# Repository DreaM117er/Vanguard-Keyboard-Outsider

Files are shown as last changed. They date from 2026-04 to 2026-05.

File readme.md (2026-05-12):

# Vanguard Keyboard Outsider 先鋒二號局外者

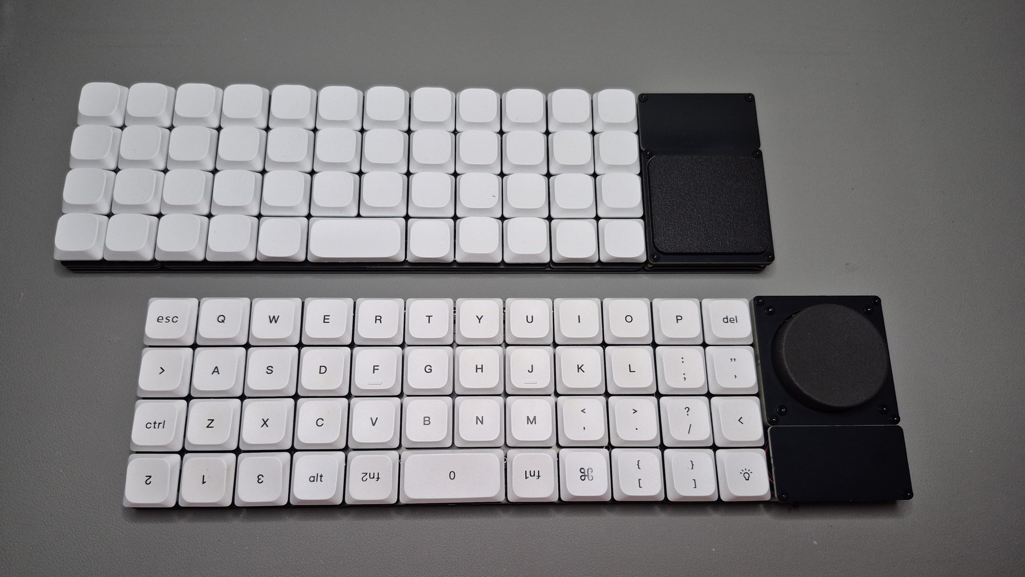
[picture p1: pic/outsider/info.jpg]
info


<br>

## 前言

「先鋒系列」是我個人基於「探索者三號」開發架構上的一個分支點，因爲在探索者三號的設計裡，在探索者三號的設計中，我將鍵盤主控區域「模組化」，使其觸控板與 `ProMicro` 主控模組能徹底沿用至後續作品。

- 爲什麼這把鍵盤是二號？

先鋒一號的代號叫做 `Mono`，中文代號叫做「雙子姐妹」，考慮到有人在敲碗 zmk 韌體的開發，因此我另開了一把鍵盤先嘗試研究 zmk，順勢做出一套屬於無線版的韌體，成功之後就會回頭將「一號」的開發完成。

——當然還有「探索者三號」的 `v2` 及無線韌體版本開發。

因爲是基於「探索者系列」，先鋒雖然比較侷限在「模組化」的區域做開發，但我不會捨棄掉「探索者」的自由度。相對的，這份自由反而讓我在開發的時候產生錯亂，算是一個小小的意外。

`Plank` 一直都是我非常喜歡的直列始祖，`3` 號也是基於 `Plank` 開發的鍵盤，我的想法很簡單：

——從最原始的開始，就一定會有更好的創意。

<br>

- 輔助搭配：
    - `about-zmk-XXX` 教學文本。
    - `QMK Firmware`：https://qmk.fm/
    - `VIAL`：https://get.vial.today/
    - `ZMK Firmware`：https://zmk.dev/
    - `KLE`：https://www.keyboard-layout-editor.com/#/
    - `nRF Connect SDK`：
        - `Android` 連結：https://play.google.com/store/apps/details?id=no.nordicsemi.android.mcp&pcampaignid=web_share
        - 電腦端：https://www.nordicsemi.com/Products/Development-tools/nrf-connect-for-desktop/download
        - 用於初次藍牙發射訊號捕捉除錯用。
    - `FreeCAD`。

<br>

## 硬體設計

### 自由度及限制

`Outsider` 被我設計成這種獨特的外型的樣子，其中最主要的原因就是「自由度」的保留，那麼它的自由度在哪裡？答案很簡單——

——它可以「任意」翻轉使用。

然後它是基於探索者三號的延伸設計，也就是說它的主控區域是沿用下來的，材料清單將註明哪些組件直接沿用「探索者三號」的設計圖資。

<br>

太極理論有「物極必反」的核心概念，任何的設計上也一樣，這把鍵盤給予了極致的自由度，它「目前」的限制列在下方：
1. 支援焊接。
2. 不支援 `Gateron Low Profile 2.0`，也就是 `GLP2.0`。
3. 觸控板只支援 `QMK` 有線版。

<br>

自由度的部分依據「限制」，列在下方：
1. 支援 `MX` 腳位的「鍵軸」，不限「矮軸」。
2. 支援 `GLP3.0` 矮鍵軸。
3. 支援 `Choc` 腳位的「鍵軸」。
4. 支援全電路板、外殼部件翻轉組裝。
5. 支援 `zmk` 編碼器無線版。
6. 支援 `qmk` `Azoteq TPS43` 及 `Cirque TM040040` 觸控板、編碼器有線版。
7. 支援多配列焊接調整。
8. 支援物理拆板組裝使用。

<br>

### 電路設計

#### 核心電路板

<table>
  <tr>
    <td width="100%">
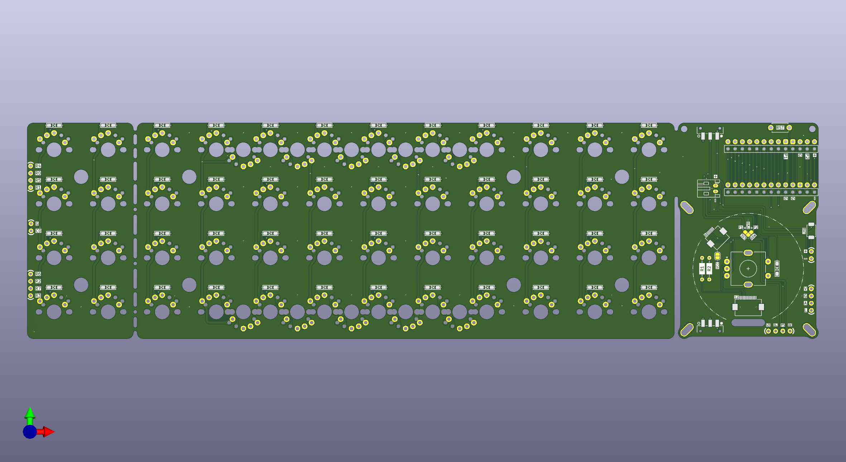
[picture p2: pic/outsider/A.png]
A
      
    </td>
  </tr>
  <tr>
    <td width="100%">
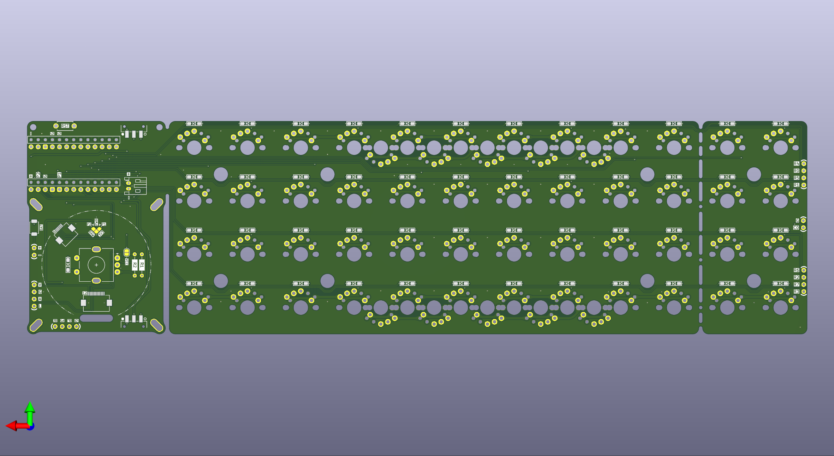
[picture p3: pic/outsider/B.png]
B
      
    </td>
  </tr>
</table>

<br>

#### 定位板、主控把擋板及底板

<table>
  <tr>
    <td width="50%">
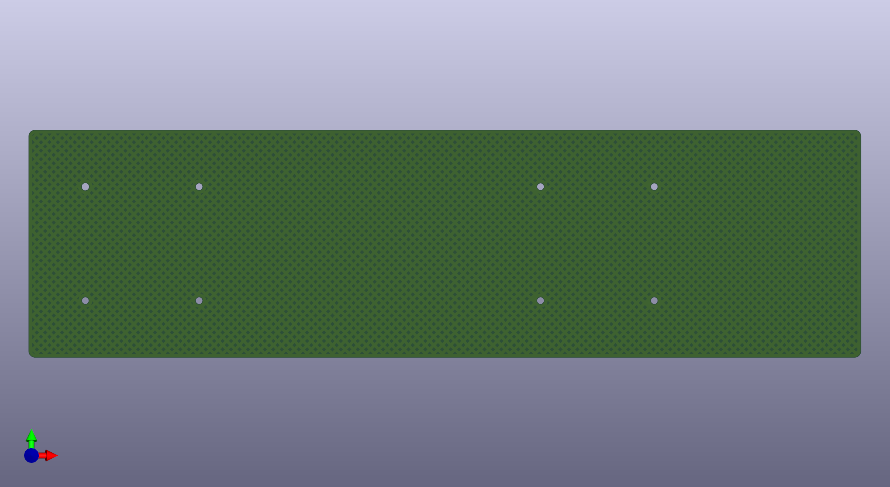
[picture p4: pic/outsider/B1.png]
B1
      
    </td>
    <td width="50%">
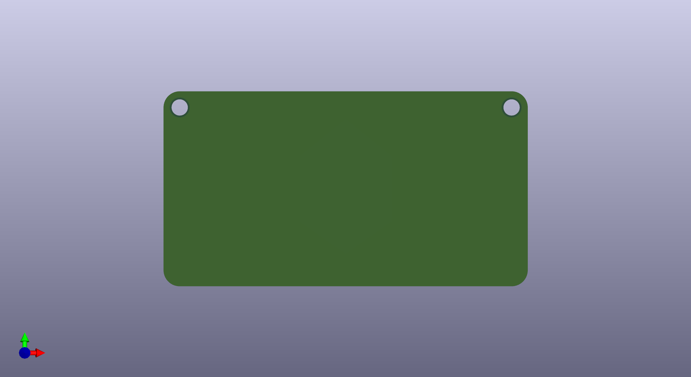
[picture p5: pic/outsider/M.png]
M
      
    </td>
  </tr>
  <tr>
    <td width="50%">
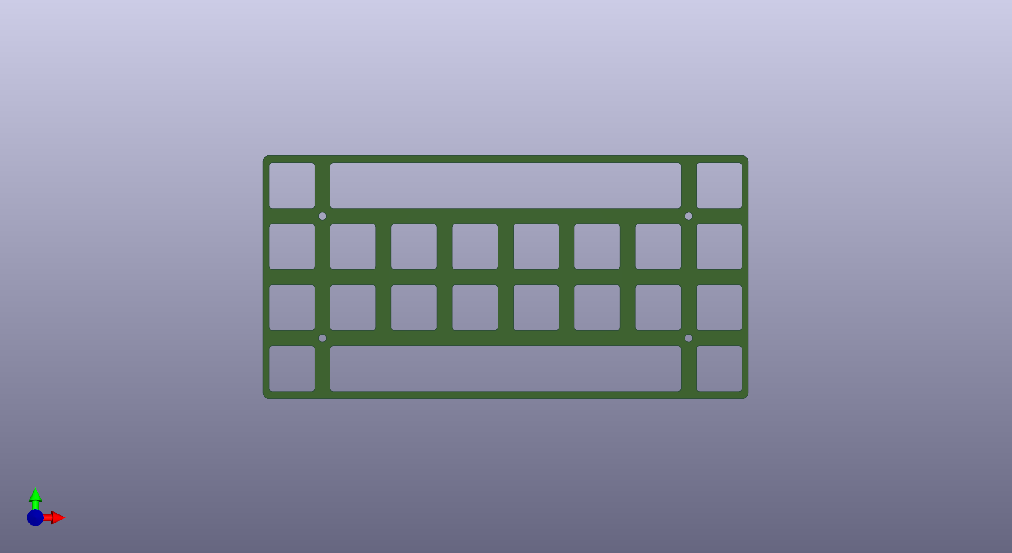
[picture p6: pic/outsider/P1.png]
P1
      
    </td>
    <td width="50%">
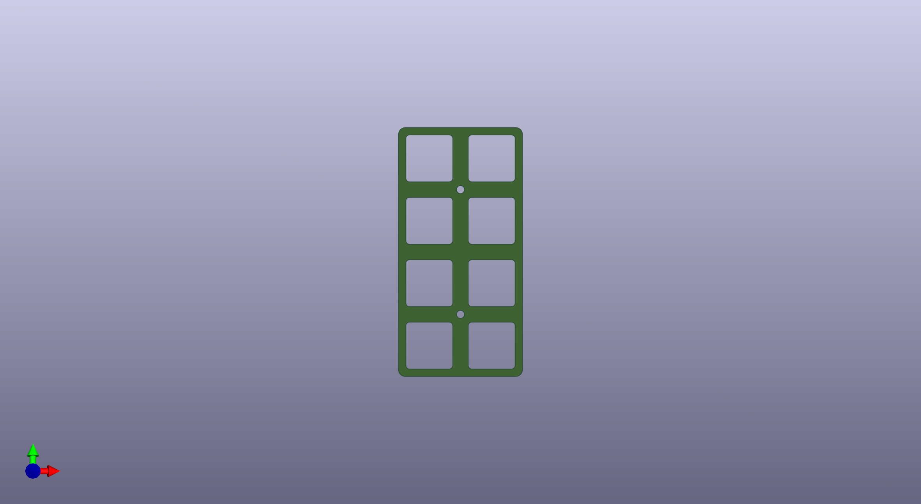
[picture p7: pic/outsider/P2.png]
P2
      
    </td>
  </tr>
</table>

<br>

#### 主控及模組

<table>
  <tr>
    <td width="50%">
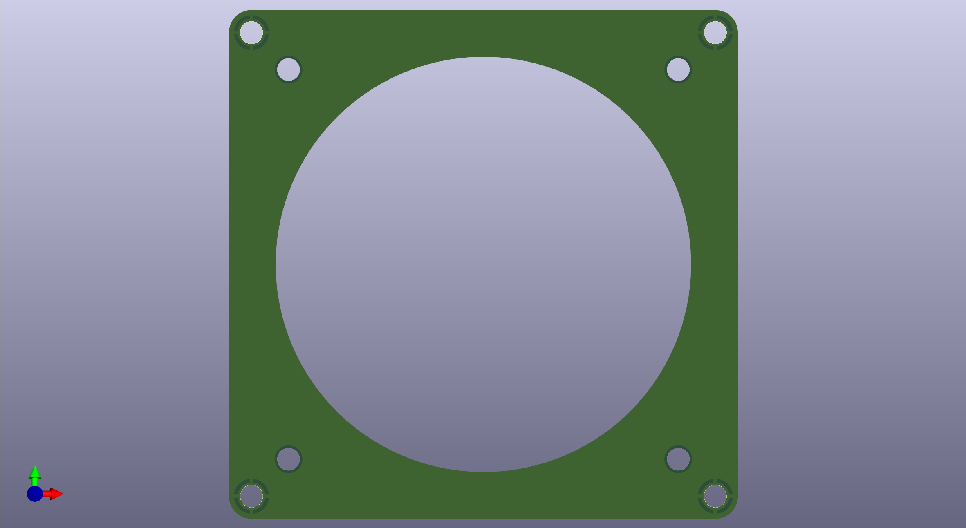
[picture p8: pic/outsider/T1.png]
T1
      
    </td>
    <td width="50%">
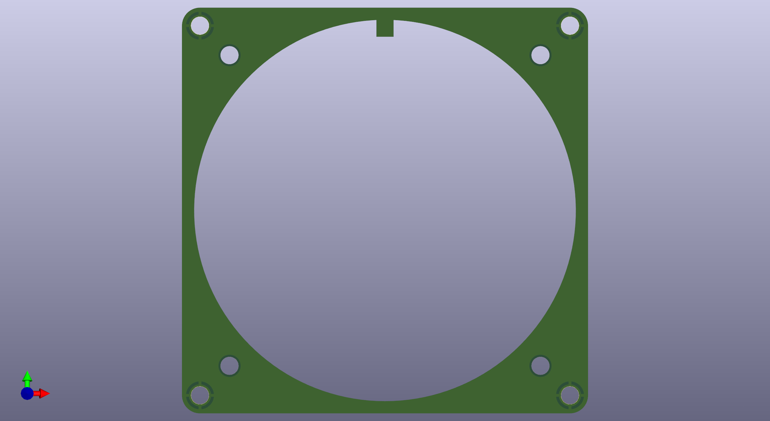
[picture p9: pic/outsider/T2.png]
T2
      
    </td>
  </tr>
  <tr>
    <td width="50%">
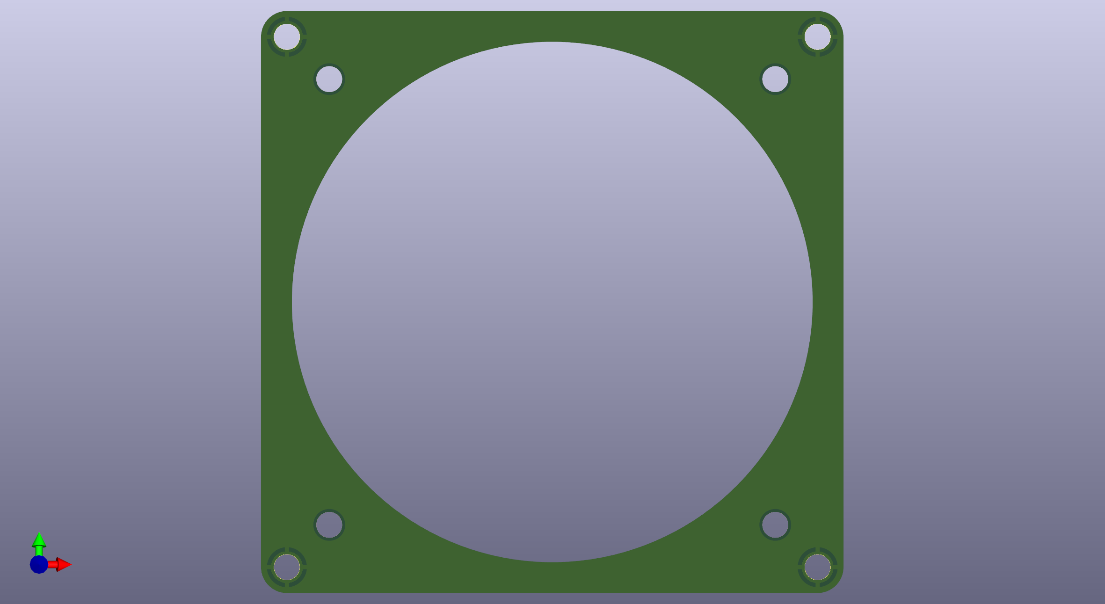
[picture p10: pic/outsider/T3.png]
T3
      
    </td>
    <td width="50%">
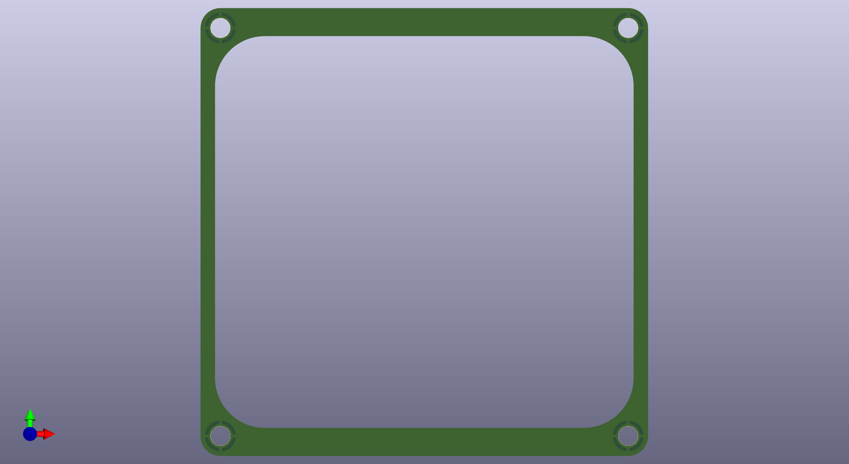
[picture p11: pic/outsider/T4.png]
T4
      
    </td>
  </tr>
</table>

<br>

#### 3D 部件

<table>
  <tr>
    <td width="50%">
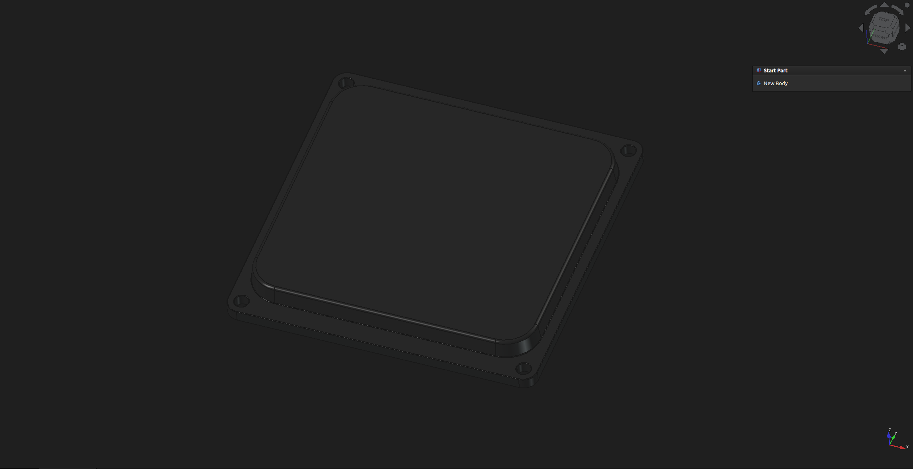
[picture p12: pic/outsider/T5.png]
T5
      
    </td>
    <td width="50%">
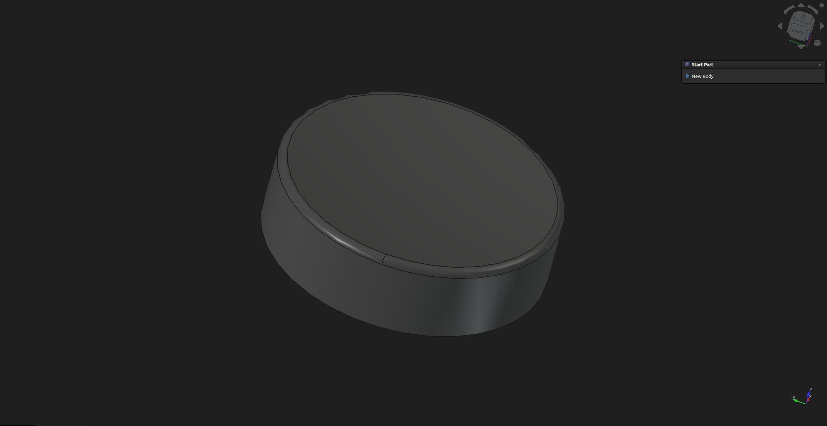
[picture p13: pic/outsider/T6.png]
T6
      
    </td>
  </tr>
</table>

<br>

## 使用材料

使用材料的部分比較簡單，`Outsider` 並沒有做過多的 `3D` 設計，一貫保留「三明治」結構。

||名稱|數量|數量||
|--|--|--|--|--|
|⚠️ **電路板**|**配列**|**4x10**|**4x12**|**備註**|
||主電路板|1|1|厚度 `1.2mm`|
||底板|1|1|厚度 `1.6mm`|
||`4x8` 定位板|1|1|**下方備註**|
||`4x2` 定位板|1|2|**下方備註**|
|`TM040040`|模組 `A`|1|1|**三號部件**|
|`TM040040`|模組 `B`|1|1|**三號部件**|
|`TM040040`|模組 `C`|1|1|**三號部件**|
|`TPS43`|模組 `D`|1|1|**三號部件**|
|⚠️ **主控**|**腳位**||||
|`ATMega32U4`|`ProMicro`|1|1|**基礎有線版**|
|`RP2040`|`ProMicro`|1|1|**有線觸控板**|
|`nRF52840`|`ProMicro`|1|1|**支援旋鈕無線版**|
|⚠️ **電子部件**|**名稱/規格**||||
|`1N4148`|`SOD-123`|40-41|48-49||
|`EC-11`/`EC-12`|`L10mm` `A4.5-5.0mm`|1|1|**選配**|
|輕觸開關|`6x3.5x4.3mm` `2 Pin`|1|1||
|輕觸開關|`SKRK` `2mm`|1|1|**選配**|
|撥動開關|`MSKT-12D14`|1|1|**選配**|
|小於 `501735`|`3.7V` 聚合物鋰電池|1|1|**選配，置於 MCU 上方**|
|-|`3.7V` 鋰電池電量顯示模組|1|1|**選配**|
|`PH2.0` `THT` 公母接頭|`JST PH S2B-PH-K`|1|1|**選配**|
|💡 **TM040040**|||||
|**名稱**|**規格**||||
|觸控板|-|1|1|**選配**|
|電阻|`1/4W` `4.7K`|2|2||
|排線|`0.5x5mm` `FFC 12pin` `AA`|1|1||
|排線座|`0.5mm` `FFC 12pin`|1|1|**不限翻蓋類型**|
|螺絲|`M2x3`|20|24||
|螺絲|`M2x6`|4|4||
|銅柱|`M2x5` `ø3.05-4mm`|6|8|**矮軸高度**|
|銅柱|`M2x6` `ø3.05-4mm`|4|4|**推薦高度**|
|銅柱|`M2x7` `ø3.05-4mm`|2|2|**有線主控**|
|銅柱|`M2x10` `ø3.05-4mm`|2|2|**無線主控**|
|💡 **TPS43**|||||
|觸控板|-|1|1|**選配**|
|排線|`0.5x5mm` `FFC 6pin` `AA`|1|1||
|排線座|`0.5mm` `FFC 6pin`|1|1|**不限翻蓋類型**|
|螺絲|`M2x3`|20|24||
|螺絲|`M2x6`|4|4||
|銅柱|`M2x5` `ø3.05-4mm`|6|8|-|
|銅柱|`M2x6` `ø3.05-4mm`|4|4||
|銅柱|`M2x8` `ø3.05-4mm`|4|4|**推薦高度**|
|銅柱|`M2x7` `ø3.05-4mm`|2|2|**有線主控**|
|銅柱|`M2x10` `ø3.05-4mm`|2|2|**無線主控**|
|📌 **3D 列印部件**|||||
|`TPS43`|觸控接觸面|1|1||
|`EC-11`|`ø39mm`, `L4.5mm` 編碼器帽蓋|1|1||
|📌 **其他**|||||
|自黏貼 `Poron` 棉|厚度 `2mm`|-|-||
|自黏貼矽膠腳貼|`ø8mm` `0.5-1mm`|4|4||

<br>

## 注意事項

### 零部件方面

- 如要安裝 `EC-11` 編碼器，請選擇支援 `TM040040` 的模組。

- 以上銅柱規格以「矮軸」配置為主；若使用標準 `MX` 軸，高度規格需全面調整至至少 `M2x7mm`。

- 定位板標準 `MX` 軸使用厚度 `1.6mm`；矮軸統一使用厚度 `1.2mm`。

- 鍵軸準備「至少」 `40` 或 `48` 顆以上，類型請根據自身喜好做挑選。

<br>

### 組裝方面

- 電烙鐵屬於高熱量操作技術，務必注意用電用火安全。

- 松香、焊錫屬於高毒性物質，務必注意環境通風。

- 操作時建議佩戴手套、口罩及護目鏡，以確保安全。

- 操作技術推薦：
  - 電烙鐵：恆溫控制攝氏 `250`-`330` 度間。
    - `K`。
    - `BC`。
  - 焊錫：攝氏 `183` 度。
  - 電線：
    - 規格至少 `24`-`28` `AWG`。
    - 顏色至少能清晰分辨 `2` 色。

- 操作工具：
  - 壓線鉗：
    - 需要能夠處理 `PH2.0` 規格。
    - 多準備一些金屬端子備用。
    - 先調整壓力卡楯，再做壓製動作。
  - 剝線鉗：
    - 用於鋰電池及其電量顯示模組使用。

- 觸控板選配：
  - `TM040040`：
    - 需要焊接 `4.7K` 電阻。
    - 需要自行移除觸控板上的 `R1` 電阻。
    - 教學參考：
      - [40mm Cirque GlidePoint Circle Trackpad Module DIY Kit for Split Mechanical Keyboard](https://shop.beekeeb.com/product/40mm-cirque-glidepoint-circle-trackpad-module-diy-kit-for-split-mechanical-keyboard/)
      - [GlidePoint Cirque Trackpad TM040040 TM035035](https://keycapsss.com/keyboard-parts/parts/211/glidepoint-cirque-trackpad-tm040040-tm035035)
  - `TPS43`：不需焊接電阻。

<br>

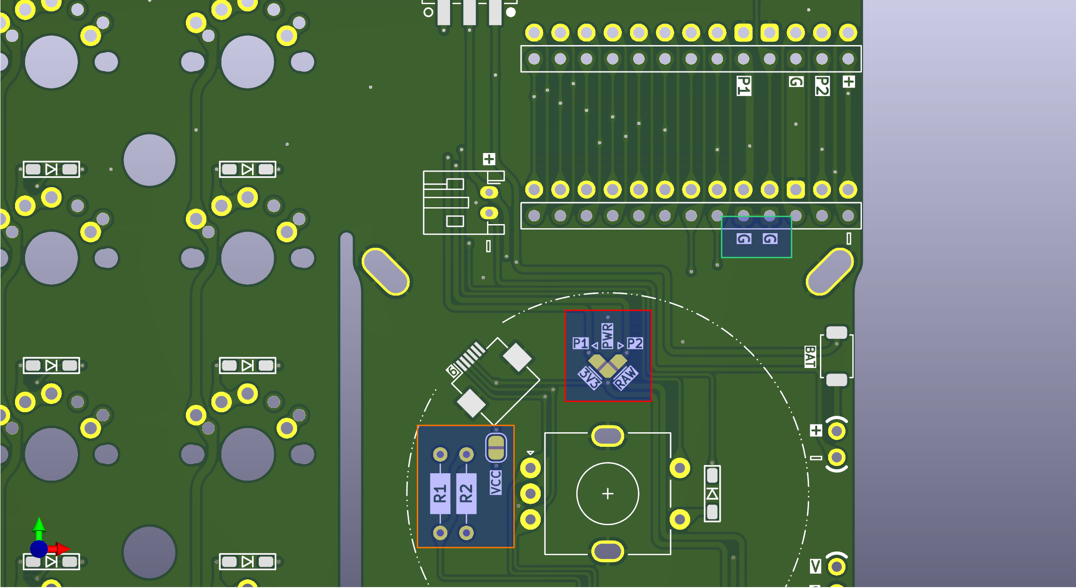
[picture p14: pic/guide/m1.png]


- 關於跳線：
  - 只需要焊接電路板其中一面即可。
  - `PWR`：
    - 一律根據 `MCU` 選擇 `3V3` 供電的位置。
    - 通常 `3V3` 都在 `P1` 的位置上。
  - `VCC`：
    - 使用跳線：組裝 `TM040040` 觸控板時焊上。
    - 不焊跳線：`4.7K` 電阻可不用解下就能將 `TM040040` 更替成 `TPS43`。

<br>

<table>
  <tr>
    <td width="50%">
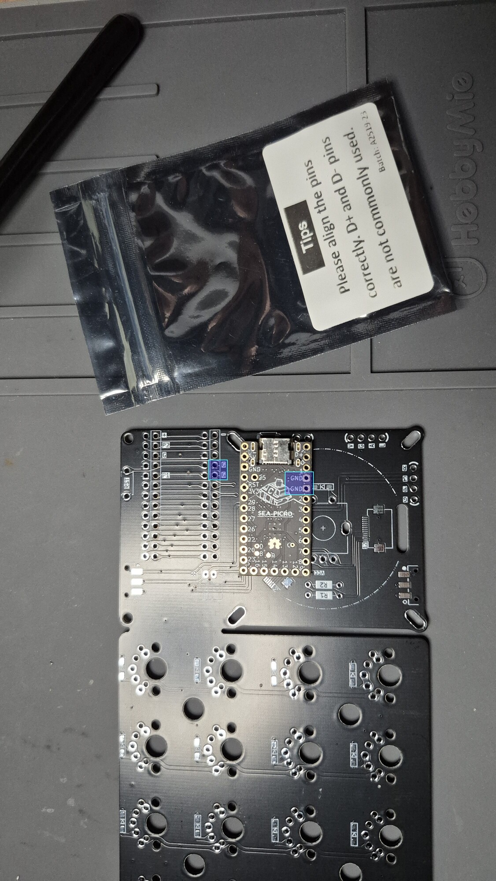
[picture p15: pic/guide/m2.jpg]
m2
      
    </td>
    <td width="50%">
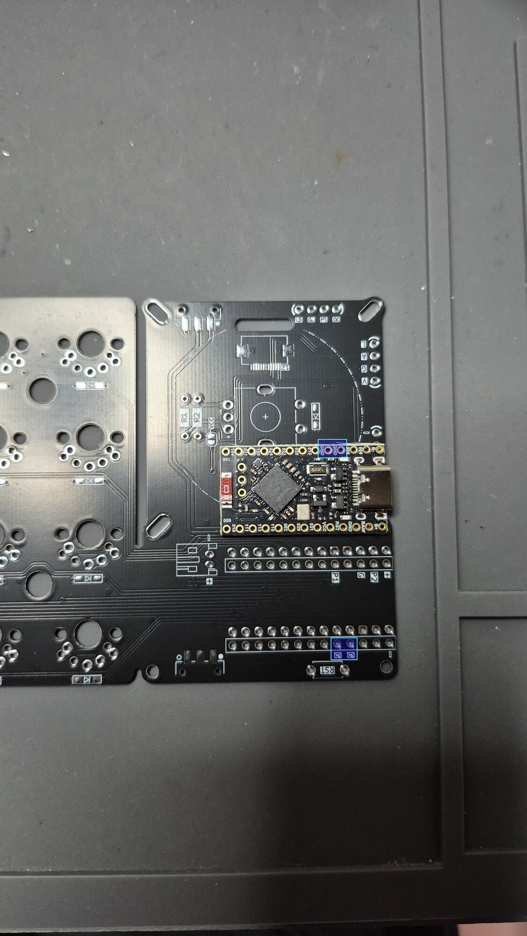
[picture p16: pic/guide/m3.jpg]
m3
      
    </td>
  </tr>
</table>

- 關於 `MCU`：
  - 根據 `MCU` 的腳位圖安裝。
  - 參照上圖「有 `2` 個 `GND`」的方向做判讀比較不容易裝反。

<br>

### 圖標辨識

<table>
  <tr>
    <td width="40%">
      <p>二極體有方向性。</p>
      <p>注意二極體前端的標線。</p>
    </td>
    <td width="30%">
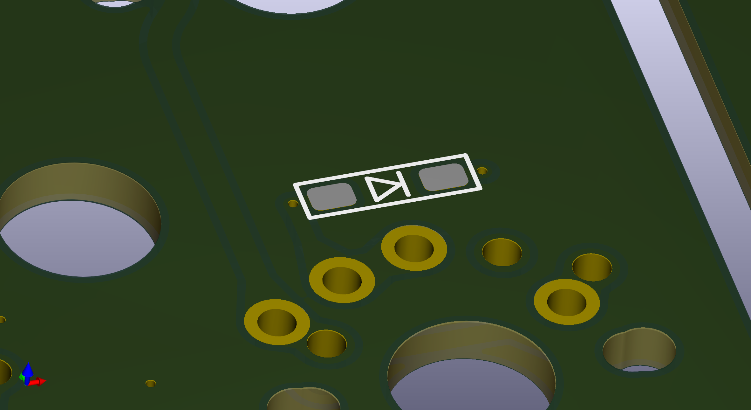
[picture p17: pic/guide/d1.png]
d1
      
    </td>
    <td width="30%">
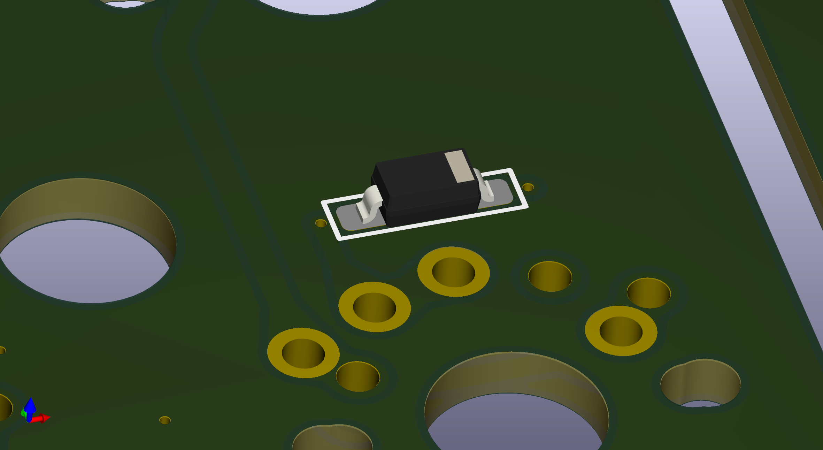
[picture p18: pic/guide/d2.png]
d2
      
    </td>
  </tr>
  <tr>
    <td width="40%">
      <p>電阻不分方向。</p>
      <p>電阻請跟「MCU」一樣安裝在同一面。</p>
    </td>
    <td width="30%">
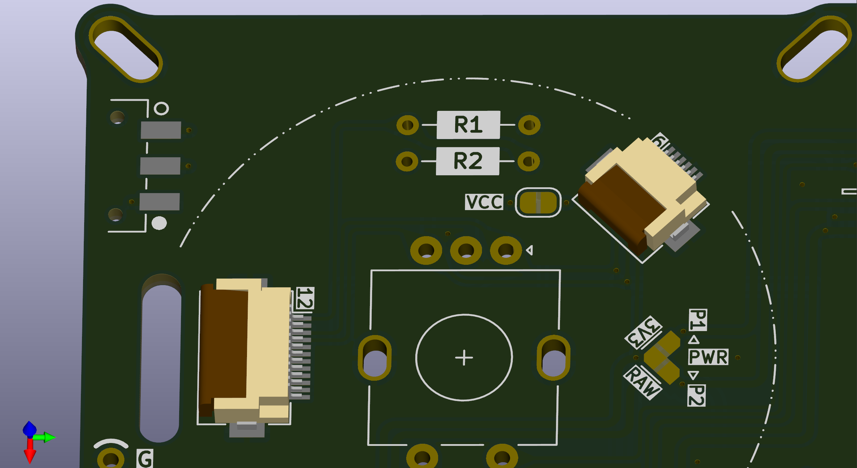
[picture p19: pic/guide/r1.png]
r1
      
    </td>
    <td width="30%">
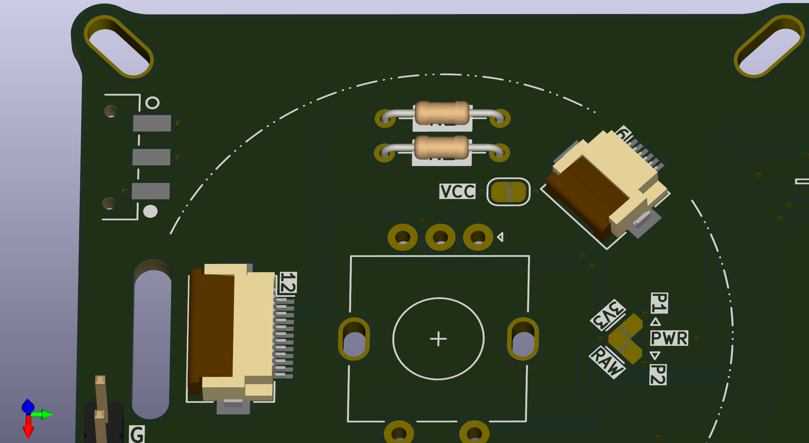
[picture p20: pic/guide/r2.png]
r2
      
    </td>
  </tr>
</table>

<br>

## 組裝方式

閱覽完前述規範後，進入實體組裝階段時，請特別留意以下具備挑戰性的環節：
- 焊接技術：
  - 溫度控制。
  - `3` 秒內原則。
  - `0.5mm` `FFC` 排線座。
- 除錯技術：
  - `0/1` 原則。
  - 防短路原則。

<br>

<table>
  <tr>
    <td width="38%">
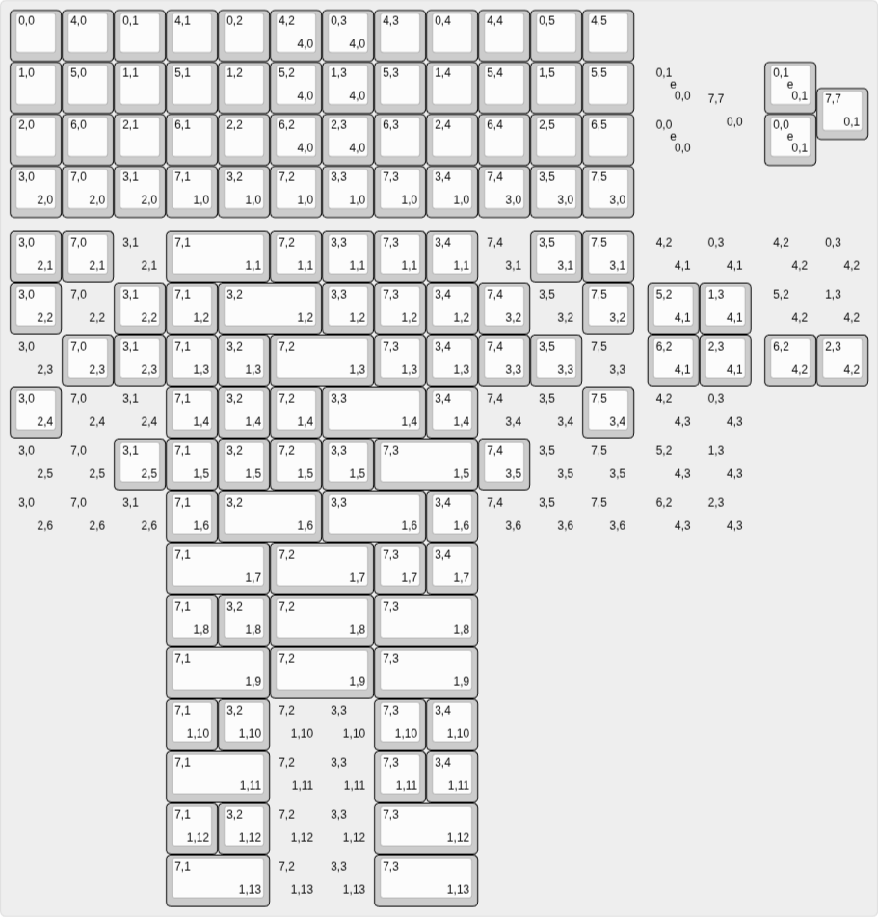
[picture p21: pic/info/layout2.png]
layout2
      
    </td>
    <td width="62%">
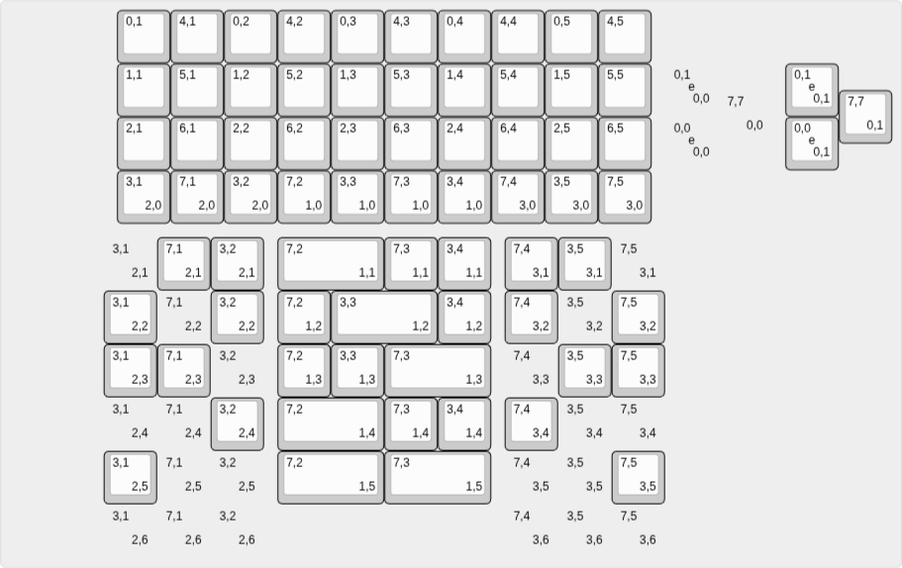
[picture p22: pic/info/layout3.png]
layout3
      
    </td>
  </tr>
</table>

<br>

拿出電路板，然後先思索一下：
  - 配列要長什麼樣子？
  - 鍵盤是有線還是無線驅動？
  - 我能搭載什麼設備？

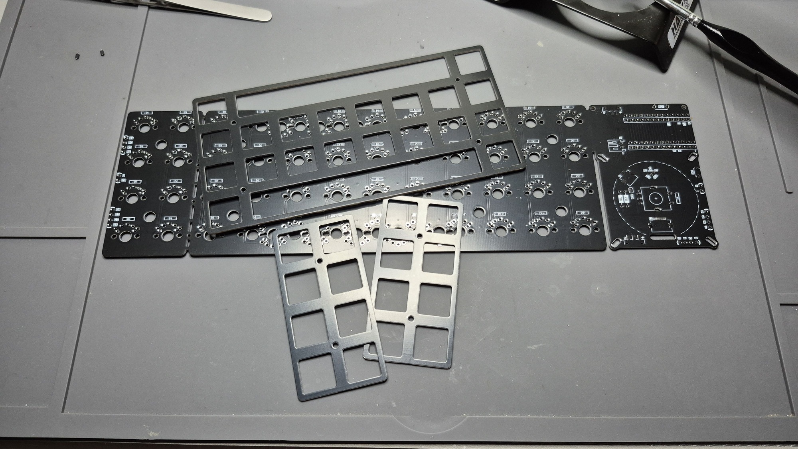
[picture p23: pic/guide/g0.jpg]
g0


<br>

以上問題思索完畢後，就可以開始進入正式組裝。

> 注意：以前我會傾向要大家先燒錄韌體到主控裡面，但這裡我必須做一些小修正。

<br>

### 共通部分

> 注意事項：部分照片有線及無線版本交互在一起使用，但不會影響安裝。

根據你的理想配列，首先將二極體焊上。

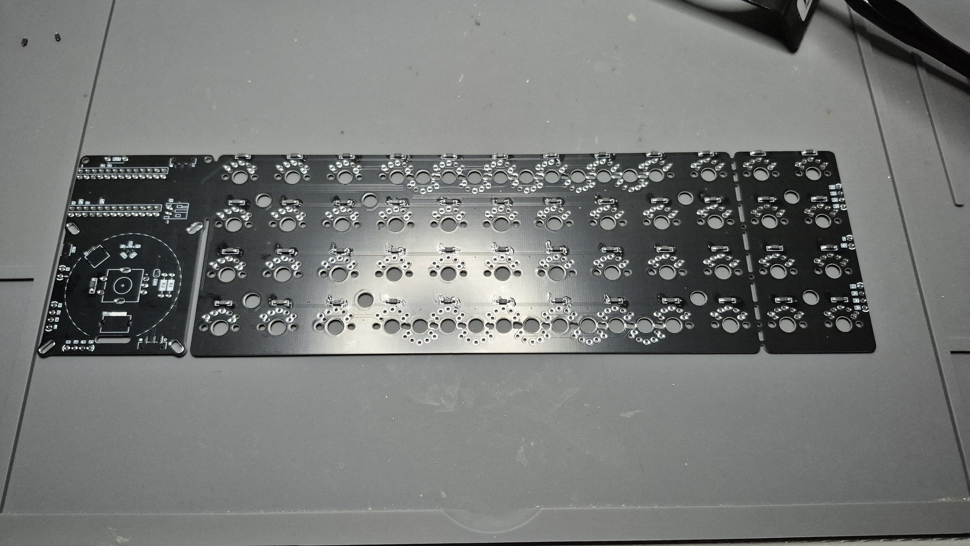
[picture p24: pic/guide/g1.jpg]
g1


<br>

然後將需要用到的週邊元件都焊上：
  - `EC-11` 或觸控板的 `FFC 排線座`、`1/4W 4.7K 電阻`。
  - 跳線。
  - `6x3.5x4.3mm` `2 Pin` 輕觸開關。
  - 無線版本：
    - `MSKT-12D14` 滑動開關。
    - `SKRK` `2mm` 輕觸開關。
    - `PH2.0` 母座。

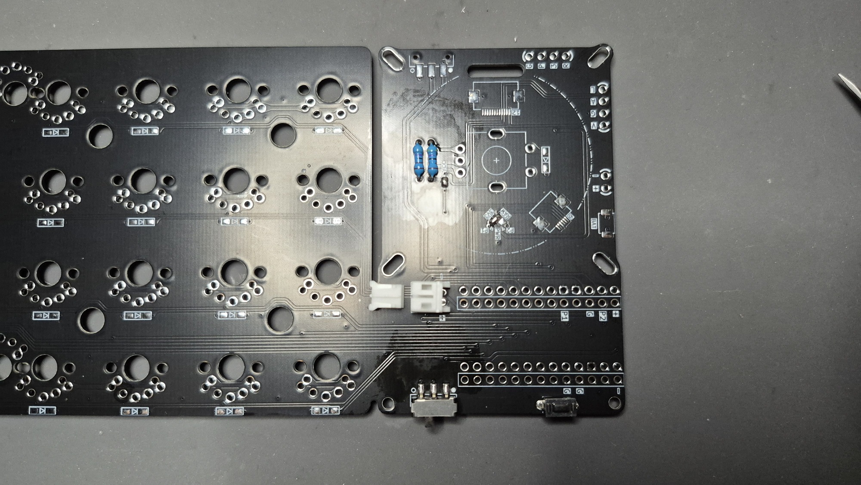
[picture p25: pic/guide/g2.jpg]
g2


<br>

根據你選擇的 `MCU` 來決定是不是要先燒錄韌體還是先焊上去。
- `RP2040`：
  - 大部分版本先做燒錄動作。
  - `Sea-Picro` 可以先焊接固定好之後再燒錄韌體。
  - 燒錄韌體的方式普遍爲「按住 `BOOT` 按鈕」後接上裝置後將 `uf2` 韌體燒錄到內部。
- `nRF52840`：
  - 先焊接固定好之後再燒錄韌體。
  - 接上裝置後，連續觸發「`2` 次」`RST` 按鈕，再將 `uf2` 韌體燒錄到內部。

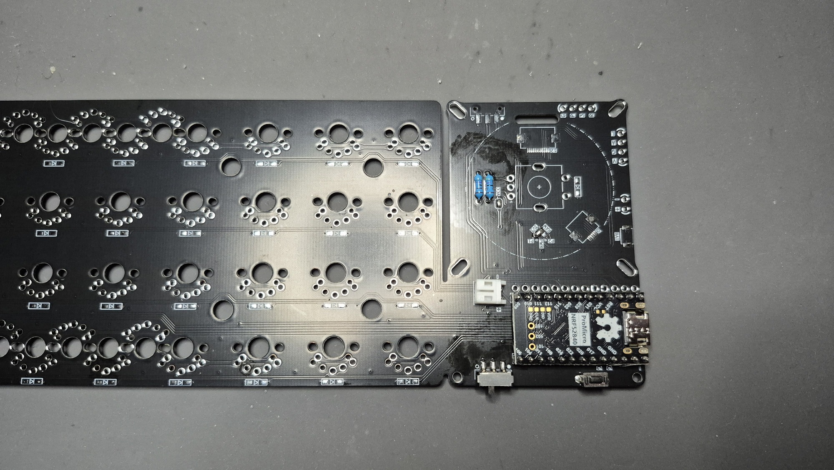
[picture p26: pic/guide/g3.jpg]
g3


<br>

`MCU` 焊接固定好、韌體也燒錄進去之後，下一步不要急著把軸體焊上去，你需要做幾件事情：
1. 確認你的鍵盤矩陣有沒有動，也就是你的按鍵有沒有全部都觸發。
  - `VIAL` 的 `Matrix Tester`。
  - `ZMK Studio`——`about-zmk-XXX` 教學文本會說明。
  - 第三方按鍵檢測器：https://hwtest.in/keyboard
2. 確認你的模組有沒有正常驅動。
  - `EC-11` 編碼器。
  - 觸控板的指向裝置韌體操作。

以上都沒問題，如果你是安裝觸控板，記得先把排線拔下來，再焊接軸體；如果是 `EC-11` 編碼器，就直接焊接軸體。

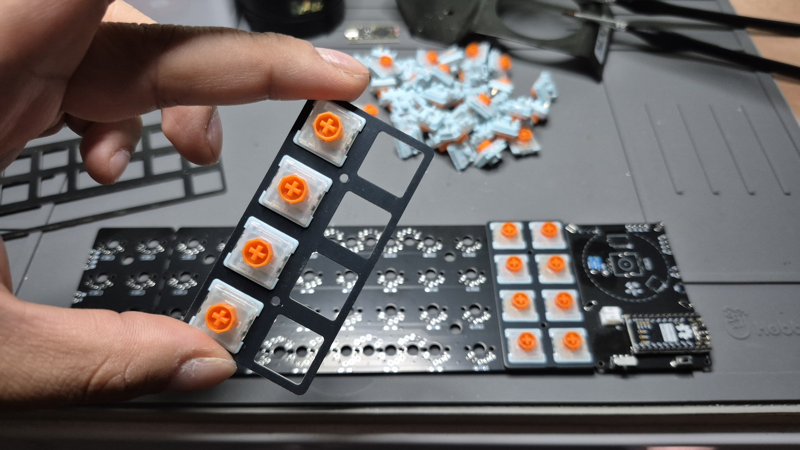
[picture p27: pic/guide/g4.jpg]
g4

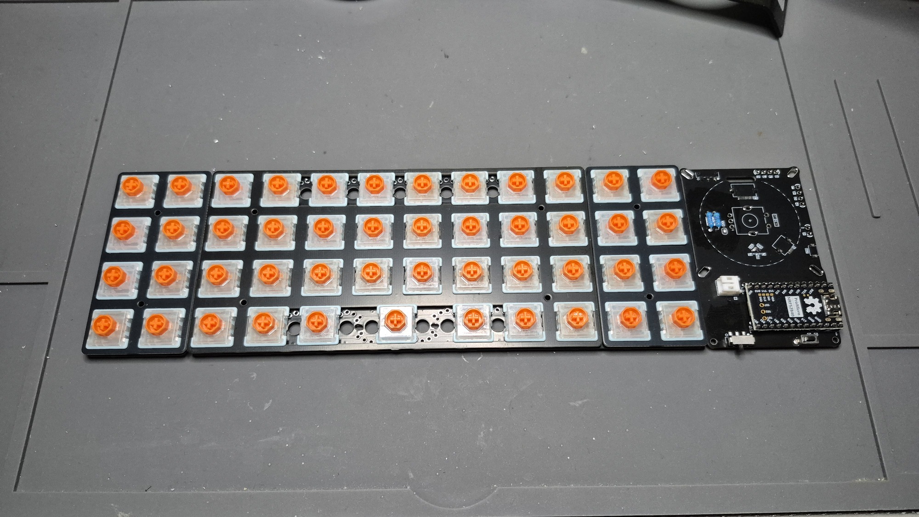
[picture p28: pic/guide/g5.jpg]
g5


> 注意事項：`EC-11` 可以不用焊接就直接裸測，我的照片示意圖裡就是這樣的操作。

<br>

### 觸控板

#### TPS43

`TPS43` 的部分，首先需要準備好「觸控面」、「模組 `D`（框架）」，先將 `TPS43` 上頭的 `3M` 膠帶撕下來，跟觸控面一起結合固定好。

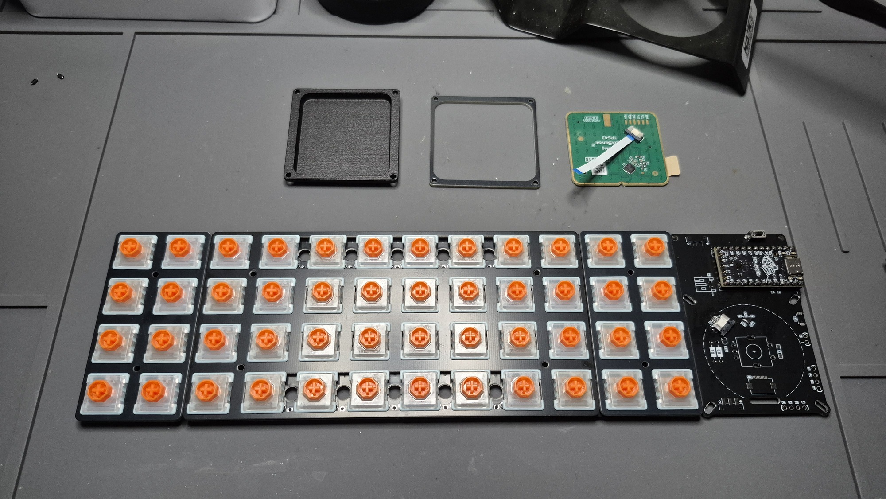
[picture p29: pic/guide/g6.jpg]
g6

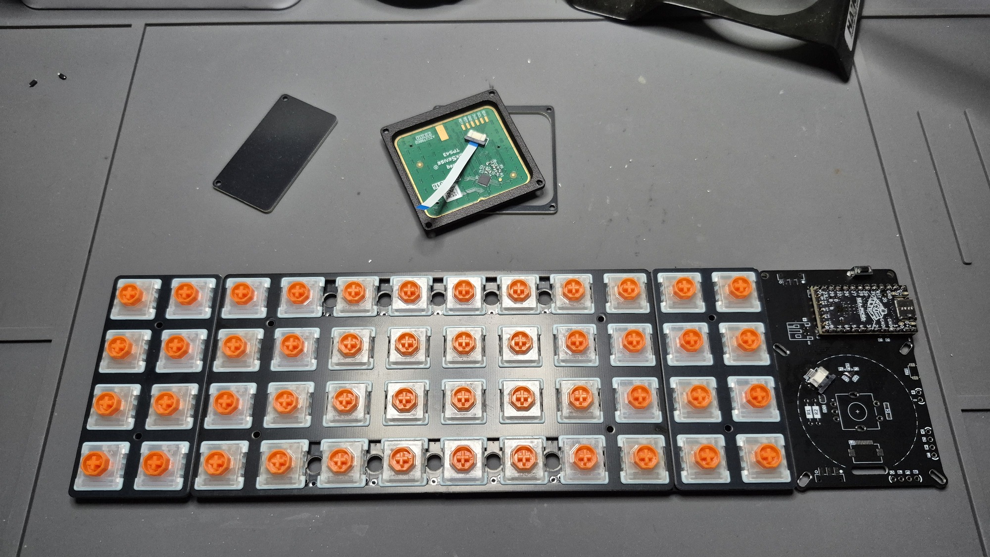
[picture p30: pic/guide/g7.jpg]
g7


<br>

將銅柱安裝在整套模組上之後，接上排線，然後將主控擋板連同模組一起固定好，就可以安裝底板收尾了。

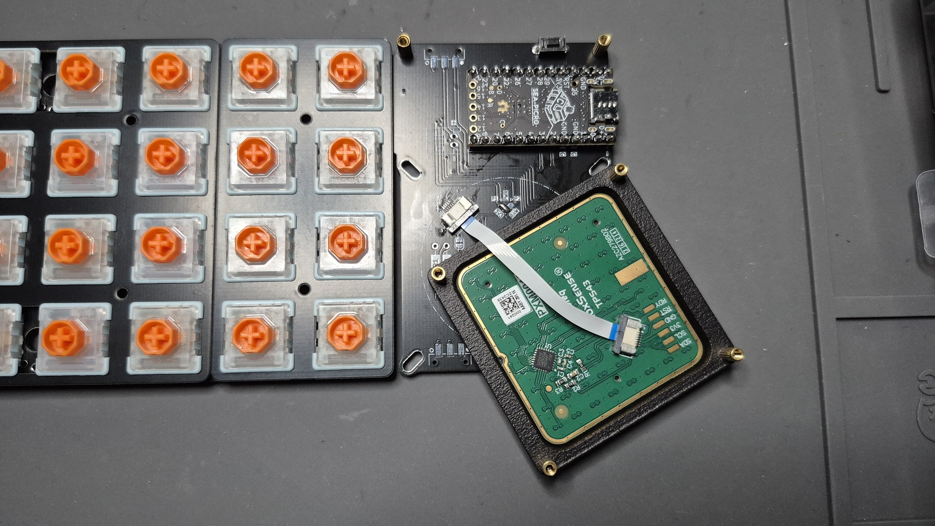
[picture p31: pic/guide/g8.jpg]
g8

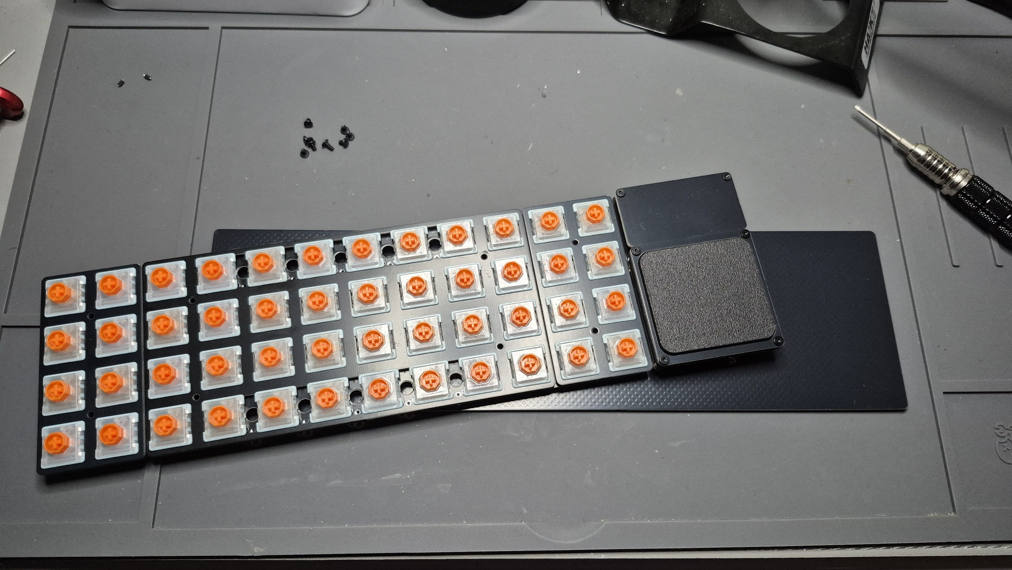
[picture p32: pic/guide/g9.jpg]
g9


<br>

#### TM040040

`TM040040` 的部分，需要將本體跟「模組 `A`、`B`、`C`」先組裝在一起，然後再安裝銅柱完成整套的模組。

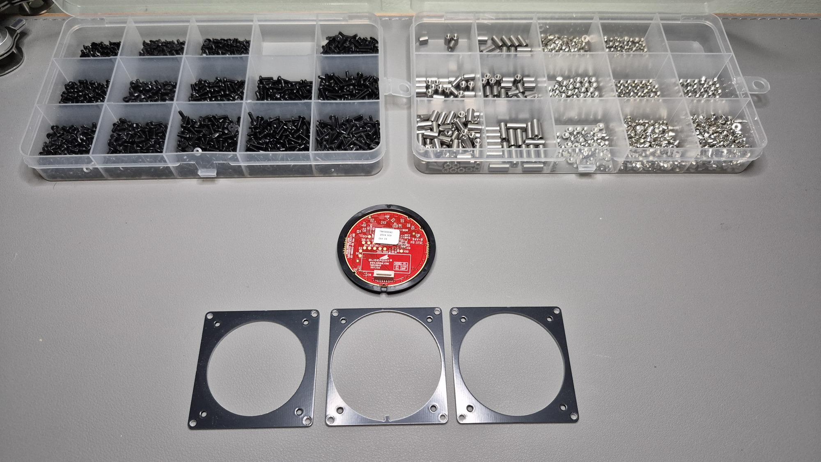
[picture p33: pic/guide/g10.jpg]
g10

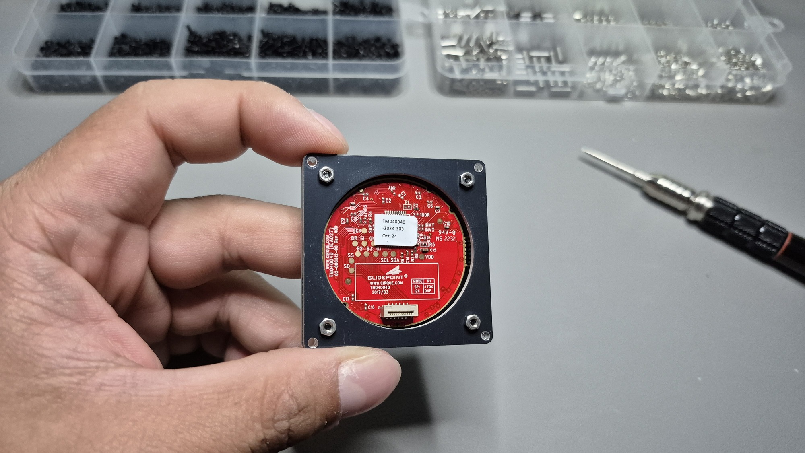
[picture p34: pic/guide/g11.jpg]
g11

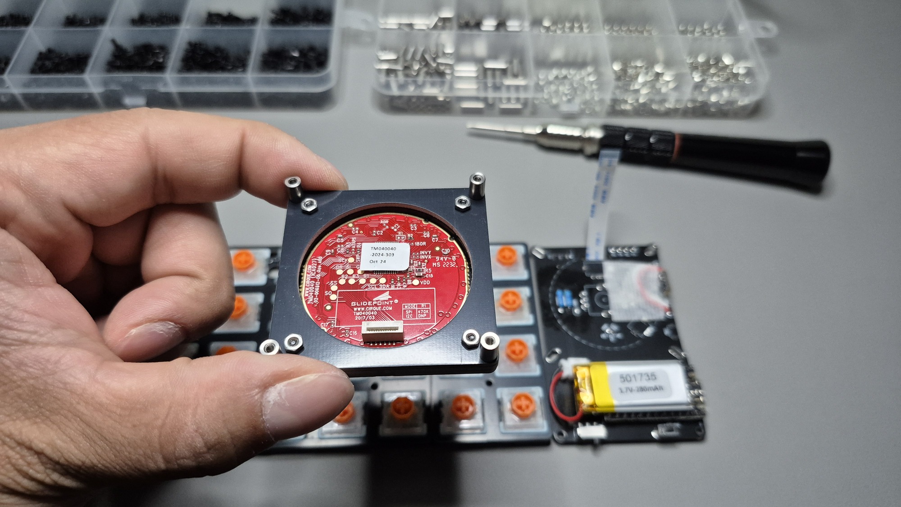
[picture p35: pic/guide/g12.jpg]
g12


<br>

`TM040040` 整套模組的安裝方式，要先將 `5mm` 排線接上，然後穿過洞口。

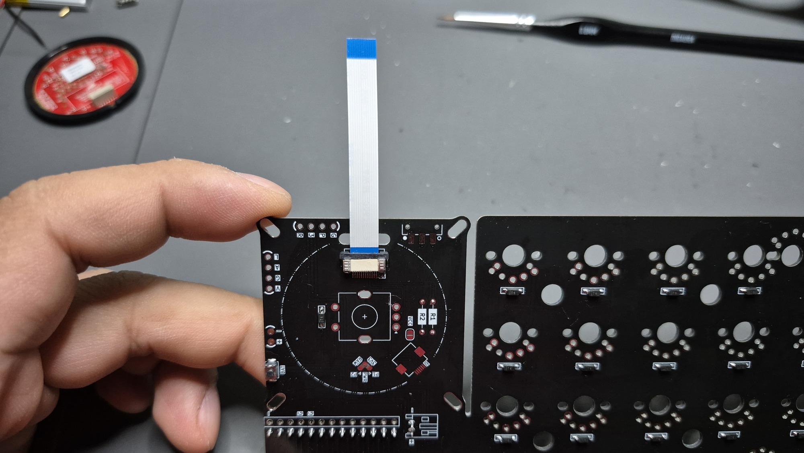
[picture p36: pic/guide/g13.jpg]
g13


> 最終完成安裝的示意圖會跟「教學」的完全一樣成「`S`」形。



<br>

### 關於電池

這裡開始會講述關於無線版本的一個很重要的一些事項：

#### 鋰電池

規格標註為 `501735` `3.7V` 聚合物鋰電池，其尺寸限制以能置於 `ProMicro` 主控上方區塊為準。

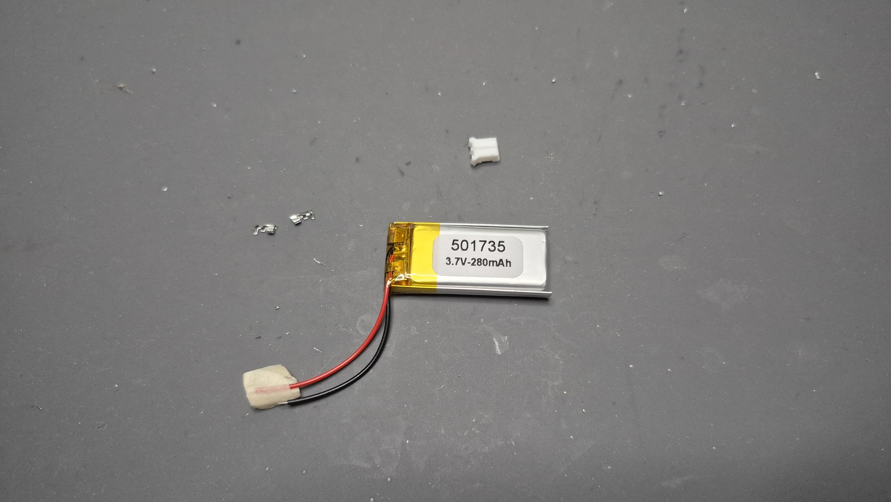
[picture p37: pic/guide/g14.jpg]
g14


> 注意事項：你的鋰電池通常拆封之後會做像這樣的絕緣處理，把絕緣的保護拿掉之後，特別注意不要讓這 `2` 根「正負極」碰觸在一起，會導致你的電池純粹地放電在電線上導致最終走火，處理它的時候務必小心。

<br>

首先你需要將 `PH2.0` 的金屬端子先壓制好，一樣確保「正負極」不會互相接觸，然後拿萬用電錶，切到「`20V`」檔位，直接測試「正負極」 查看：
1. 端子有沒有壓制成功。
2. 電池有沒有電。

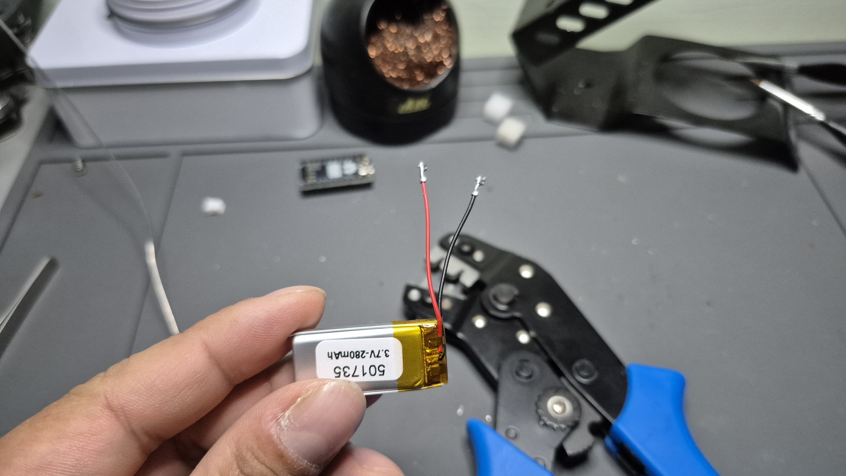
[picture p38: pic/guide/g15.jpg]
g15


<br>

確認沒問題，電有導通、電池有電之後，就可以將公頭安裝上去。

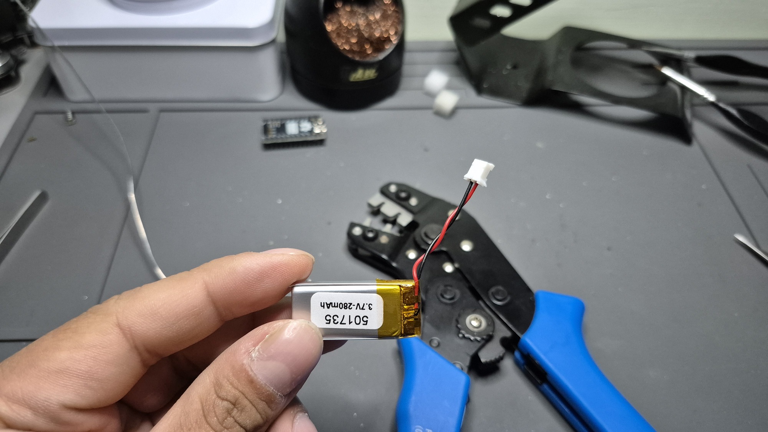
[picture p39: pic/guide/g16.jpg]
g16


<br>

#### 鋰電池電量顯示模組

`Outsider` 礙於沒有多餘的腳位可以去做 `LCD` 的電量顯示，因此只能「退而求其次」使用硬體操作的顯示模組，這個小東西在網路商城買上非常便宜，而且很好買，也不會缺貨。

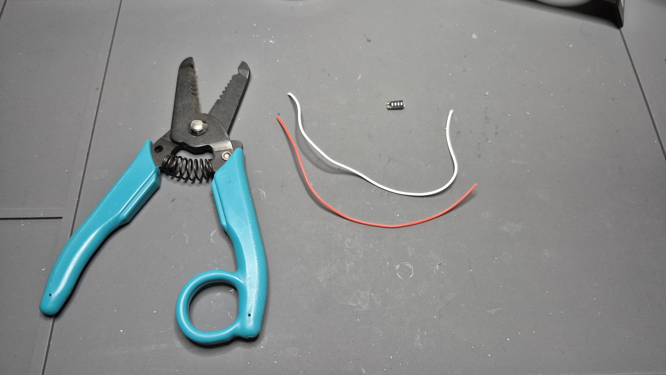
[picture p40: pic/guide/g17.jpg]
g17

g18

<br>

組裝方式很簡單，顯示模組的上頭有「`+`」、「`-`」標示，分別焊上容易辨識的電線，然後再接到電路板側邊對應位置的接口上。

> 操作及測試方式：
> 1. 滑動開關要先打開，這很重要。
> 2. 然後才能按下側邊的輕觸開關，這個時候顯示模組的電量才會亮起來。

<table>
  <tr>
    <td width="50%">
      g19
    </td>
    <td width="50%">
      g20
    </td>
  </tr>
</table>

<br>

最後將電池及顯示模組用膠固定好之後就完成安裝了。

g21

<br>

#### 底板及收尾

最後一步將銅柱安裝在底板上，然後將底板跟鍵盤主體固定好。

再將鍵帽裝上去就完工了。

<table>
  <tr>
    <td width="50%">
      e1
    </td>
    <td width="50%">
      e2
    </td>
  </tr>
  <tr>
    <td width="50%">
      e3
    </td>
    <td width="50%">
      info
    </td>
  </tr>
</table>

<br>

## 參考資料

- 主設計工具：
  - `Google Gemini`  協助。
  - `KiCAD v9.0.0`。
  - `FreeCAD`。
- 參考資料：
  - `Rotray Encoder` `EC10E`。
  - `Rotray Encoder` `EC11`。
  - `Cirque TM040040`。
  - `TPS43`-`TPS65-201A-B`。
  - `ProMicro nrf52840`。
  - `RP2040 ProMicro`。

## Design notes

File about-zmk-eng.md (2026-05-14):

# ZMK Firmware Environment Initialization Tutorial

## Preface

`zmk firmware` is the most well-known wireless keyboard firmware in the custom keyboard community, but it has always lacked a "complete" and "clean" environment setup process. Therefore, the moment I first entered `zmk`, I decided to simultaneously "execute" the environment setup and write down this "step-by-step" operation tutorial.

I am personally not an expert in the three major engineering fields of firmware, hardware, or circuit design. Thus, when approaching such a hardcore electronic project, I must definitely follow the official operation tutorials, combined with my own hands-on debugging attempts, to establish the execution `SOP` step by step. This is my "Open Source Spirit."

Of course, I will try my best to write the tutorial as plainly and detailedly as possible. I hope this tutorial text can perfectly integrate the "three major fields" I am familiar with, and deliver it to you, the reader, word for word, reducing some of the disappointment and frustration you might feel towards "open-source custom keyboards."

—After all, the excitement at the moment of lighting up your own keyboard is unparalleled.

(`DreaM117er`, Timestamp: `2026.05.09`)

<br>

## About This Tutorial

This tutorial text is suitable for the "following" audiences:
1. Complete beginners and novices.
2. Users whose computers are experiencing anomalies after following other online tutorials.
3. Users who successfully established a personalized environment following other online tutorials, but cannot find out how to solve encountered errors.
4. Engineers from the three major professional fields.

Operating environment of this tutorial: `Ubuntu`, `Mint`.
This tutorial is attached to the `Vanguard-Keyboard-Outsider` project, therefore it will borrow the design file belonging to that keyboard—`outsider.pdf`

<br>

## Differences Between qmk and zmk

The architecture of `zmk` is completely different from `qmk`—`qmk` uses a "Global Data Polling Mechanism," while `zmk` uses a "Tree-structured Data Encapsulation and Transmission Mechanism." We must understand the differences here:
1. The keyboard main controller "`MCU`" in `qmk` will periodically and sequentially "knock on the door" of the hardware to ask if anyone has been pressed or executed. At the same time, your "`Host`" will also periodically knock on the `MCU` to request data.
2. The `zmk` firmware uses `Zephyr RTOS`, an industrial-grade real-time operating system, to encapsulate your operations on a single keyboard into data and send it to the "`Host`." Therefore, even a split keyboard will be treated as a "single device," which is the same principle as connecting your "Bluetooth headphones."

> The "`Host`" explained here generally refers to the device being "connected or linked" to be "operated or controlled."

`Master`, `Slave`—which is the "primary" and "secondary" relationship of the devices. In `qmk`, you can freely choose to define "Left" or "Right"; in `zmk`, the default is usually based on "which side connects to the computer via Bluetooth" as the `Master`.

This makes it easier for everyone to understand the logic, and you will also more easily understand what the official `zmk` text is writing about.

<br>

## Creating a Local zmk Galaxy

### What is a zmk Galaxy?

1. First, you need to prepare your `GitHub` account and `fork` the official personalized configuration file to your project directory (e.g., `XXX-zmk-config`)
—[https://github.com/zmkfirmware/unified-zmk-config-template](https://github.com/zmkfirmware/unified-zmk-config-template)
2. Then operate the terminal, navigate to your default local `GitHub` repository directory, and execute the `zmk` installation process: [https://zmk.dev/docs/user-setup](https://zmk.dev/docs/user-setup)
3. When the installation process reaches `zmk init`, enter the `repo` URL of the `XXX-zmk-config` GitHub personalized configuration file you just created into `Repository URL`, and the system will help you set up the `config` directory.
4. Next, you can choose to enter `Y` to use an existing `zmk firmware` configuration file to change the `keymap` configuration for the keyboard you bought online.
5. If you choose `N`, execute `zmk cd` in the terminal to navigate to the default `config` folder directory.

Having executed up to here, we have successfully set up the "local" `zmk` galaxy environment. Next, I will let you understand the universe architecture of `zmk`, please continue reading below.

<br>

Currently, our `XXX-zmk-config` architecture diagram looks like this:

- `boards/shields`
    - The internal subfolders are the locations of all keyboards in the local `zmk` galaxy, which will be explained later.
- `config`
    - The folder sets the main rules of the galaxy, such as global variable settings, Bluetooth transmission power, deep sleep mode, etc.
    - The `west.yml` file is used to select which version of the `zmk` firmware you want to use for flashing.
    - `zmk.conf`.
- `zephyr`
    - `module.yml` is responsible for declaring to the `zephyr` compilation system that "this galaxy is an independent module."
- `build.yaml`
    - The command script for `GitHub Actions` (`CI/CD`) to consult, defining "who acts as whose master control, outputting as a `.uf2` firmware file."

<br>

## Prerequisites

### Installing Dependencies

If you are a pure novice wanting to enter `zmk`, you will overlook a lot of software engineering details. This is also what I discovered while writing the text. Here I will summarize them step by step:

1. Execute update in the terminal (different distributions have their own differences):

``` bash
sudo apt update
```

2. Install `Python3` and `pip3`:

``` bash
sudo apt install python3 python3-pip
```

3. Install `west`:

``` bash
pip3 install west
```

After mounting is complete, our XXX-zmk-config folder will look like this:

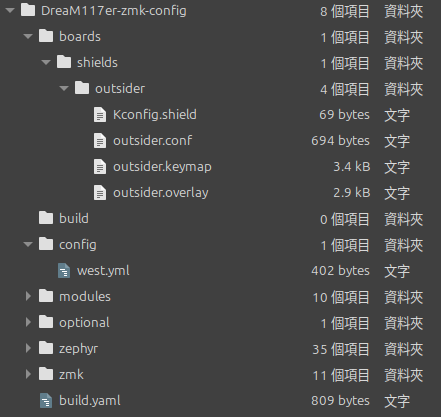
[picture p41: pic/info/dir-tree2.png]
dir-tree2


<br>

<br>

### Dependency Error Handling

If executing `pip3 install west` fails, please proceed as follows:

1. Install the virtual environment build tool:

```bash
sudo apt install python3-venv

```

2. Under the `cd` directory, create an isolated environment for `zmk-env`.

```bash
python3 -m venv ~/zmk-env

```

3. Activate the isolated environment, you will notice an extra `(zmk-env)` added to the front of your terminal.

```bash
source ~/zmk-env/bin/activate

```

4. Execute the `pip3 install west` command once more.

> Precaution: Every time you open the terminal and prepare to compile `zmk`, you must first execute `source ~/zmk-env/bin/activate` to activate the environment before you can use `west build`.

<br>

### Flashing Tool Setup

#### west.yml Configuration

I can't think of what to use as a subtitle, being straightforward is better: As mentioned earlier, "the `west.yml` file is used to select which version of the `zmk` firmware you want to use for flashing." I thought about it and still feel this part must be completed *before* "adding a new keyboard," otherwise, after all the firmware files are set up, you will be staring at your terminal waiting for a long time to flash the `uf2` firmware.

1. Execute `zmk cd`, enter the `config` folder, and open the `west.yml` file; it will present an architecture like this:

```yaml
manifest:
  defaults:
    revision: v0.3 # Change v0.3 to main
  remotes:
    - name: zmkfirmware
      url-base: https://github.com/zmkfirmware
    # Additional modules containing boards/shields/custom code can be listed here as well
    # See https://docs.zephyrproject.org/3.2.0/develop/west/manifest.html#projects
  projects:
    - name: zmk
      remote: zmkfirmware
      import: app/west.yml
  self:
    path: config

```

You will find that `revision` is mounted as `v0.3` by default; here we need to change this part to `main`, then save and close it.

2. Then open the terminal, and under the `zmk cd` folder, execute the `west update` command to declare to the `zmk` universe that I want to use `main` to directly flash the firmware.

```bash
zmk cd
west update

```

For the first time executing the `west update` command, just wait slowly for `git` to finish running it.

#### .gitignore Ignore List

After executing `west update`, the `west` manager will directly mount all the dependency packages of `zmk` from the `git` repository into the `XXX-zmk-config` folder, but it will not help you configure which files and folders need to be filtered out. If you forcefully execute `git push`, you will find that the dependency packages are all inside the `update list`, and warnings will pop up because the dependency packages are not files of a few `MB` in size, but several `GB`.

1. First, locate the `zmk cd` main folder, and then add `.gitignore`.

``` bash
zmk cd
touch .gitignore
```

2. Next, open `.gitignore`, copy the data list below into it, then save and close it.

``` .gitignore
# Ignore basic west and zmk
.zmk/
.west/

# Ignore all dependency packages downloaded by west
/zephyr/
/zmk/
/modules/
/optional/

# Ignore garbage and firmware files generated by local compilation
/build/

# Ignore Python virtual environment
/zmk-env/
.venv/
```

3. Execute the upload of the `.gitignore` ignore list.

```
git add .gitignore
git commit -m "add .gitignore in config setting"
git push
```

After the list is configured, executing `git push` will no longer report errors, unless you `compile` a new firmware, only then will there be new files listed in the `git` upload list.

<br>

#### Importing the Zephyr Engine

The function of `.gitignore` has already been mentioned above, so I won't repeat the explanation here.

What about the function of `west update`? Its purpose means "assisting you in moving several `GB` of pure text files (source code) from `GitHub` to your hard drive," but it does not possess the function to convert them into `uf2` firmware. Since `zmk` is an embedded system `OS` running based on `Zephyr RTOS`, we must mount its dependency packages:

* `CMake` / `Ninja`.
* `Python` libraries.
* `Zephyr SDK`.

<br>

1. Ensure your terminal environment is in a "compilable" state, and execute the "install `CMake` / `Ninja`" step:

> Note: `(zmk-env)`, `source ~/zmk-env/bin/activate`

``` bash
sudo apt install -y cmake ninja-build device-tree-compiler wget xz-utils
```

2. Lock onto the `XXX-zmk-config` folder and execute:

``` bash
zmk cd
pip install -r zephyr/scripts/requirements.txt
```

3. Register the `Zephyr` engine path with `CMake`:

``` bash
west zephyr-export
```

4. Install `Zephyr SDK` (`uf2` compiler):

```bash
cd ~
wget https://github.com/zephyrproject-rtos/sdk-ng/releases/download/v0.16.5-1/zephyr-sdk-0.16.5-1_linux-x86_64.tar.xz
tar xvf zephyr-sdk-0.16.5-1_linux-x86_64.tar.xz
cd zephyr-sdk-0.16.5-1
./setup.sh -t arm-zephyr-eabi -c
```

> Caution: After `setup.sh` is executed, it will automatically help you configure the `ARM` compiler, which is specially used to deal with the `nRF52840` chip.

#### Firmware Compilation

5. In this way, the entire `zmk` universe and compilation environment are fully mounted. If you want to create `uf2` firmware later, you must lock the folder to the `zmk/app` subdirectory under the `XXX-zmk-config` directory.

``` bash
zmk cd
cd zmk/app
```

Then execute the `west build` command:

``` bash
west build -p -b nice_nano -- -DSHIELD=<custom_keyboard> -DZMK_CONFIG="[Your XXX-zmk-config folder path]"
```

> Super important: The system will build the `uf2` firmware inside the `~/XXX-zmk-config/zmk/app/build/zephyr` folder, a file named `zmk.uf2`.

<br>

## Tutorial Begins

### A. The Birth of a Planet

After we have pioneered the `zmk` galaxy and completed all the prerequisite settings as mentioned above, this `zmk` galaxy is currently very clean and has nothing in it. We need to give birth to a new "planet" in this galaxy, which also corresponds to the operation methods of points `4-5` in "What is a zmk Galaxy?" above:

* Existing `zmk` universe settings, imported from the cloud to your computer (galaxy) for configuration modification.
* Creating a "new keyboard" from `0` (creating a planet in the galaxy).

Here I will not discuss the part about importing cloud settings; the focus is on the "new keyboard."

<br>

1. Execute `zmk cd`, then execute the following under the directory:

``` bash
cd boards/shields
mkdir <custom_keyboard>
touch Kconfig.shield <custom_keyboard>.overlay <custom_keyboard>.keymap <custom_keyboard>.conf
```

> First create the "planet (`dir`)", "flag (`Kconfig`)", "operating core (`.overlay`)", "functional core (`.keymap`)", and "Bluetooth settings (`.conf`)" files.

2. Then open `Kconfig.shield`, write in the code, and save:

``` markdown
config SHIELD_CUSTOM_KEYBOARD
    def_bool $(shields_list_contains,<custom_keyboard>)
```

The purpose of writing this string of code is: you need to tell your `zmk` universe environment that this `custom_keyboard` keyboard has been born.

> Simply creating the file is useless; if there is nothing inside your `Kconfig.shield` file, how are you going to tell the universe that "this keyboard" exists here?

<br>

### B. Operating Core and Function Setup

After setting the keyboard's "flag," only then will we sequentially create the "operating core" and "functional core." That is, you must first define what method your keyboard uses to drive the `zmk` firmware, and subsequently, build up the keyboard's functions step by step.

Currently, there shouldn't be a need to specifically explain the driving methods, there are only 2 types:

* Development board driven (e.g., `PICO-W` or `SEED XIAO-BLE` series).
* `MOB` driven (`MCU on board`).

Here I will introduce the commonly used development board drive, which uses the `nRF52840` chip development board (including `nice!nano v2`) as an example for introduction. First, we need to prepare a few things:

1. The development board itself.
2. Development board specifications and pinout definition table.
3. Keyboard circuit board schematic (`PDF` file or design drawing).
4. Actual keyboard matrix diagram (`KLE` or design drawing).

<br>

#### Development Board, Specifications, and Pinout Definition Table

<table>
  <tr>
    <td width="50%">
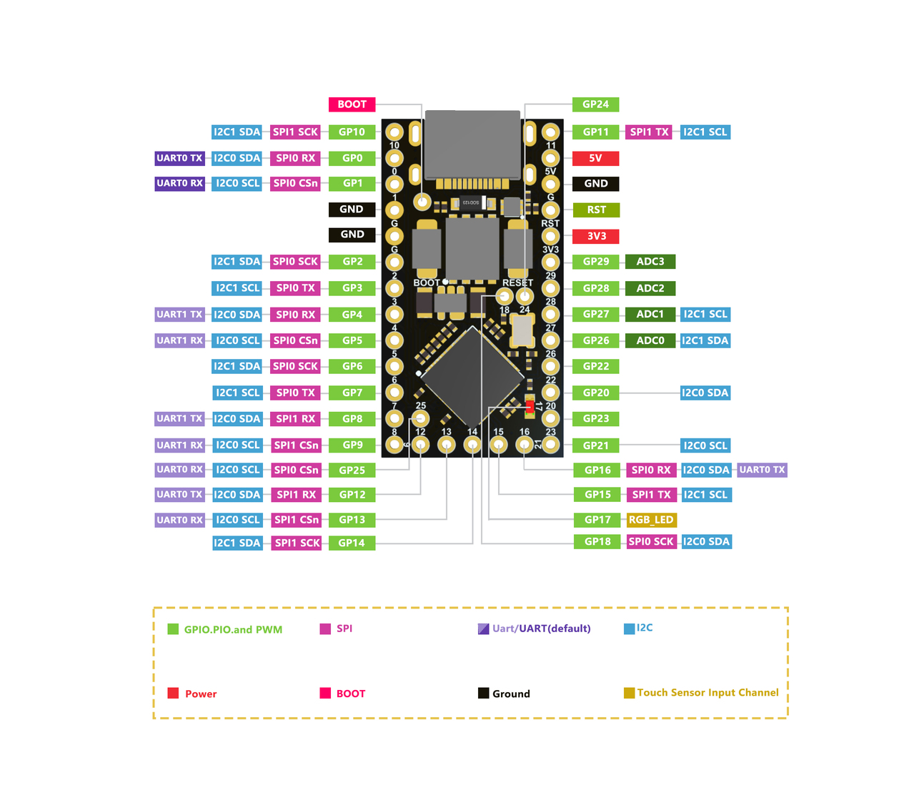
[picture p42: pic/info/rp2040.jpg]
rp2040
      
    </td>
    <td width="50%">
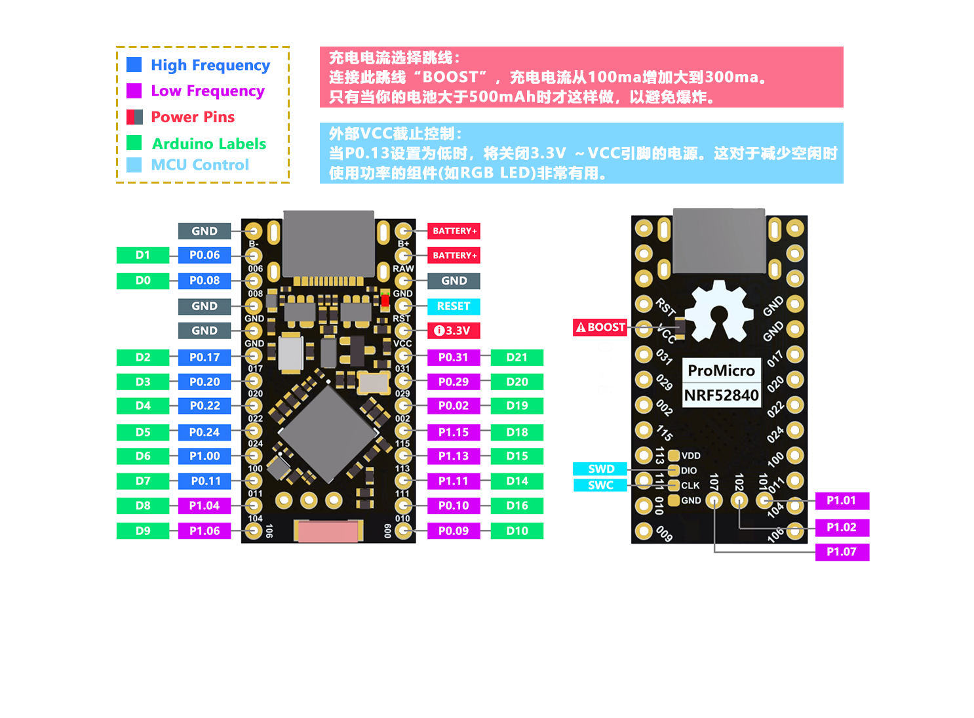
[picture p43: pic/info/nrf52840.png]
nRF52840
      
    </td>
  </tr>
</table>

For standard development boards using `ProMicro` footprints, assuming you want to develop a circuit board (`PCB`) shared for both wireless and wired use, then you will definitely use this pinout diagram. Here are a few of the most commonly used functions from these two diagrams:

* Cross-referencing the `GPIO` distribution on the front and back.
* Globally cross-referencing what function each `GPIO` has.

> Pay special attention to the positions and magnitude values of "Voltage (`VCC`)" and "Ground (`GND`)". This is extremely important in circuit design; using the wrong design method can damage your development board and circuit board.

> The biggest difference between `nice!nano v2` and `clones` is reflected in the magnitude of "`VCC`". If I remember correctly, the `VCC` output of early `nice!nano` development boards was `4.3V`, not `3V3`.

Let everyone know a few very simple concepts in circuit design:

* If the output voltage is wrong, it will go on strike, or burn out.
* If the wires are not connected correctly, it will go on strike, or burn out.

> Incorrect = strike or burn out.

It's just that simple.

<br>

Although we are not discussing the `RP2040 ProMicro` development board here, I still need to explain to everyone "why" I am bringing out a wired keyboard development board.

1. You need to know the actual physical locations and voltage values of `VCC` and `GND`.
2. Which `GPIO` the identical `I2C` communication channels are located on; for example, the locations of `I2C0` `SDA`/`SCL` are on `GP0-1`.
3. Likewise, which `GPIO`s the `SPI` communication pins are located on. Taking the `SPI` channel will cost more `GPIO`s to process communication data.

> You need to take the `GPIO` pins of the wired development board and cross-reference them with the pins of the `nRF52840 ProMicro` development board to see if there is an "intersection" of functions, and then prioritize extracting those pins for layout design.

The pins and functions of the `nRF52840 ProMicro` and `nice!nano v2` both adopt the same design method (different components used):

* Output voltage `3V3`, `GND` position is the same as the `RP2040 ProMicro`.

> Very important: All full-function pins can output `I2C` communication. Although all full-functions can, it is recommended to prioritize using the `SDA/SCL` pins marked by default on the development board to reduce the trouble of software definition.

> Very important: `RAW` is the interface for the battery's "positive pole".

<br>

#### Circuit Board Schematic and Actual Matrix Diagram

<table>
  <tr>
    <td width="50%">
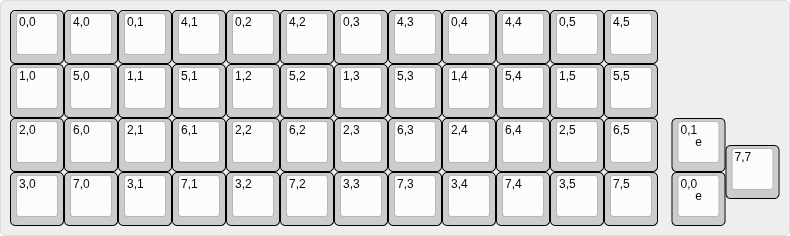
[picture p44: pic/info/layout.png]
layout
      
    </td>
    <td width="50%">
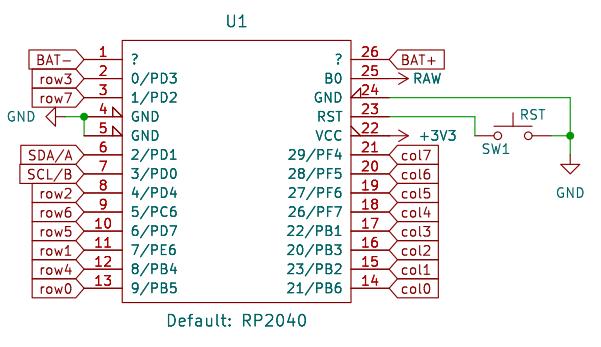
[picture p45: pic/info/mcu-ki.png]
mcu-ki
      
    </td>
  </tr>
   <tr>
    <td width="50%">
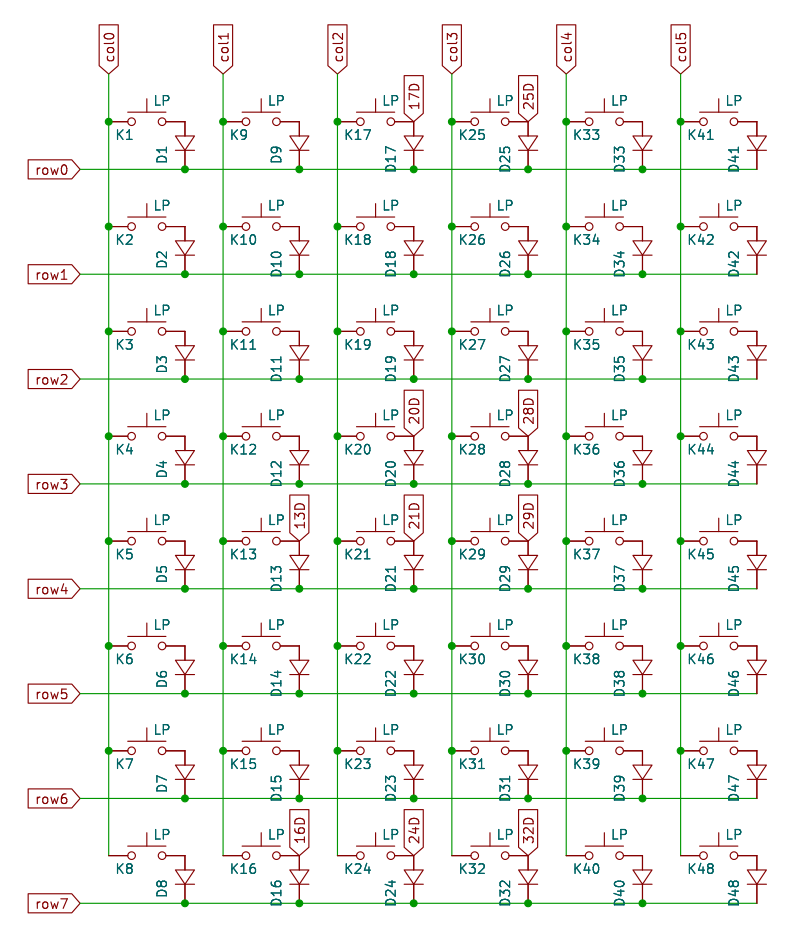
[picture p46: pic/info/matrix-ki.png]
matrix-ki
      
    </td>
    <td width="50%">
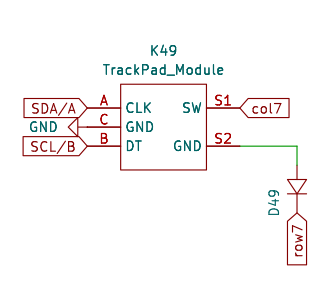
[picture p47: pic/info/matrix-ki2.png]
matrix-ki2
      
    </td>
  </tr>
</table>

Here, I will first explain two very common misconceptions:

1. Matrix size "does not equal" the actual matrix diagram.
2. Ideal matrix configuration "does not equal" the actual matrix configuration.

Taking the example `Outsider` keyboard, the keyboard matrix size for a standard `Plank` configuration is `4x12`. My design adds an extra floating key (volume encoder `EC-11`), so the total number of keys is `49`.

* The ideal matrix layout diagram will definitely be `4x12`, which is very reasonable, right?
* In reality, I designed an `8x8` matrix, totaling `64` keys, which is easier to design than a `7x7` matrix, and is also convenient for expansion and routing.

This should explain why, right?

<br>

#### Writing the Operating Core and Function Setup 

Whether in `qmk` or `zmk` firmware, the schematic and matrix diagrams are extremely important when writing configurations, because you need to physically cross-reference "your design" to write in the functions it should have, one by one.

1. First, we open `<custom_keyboard>.overlay`. The example for `Outsider` is below; you can modify your keyboard's `.overlay` file according to the comments.

``` c
#include <dt-bindings/zmk/matrix_transform.h>

/ {
    chosen {
        zmk,kscan = &kscan0;
        zmk,matrix_transform = &default_transform;
    };

    /* Development Board Settings */
    kscan0: kscan_0 {
        compatible = "zmk,kscan-gpio-matrix";
        label = "KSCAN";
        diode-direction = "col2row"; /* Set according to the keyboard's diode direction */

        /* Matrix Columns Pin Setup */
        col-gpios
            = <&pro_micro 10 GPIO_ACTIVE_HIGH> /* col0: PB6 */
            , <&pro_micro 16 GPIO_ACTIVE_HIGH> /* col1: PB2 */
            , <&pro_micro 14 GPIO_ACTIVE_HIGH> /* col2: PB3 */
            , <&pro_micro 15 GPIO_ACTIVE_HIGH> /* col3: PB1 */
            , <&pro_micro 18 GPIO_ACTIVE_HIGH> /* col4: PF7 (A0) */
            , <&pro_micro 19 GPIO_ACTIVE_HIGH> /* col5: PF6 (A1) */
            , <&pro_micro 20 GPIO_ACTIVE_HIGH> /* col6: PF5 (A2) */
            , <&pro_micro 21 GPIO_ACTIVE_HIGH> /* col7: PF4 (A3) */
            ;

        /* Matrix Rows Pin Setup */
        row-gpios
            = <&pro_micro 9 (GPIO_ACTIVE_HIGH | GPIO_PULL_DOWN)> /* row0: PB5 */
            , <&pro_micro 7 (GPIO_ACTIVE_HIGH | GPIO_PULL_DOWN)> /* row1: PE6 */
            , <&pro_micro 4 (GPIO_ACTIVE_HIGH | GPIO_PULL_DOWN)> /* row2: PD4 */
            , <&pro_micro 1 (GPIO_ACTIVE_HIGH | GPIO_PULL_DOWN)> /* row3: PD2 */
            , <&pro_micro 8 (GPIO_ACTIVE_HIGH | GPIO_PULL_DOWN)> /* row4: PB4 */
            , <&pro_micro 6 (GPIO_ACTIVE_HIGH | GPIO_PULL_DOWN)> /* row5: PD7 */
            , <&pro_micro 5 (GPIO_ACTIVE_HIGH | GPIO_PULL_DOWN)> /* row6: PC6 */
            , <&pro_micro 0 (GPIO_ACTIVE_HIGH | GPIO_PULL_DOWN)> /* row7: PD3 */
            ;
    };

    /* Matrix Size Setup */
    default_transform: keymap_transform_0 {
        compatible = "zmk,matrix-transform";
        /* Define matrix size */
        columns = <8>;
        rows = <8>;
        map = <
            /* Actual matrix size */
            RC(0,0) RC(4,0) RC(0,1) RC(4,1) RC(0,2) RC(4,2) RC(0,3) RC(4,3) RC(0,4) RC(4,4) RC(0,5) RC(4,5)
            RC(1,0) RC(5,0) RC(1,1) RC(5,1) RC(1,2) RC(5,2) RC(1,3) RC(5,3) RC(1,4) RC(5,4) RC(1,5) RC(5,5)
            RC(2,0) RC(6,0) RC(2,1) RC(6,1) RC(2,2) RC(6,2) RC(2,3) RC(6,3) RC(2,4) RC(6,4) RC(2,5) RC(6,5)
            RC(3,0) RC(7,0) RC(3,1) RC(7,1) RC(3,2) RC(7,2) RC(3,3) RC(7,3) RC(3,4) RC(7,4) RC(3,5) RC(7,5) RC(7,7)
        >;
        /* RC() format explanation: R = Row; C = Col; Combined code = RC(A, B) */
    };
};
```

> This part is setting up your hardware operating core, so you need to set it in the `.overlay` file, defining the core function "flag," "defining matrix size," and "actual matrix size" for every pin on the development board.

Then, after setting up the "operating core," only then will we set up the "functional core"—that is, "what functions" are on each key in your actual matrix.

> Supplementary note: `zmk` has a dedicated pinout definition table for development boards with `ProMicro` footprints. Please refer to the official documentation page here—https://zmk.dev/docs/troubleshooting/hardware-issues

ProMicro pinout

<br>

2. Next, open the `.keymap` file. This will also be where you spend the most time, because everyone's ideal key functions are different.

```c
#include <behaviors.dtsi>
#include <dt-bindings/zmk/keys.h>
#include <dt-bindings/zmk/bt.h>
#include <dt-bindings/zmk/pointing.h> // This part is the database for HID Device functions and key operations

/ {
    keymap {
        compatible = "zmk,keymap";

        // Layer 0: Base
        default_layer {
            display-name = "Default Layer";
            bindings = <
                &kp ESC   &kp Q     &kp W     &kp E     &kp R     &kp T      &kp Y     &kp U     &kp I     &kp O     &kp P     &kp BSPC
                &kp LSHFT &kp A     &kp S     &kp D     &kp F     &kp G      &kp H     &kp J     &kp K     &kp L     &kp SEMI  &kp SQT
                &kp LCTRL &kp Z     &kp X     &kp C     &kp V     &kp B      &kp N     &kp M     &kp COMMA &kp DOT   &kp FSLH  &kp RET
                &mkp RCLK &mkp LCLK &mkp MCLK &kp LALT  &mo 2     &kp SPACE  &kp RSHFT &mo 1     &kp RGUI  &kp LBKT  &kp RBKT  &to 2     &kp C_MUTE
            >;
        };

        // Layer 1: Lower
        lower_layer {
            display-name = "Lower Layer";
            bindings = <
                &kp TILDE   &none   &kp EXCL  &kp AT    &kp HASH  &kp EQUAL  &kp F1    &kp F2    &kp F3    &kp F12   &none     &kp DEL
                &kp LA(TAB) &none   &kp DLLR  &kp PRCNT &kp CARET &kp UNDER  &kp F4    &kp F5    &kp F6    &kp F11   &none     &trans
                &trans      &none   &kp AMPS  &kp STAR  &kp LPAR  &kp RPAR   &kp F7    &kp F8    &kp F9    &kp F10   &kp BSLH  &trans
                &trans      &trans  &trans    &kp LALT  &kp LGUI  &kp SPACE  &kp RSHFT &trans    &trans    &trans    &trans    &to 3     &trans
            >;
        };

        // Layer 2: Raise
        raise_layer {
            display-name = "Raise Layer";
            bindings = <
                &kp GRAVE &kp KP_DIVIDE   &kp N1 &kp N2    &kp N3    &kp PLUS   &kp PG_UP &kp HOME  &kp UP    &kp END   &kp C_VOL_UP &kp BSPC
                &kp TAB   &kp KP_MULTIPLY &kp N4 &kp N5    &kp N6    &kp MINUS  &kp PG_DN &kp LEFT  &kp DOWN  &kp RIGHT &kp C_VOL_DN &kp RET
                &kp LCTRL &kp DOT         &kp N7 &kp N8    &kp N9    &kp N0     &kp LBKT  &kp RBKT  &trans    &trans    &kp BSLH     &trans
                &trans    &trans          &trans &sk LALT  &kp LGUI  &kp RET    &kp RSHFT &trans    &trans    &trans    &trans       &to 0     &trans
            >;
        };

        // Layer 3: System/Control
        sys_layer {
            display-name = "System Layer";
            bindings = <
                &none        &none        &none        &kp INS  &kp SLCK &kp PAUSE_BREAK &none   &none   &none &none &kp PSCRN &none
                &kp CAPS     &none        &none        &none    &none    &none           &none   &none   &none   &none   &none     &none
                &none        &none        &none        &none    &none    &none           &none   &none   &none   &none   &none     &none
                &none        &none        &none        &none    &none    &none           &none   &none   &none   &none   &none     &to 0     &none
            >;
        };
    };
};
```

<br>

The `Keymap` above is the final layout code I mixed and matched specifically for the `Outsider` keyboard layout. Below, I will put the `keymap` comparison diagrams in `QMK`. Basically, for the wired keyboard firmware (`QMK`) and wireless keyboard firmware (`ZMK`) parts, you shouldn't have too much difference in designing the `Keymap`.

<table>
  <tr>
    <td width="50%">
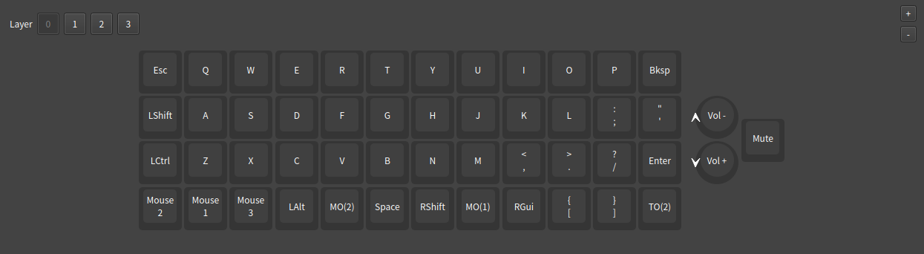
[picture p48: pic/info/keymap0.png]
keymap0
      
    </td>
    <td width="50%">
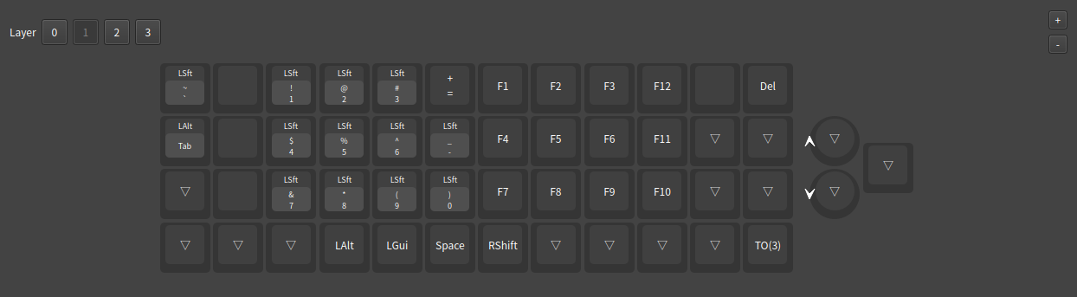
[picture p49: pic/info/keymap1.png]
keymap1
      
    </td>
  </tr>
   <tr>
    <td width="50%">
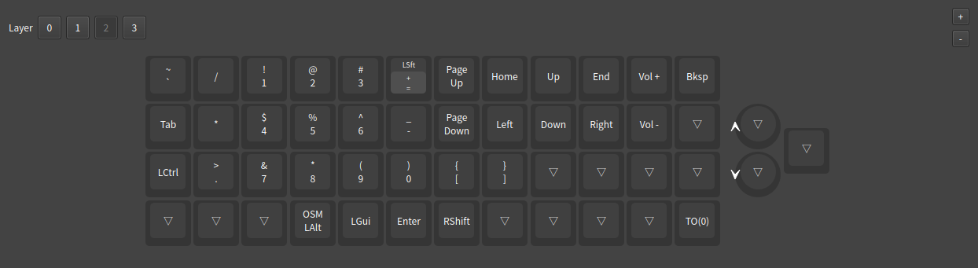
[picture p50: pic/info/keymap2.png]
keymap2
      
    </td>
    <td width="50%">
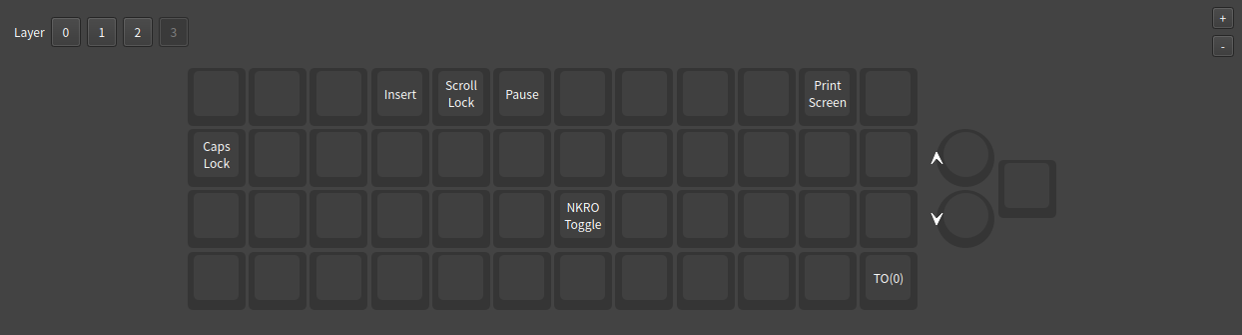
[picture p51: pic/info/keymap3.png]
keymap3
      
    </td>
  </tr>
</table>

<br>

As for what kind of layout and mixing patterns the entire keyboard should be made into, this is also a very time-consuming area. Assuming you don't have the need for multi-variable key positions, just skip this part.

<table>
      layout2
</table>

<br>

At this point, our local `zmk` folder architecture diagram will look like this:

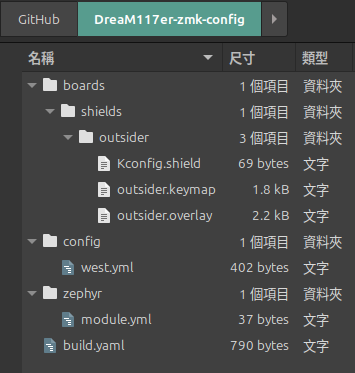
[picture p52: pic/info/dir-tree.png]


- `boards/shields`
    - The internal subfolders are the locations of all keyboards in the local `zmk` galaxy.
        - `Kconfig.shield` is the "flag" of the planet. If the inside is not configured, the planet does not exist.
        - The `.overlay` file explains the operating rules of the planet, such as how the core drives, how the water flows, etc.
        - The `.keymap` file defines what things are on the planet, such as what data will pop out to the computer after a key is pressed.
        - The `.conf` file is used for device connection settings, which will be mentioned later.
- `config`
    - The folder sets the main rules of the galaxy, such as global variable settings, Bluetooth transmission power, deep sleep mode, etc.
    - The `west.yml` file is used to select which version of the `zmk` firmware you want to use for flashing.
    - `zmk.conf`。
- `zephyr`
    - `module.yml` is responsible for declaring to the `zephyr` compilation system that "this galaxy is an independent module."
- `build.yaml`
    - The command script for `GitHub Actions` (`CI/CD`) to consult, defining "who acts as whose master control, outputting as a `.uf2` firmware file."

This way, the `zmk` folder has been comprehensively defined and parsed. Next time you are reading the official `zmk` text, it will be much easier.

> Supplementary note: Regarding the `#include <dt-bindings/zmk/pointing.h>` database, it belongs to the latest version of settings; the old version of `mouse.h` has been integrated in. If you are on the latest version, make sure to use `pointing.h` to make declarations.

<br>

#### Encoder Setup

Earlier we discussed how to set up the matrix part for standard buttons. Because the `Outsider` supports an encoder in its default hardware setup, here I will tell you how to set up the encoder's "Rotation" and "Pulse".

There is also a section regarding the setup of "Pointing Devices." Since the `Outsider`'s hardware also supports this, I will explain it in sequence.

1. First, we open the `.keymap` file, locate the `default_layer` block, and add the "rotation values" for the encoder.

``` c
... Omitted above.

/ {
    keymap {
        compatible = "zmk,keymap";

        // Layer 0: Base
        default_layer {
            display-name = "Default Layer";
            bindings = <
                &kp ESC   &kp Q     &kp W     &kp E     &kp R     &kp T      &kp Y     &kp U     &kp I     &kp O     &kp P     &kp BSPC
                &kp LSHFT &kp A     &kp S     &kp D     &kp F     &kp G      &kp H     &kp J     &kp K     &kp L     &kp SEMI  &kp SQT
                &kp LCTRL &kp Z     &kp X     &kp C     &kp V     &kp B      &kp N     &kp M     &kp COMMA &kp DOT   &kp FSLH  &kp RET
                &mkp RCLK &mkp LCLK &mkp MCLK &kp LALT  &mo 2     &kp SPACE  &kp RSHFT &mo 1     &kp RGUI  &kp LBKT  &kp RBKT  &to 2     &kp C_MUTE
            >;
            // Encoder A, B setup
            sensor-bindings = <&inc_dec_kp C_VOL_UP C_VOL_DN>;
        };

        // Layer 1: Lower

... Omitted below.
```

For a single encoder's rotation values, you need to copy the same `sensor-bindings` into every `Layer`.

If you want "different rotation values for each `Layer`", then you need to insert the corresponding `sensor-bindings` declaration at the bottom of each `Layer`.

```c
... Omitted above.

/ {
    keymap {
        compatible = "zmk,keymap";

        // Layer 0: Base
        default_layer {
            ...
            // Volume control
            sensor-bindings = <&inc_dec_kp C_VOL_UP C_VOL_DN>;
        };

        // Layer 1: Lower
        lower_layer {
            ...
            // Mouse scroll wheel
            sensor-bindings = <&inc_dec_kp mwh SCROLL_UP mwh SCROLL_DOWN>;
        };

        // Layer 2: Raise
        raise_layer {
            ...
            // Switch Next/Previous track
            sensor-bindings = <&inc_dec_kp C_NEXT C_PREV>;
        };
... Omitted below.
```

<br>

3. For the pulse section, we must open the `.overlay` file and add the "encoder" setup to the main definition area:

``` c
/ {
    ...

    /* Matrix Transform */
    default_transform: keymap_transform_0 {
    ...
    };

    /* Define Encoder */
    left_encoder: encoder_left {
        compatible = "alps,ec11";
        a-gpios = <&pro_micro 2 (GPIO_ACTIVE_HIGH | GPIO_PULL_UP)>;
        b-gpios = <&pro_micro 3 (GPIO_ACTIVE_HIGH | GPIO_PULL_UP)>;
        steps = <80>; /* Physically there are 80 pulses per rotation */
        status = "okay";
    };

    /* Encoder Sensor */
    sensors {
        compatible = "zmk,keymap-sensors";
        sensors = <&left_encoder>;
        triggers-per-rotation = <20>; /* Triggers 20 actions per rotation */
    };
};
```

This part is very similar to the `Encoder` setup in `QMK`:

``` c
// config.h

/* Encoders */
#define ENCODER_A_PINS { GP2 }
#define ENCODER_B_PINS { GP3 }
#define ENCODER_RESOLUTION 4

// keymap.c
#if defined(ENCODER_ENABLE) || defined(ENCODER_MAP_ENABLE)
    const uint16_t PROGMEM encoder_map[][NUM_ENCODERS][NUM_DIRECTIONS] = {
        [0] = { ENCODER_CCW_CW(XXXXXXX, XXXXXXX) },
        [1] = { ENCODER_CCW_CW(XXXXXXX, XXXXXXX) },
        [2] = { ENCODER_CCW_CW(XXXXXXX, XXXXXXX) },
        [3] = { ENCODER_CCW_CW(XXXXXXX, XXXXXXX) },
    };
#endif
```

In `ZMK`, we do not need to directly write `ENCODER_RESOLUTION 4` like in `QMK`. Instead, we must tell the system the "total number of pulses per rotation (`steps`)" and the "total number of detents per rotation (`triggers-per-rotation`)". The system will automatically divide the two to obtain the pulse multiplier for this encoder. Taking a standard `EC-11` as an example, it is usually 80 pulses divided by 20 detents, resulting in a multiplier of 4 pulses; if it is a mouse encoder (scroll wheel), both values are usually the same, resulting in a multiplier of 1 pulse.

Therefore, you still need to pull up the "specification sheet" for the mouse encoder, check the pulse value and total number for that encoder, and then fill the correct values into the code:

```c
left_encoder: encoder_left {
        compatible = "alps,ec11";
        ...
        steps = <24>;  /* Physically there are 24 pulses per rotation */
    };

    sensors {
        ...
        triggers-per-rotation = <12>; /* Triggers 12 actions per rotation */
    };
```

<table>
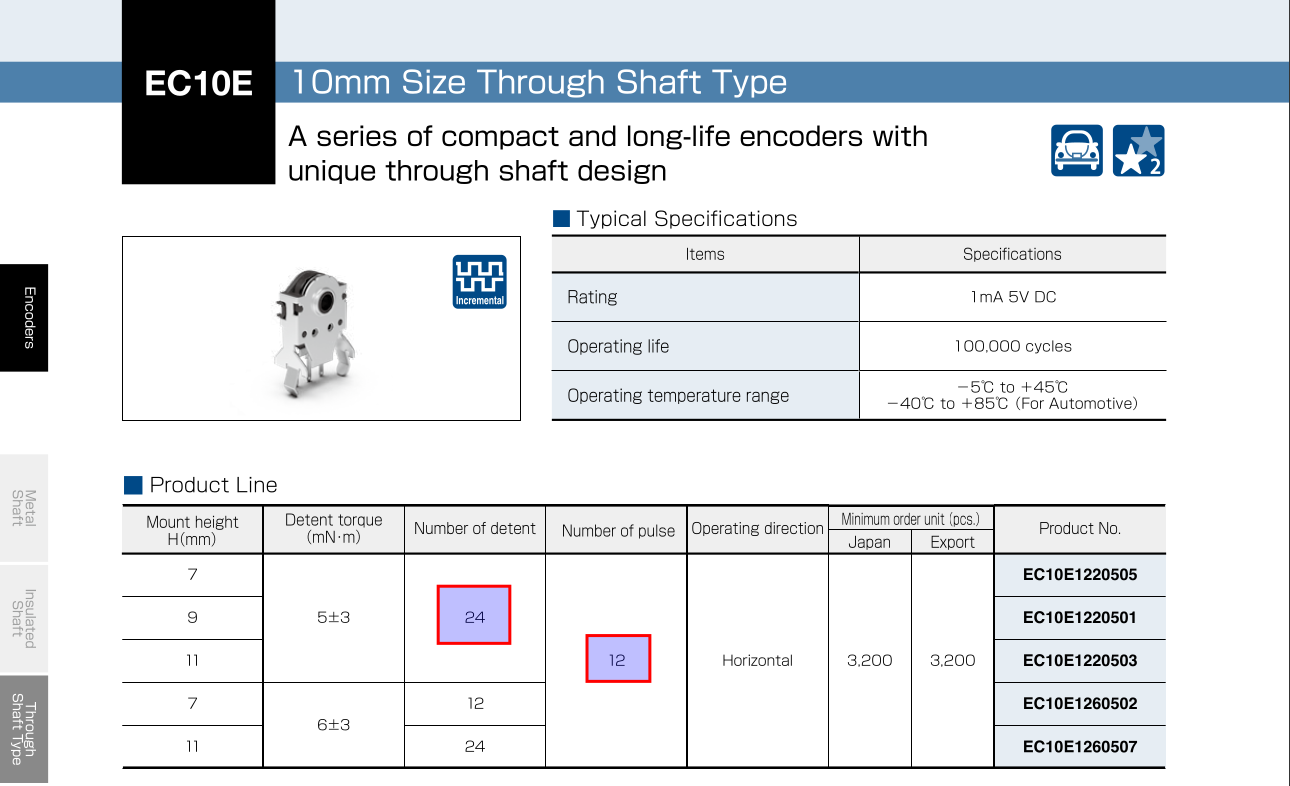
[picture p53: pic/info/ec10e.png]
data-ec10e
      
</table>

4. After filling in the pulse values, finally open the `.conf` file, write the encoder's global setup code into the configuration, then save and close it.

``` conf
...
# Encoder setup
CONFIG_EC11=y
CONFIG_EC11_TRIGGER_GLOBAL_THREAD=y              # Allow encoder hardware interrupts to trigger global threads
```

<br>

### C. Introduction to Pointing Devices

For pointing devices, you need to prepare `2` things:
- The driving method of that pointing device.
    - Pointing device specification sheet.
    - The pointing device component itself.
- Your design drawing.
    - o the `IO` pins support the communication method of the pointing device?

> Very important: How much "voltage (`VCC`, `VDD`)" is needed to drive the pointing device?

Common pointing devices include "optical sensors (`sensor`)", "joystick encoders (`joystick`)", and "trackpads". These three cover over `95%` of the operation methods on the market. Here is a brief introduction:

1. Optical sensors are usually composed of a combination of the "component itself" and an "optical lens", neither of which can be omitted. They need to be a certain distance away from the "sensing contact surface" to function properly.
    * Mouse: Component and lens face downwards, sensing the desktop.
    * Trackball: Component and lens do not face downwards, sensing a "standardized" sphere.
2. Joystick encoders, usually called "joysticks" or "trackpoints". The operation method involves the amount of planar movement on the `X` and `Y` axes. More specialized joystick encoder calculations have a vertical amount on the `Z` axis, though this is usually not used in pointing devices.
3. Trackpads are somewhat special. They calculate the `X` and `Y` axes over a planar circuit sensor board area of a certain size. Like joysticks, more specialized trackpad `MCU`s can calculate the height of the `Z` axis, which is the pressure value.
    * Commonly used ones include the `Azoteq` series and the `Cirque` series. These are universal models for `qmk` and `zmk`. Recently, a designer has also designed the `Azoteq` trackpad into `zmk`, and I will learn from him when the time comes.

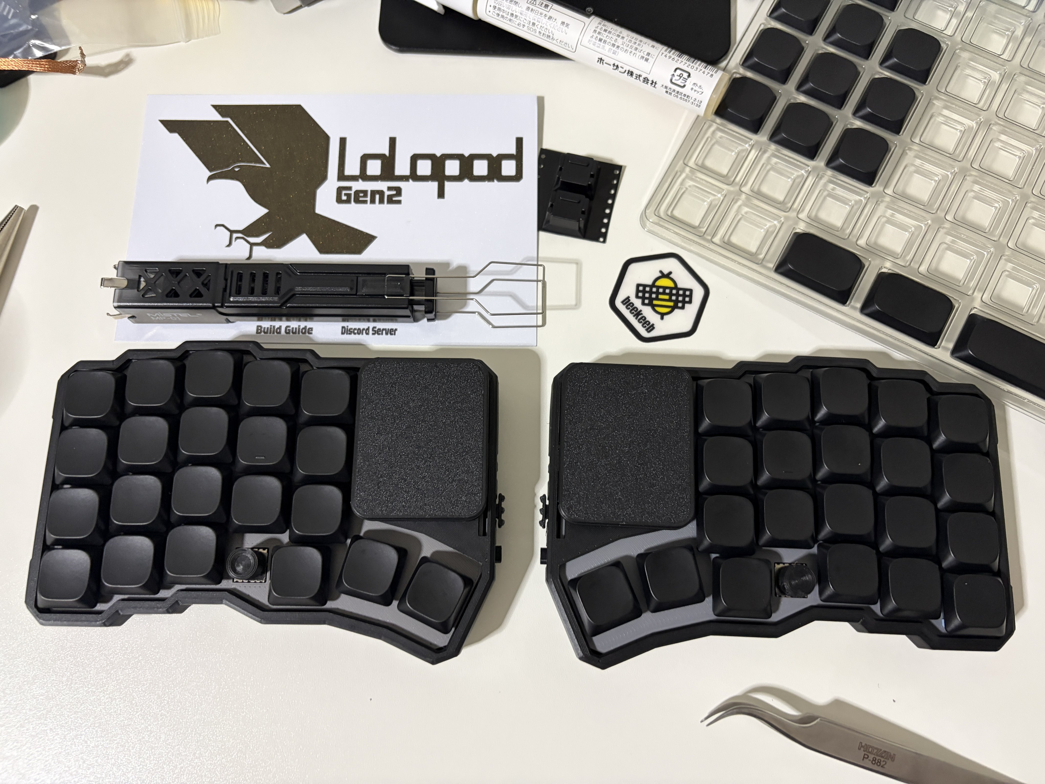
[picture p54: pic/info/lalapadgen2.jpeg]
lalapadgen2

- `Lalapad Gen2` by `kot`——[X Link](https://x.com/kot149_/status/2050509588760551813) (Not the original designer).

<br>

#### How to Read the Specification Sheet?

The specification sheet is what I have repeatedly emphasized needs to be consulted "first". From something as small as a "switch" (mechanical switch), to something as complex as the "trackpad" I am about to explain, you must first read the specification sheet before taking any "design" actions:

1. In terms of software design, you need to know the "communication method" and "detection method".
2. In terms of circuit design, you need to know the "voltage", "communication method", "how to wire the communication interface", "where to place the communication interface", "the direction of the communication interface", etc.
3. In terms of hardware design, you need to know "the actual size of this component", "`Z`-axis interference", "tolerances", etc.

Looking at the whole picture together, you will find the hardest low-level content in this specification sheet, such as "`EMI` interference", "communication conversion", "signal detection", etc. This part is called the "debugging mechanism".

Therefore, you don't need to overcomplicate the specification sheet. It's not an "incomprehensible text", but rather about selecting "the portions of content you currently need" to extract and consult.

<br>

The `Outsider` keyboard supports these two trackpads: `Azoteq TPS43` and `Cirque TM040040`. In my design, I placed the `EC-11`, `TPS43`, and `TM040040` all on the same pins.

First, let's see how I designed it:

#### EC-11

<table>
    <td width="50%">
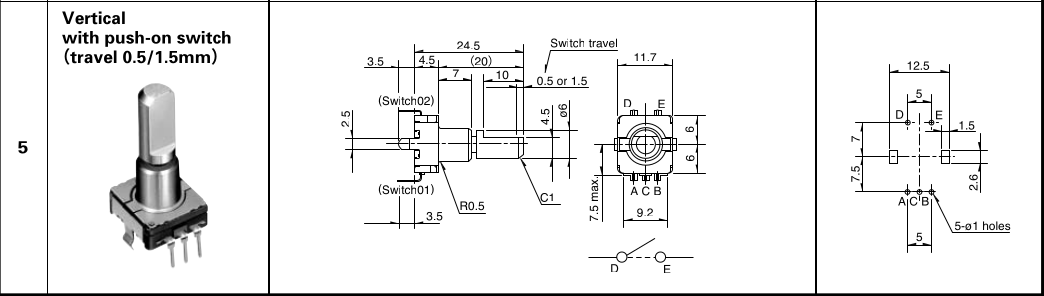
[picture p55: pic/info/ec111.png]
ec111
      
    </td>
  </tr>
   <tr>
    <td width="50%">
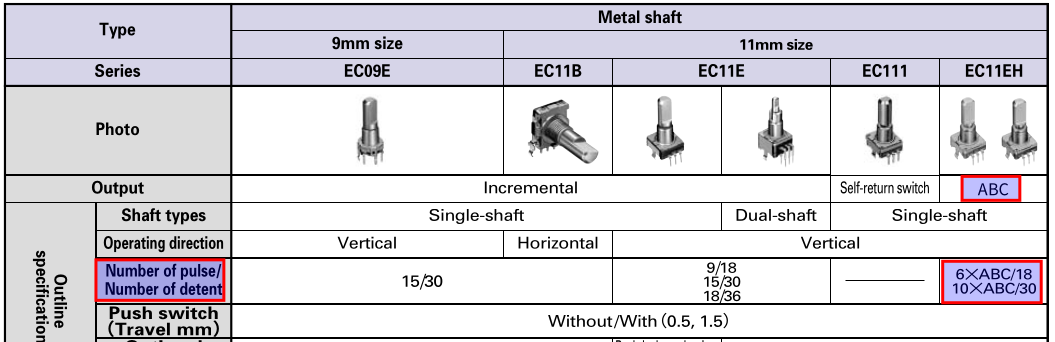
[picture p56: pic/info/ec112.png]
ec112
      
    </td>
  </tr>
</table>

`EC-11`, which is a commonly used encoder. If terms like clockwise, counter-clockwise rotation (`CW`, `CCW`), and switch (`SW`) are too hardcore, don't overcomplicate this component.

Its name is "Encoder with Switch". Just break it down into `2` parts to look at it:

1. Switch: Treat it as a mechanical switch you use on your keyboard.
2. Encoder: Treat it as a switch that triggers after rotating a few detents, and it can be triggered by rotating clockwise or counter-clockwise.

Simple enough?

ec11

Since it is divided into these `2` parts, the switch design is very simple. Design it into the matrix keyboard, use it as a switch, add a diode, and connect it to a `col` and `row`, and it's done.

For the encoder part, it is divided into `A`, `B`, and `C` three `pin`s. I said "treat it as a switch", but its design method is viewed independently, so it requires the "most traditional" circuit switch wiring method:

* One end connects to the signal, the other end connects to ground.
* So where is the ground (`GND`)? This requires consulting the specification sheet. It indicates which `pin` among `A`, `B`, and `C` needs to be grounded (I'll secretly tell you here that the ground for `EC-11` is connected at position `C`).

<br>

#### Azoteq TPS43

<table>
  <tr>
    <td width="50%">
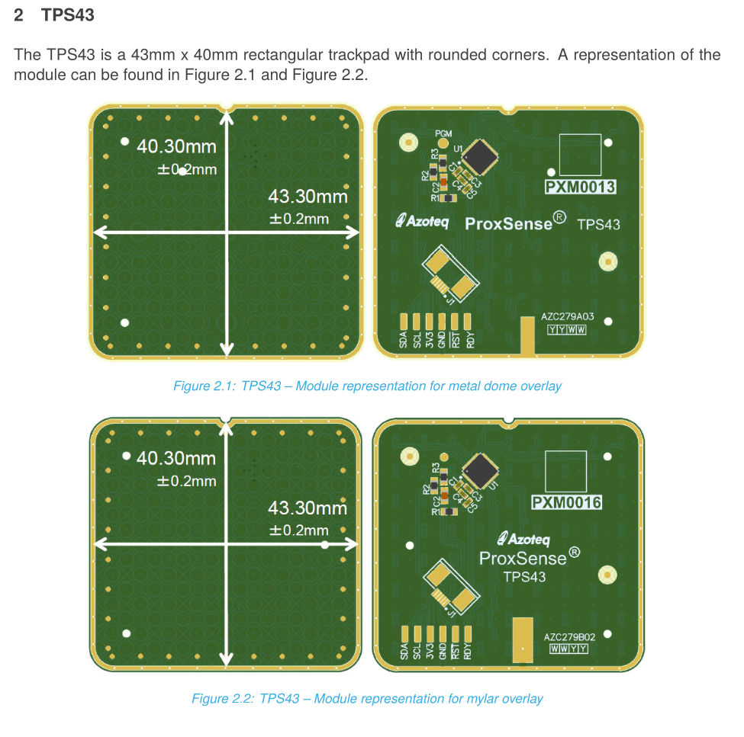
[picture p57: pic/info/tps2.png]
tps2
      
    </td>
    <td width="50%">
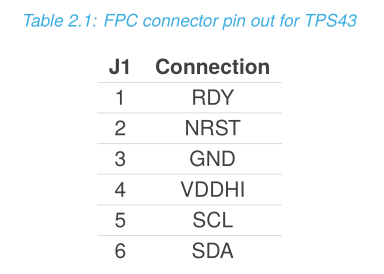
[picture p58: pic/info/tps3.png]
tps3
      
    </td>
  </tr>
   <tr>
    <td width="50%">
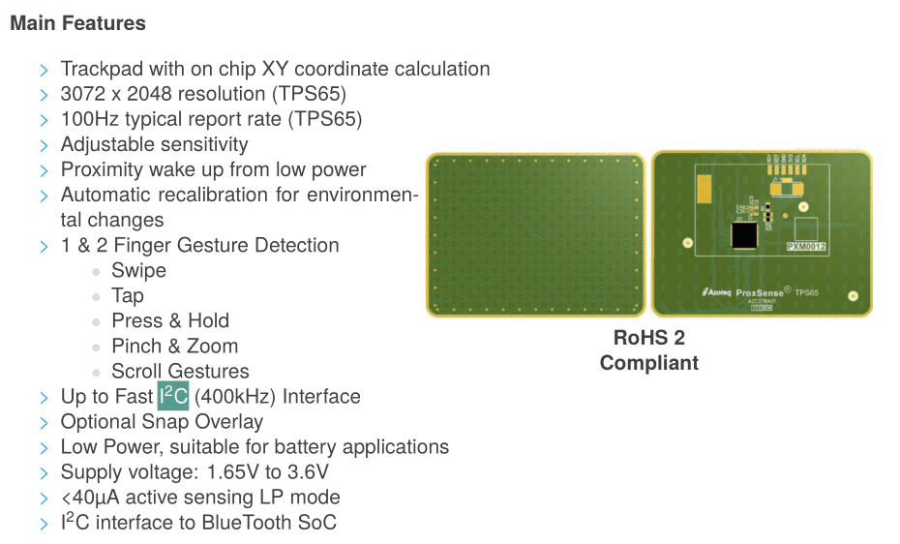
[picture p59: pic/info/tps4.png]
tps4
      
    </td>
    <td width="50%">
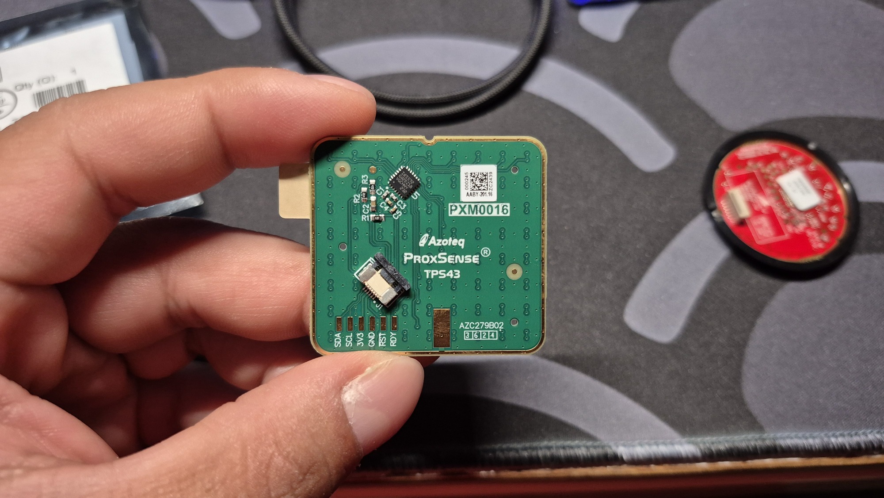
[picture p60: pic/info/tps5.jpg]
tps5
      
    </td>
  </tr>
</table>

For the `TPS43` part, the following are the portions I extracted:
1. Actual size and actual model:
    - `TPS43-201A-B`.
    - `43.3 x 40.3 mm`.
    - After calculation, the `PCB` thickness is `1.2 mm`, `3M` double-sided tape thickness is `0.35mm`, and the touch contact surface limitation is within `1.2 mm`.
    - `0.5mm FFC` connector thickness is `2 mm`, positioned asymmetrically at a `45`-degree angle.
    - The `FFC` interface distribution diagram shows the "`6th pin`" is "`SDA`".
2. Communication method:
    - `I2C`.
    - Operating voltage within the `1.65 - 3.6V` range.
    - Built-in `4.7k` pull-up resistor.

<br>

#### Cirque TM040040

<table>
  <tr>
    <td width="50%">
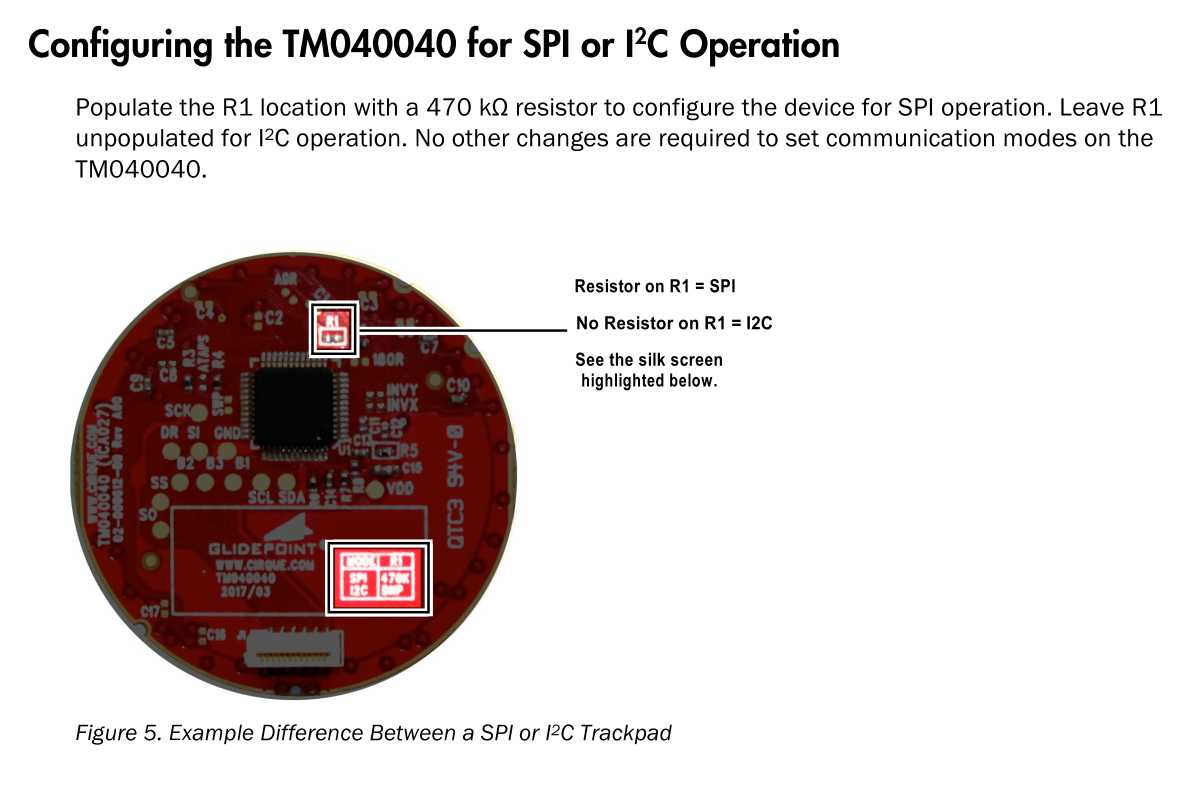
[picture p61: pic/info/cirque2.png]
cirque2
      
    </td>
    <td width="50%">
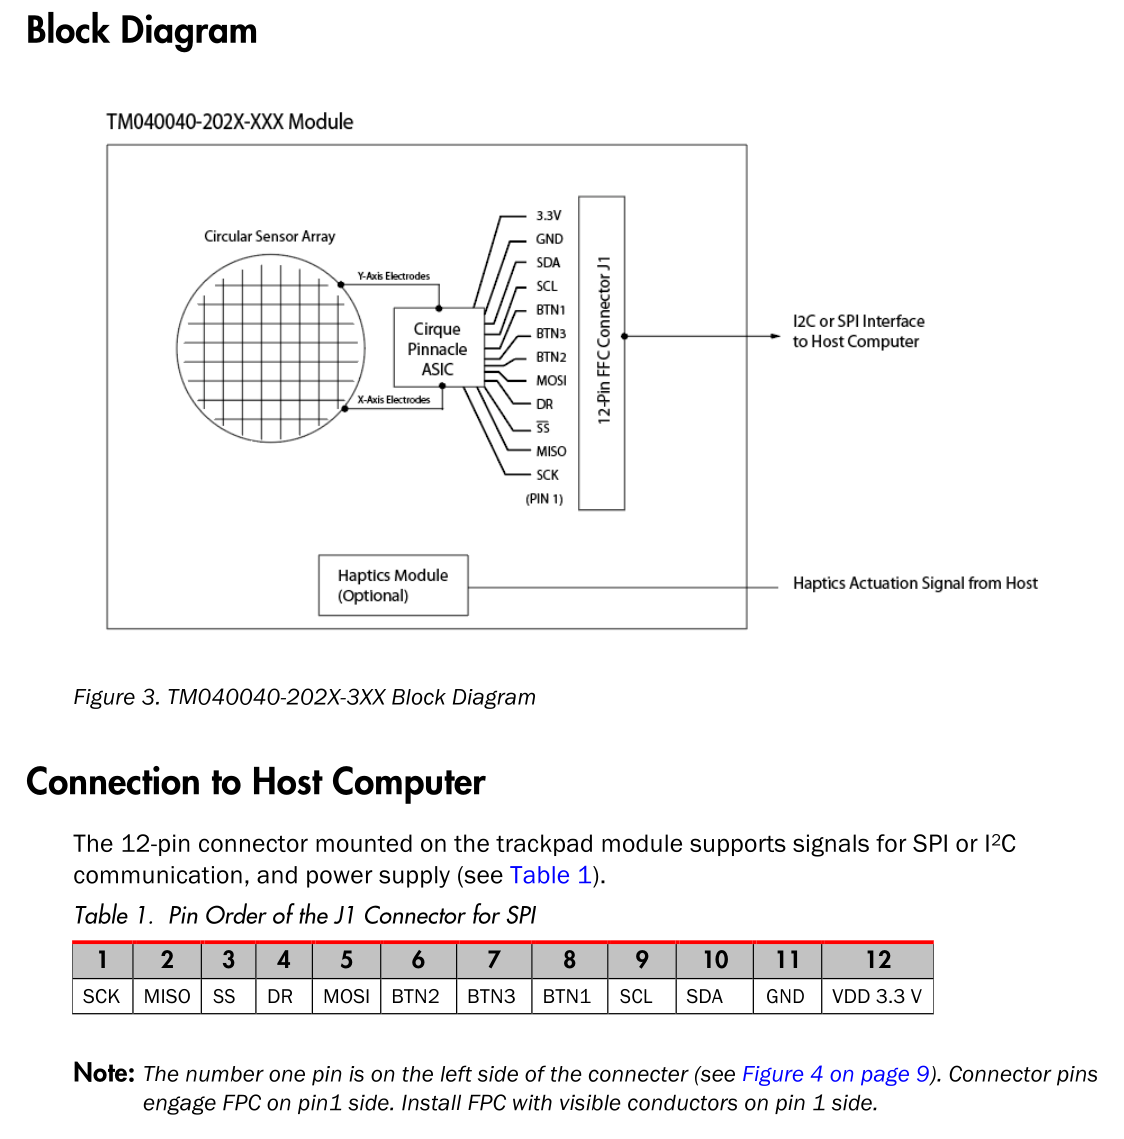
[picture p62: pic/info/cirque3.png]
cirque3
      
    </td>
  </tr>
   <tr>
    <td width="50%">
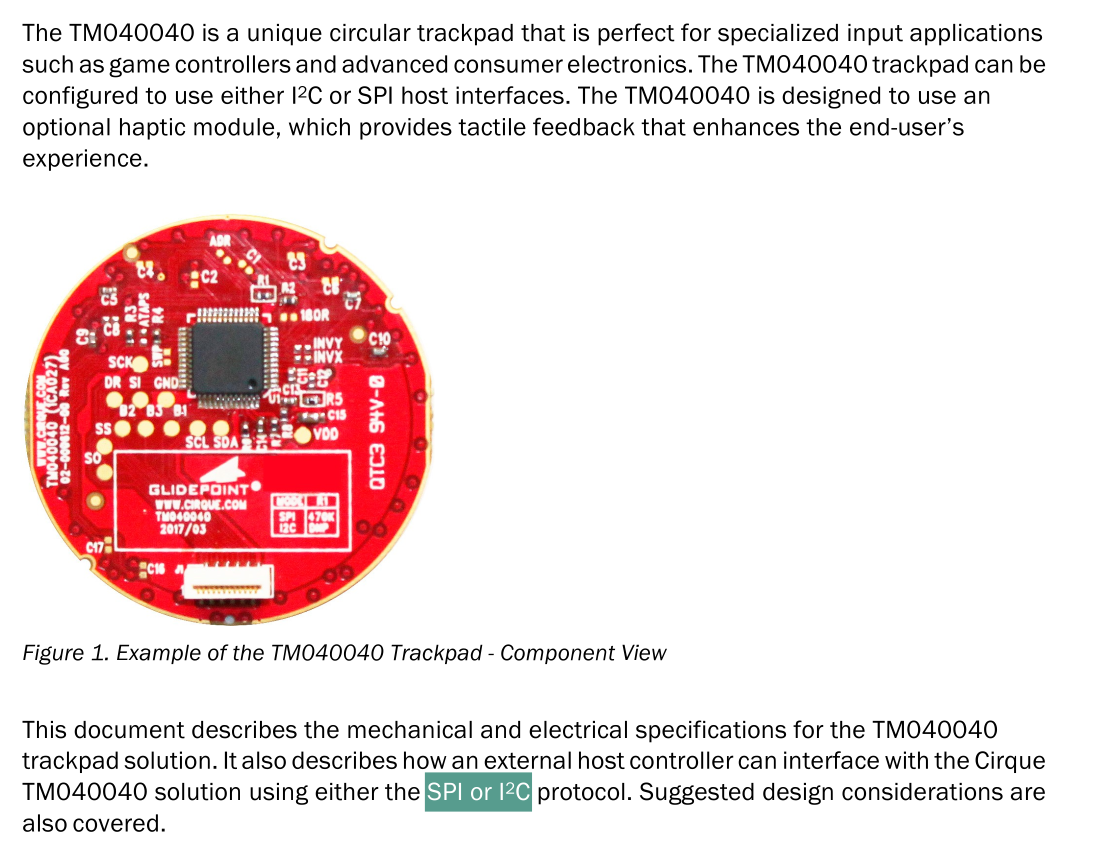
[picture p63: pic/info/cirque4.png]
cirque4
      
    </td>
    <td width="50%">
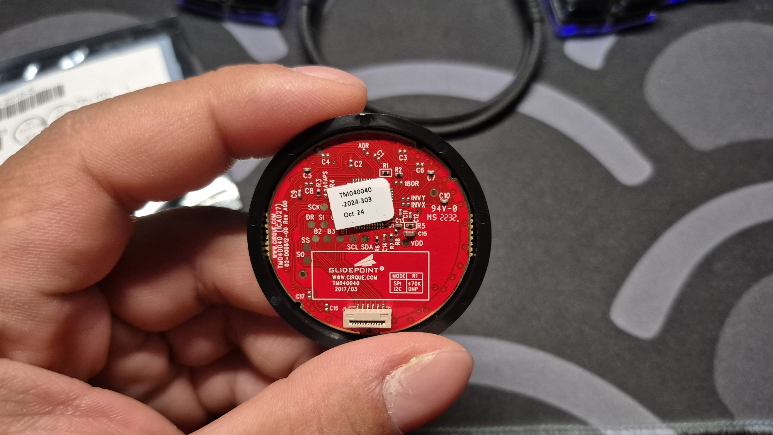
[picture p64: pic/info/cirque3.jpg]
cirque5
      
    </td>
  </tr>
</table>

For the `TM040040` part:
1. Communication method and physical interface:
    - Default is `SPI`, supports `I2C` after desoldering the `R1` resistor.
    - `FFC 0.5mm 12pin` vertical cable exit.
    - Operating voltage is `3V3`.
    - No pull-up resistor; requires designing a `4.7K` resistor interface yourself.
2. Interface `IO` distribution:
    - `1-5` are `SPI`.
    - `6-8` are `SW`.
    - `9-12` are `I2C`—this is the part we use.
3. Actual physical size and component distribution:
    - Comes with a plastic bowl-shaped touch surface: concave.
    - The `FFC` interface is located slightly below the center, protruding from the bowl edge.
4. True calculated size (`3D` part):
    - The actual positions of the `3` notches on the `PCB`.
    - The length of the non-circular cutout section on the `PCB` is `6.9` mm.
    - The touch surface `Z`-axis interference radius is `23.065` mm.

After numerical calculation from the specification sheet, I designed both the `KiCAD` `footprint` and the physical `3D` model to use as my own reference graphics.

<table>
  <tr>
    <td width="50%">
      cirque-ki
    </td>
    <td width="50%">
      cirque-3d
    </td>
  </tr>
</table>

<br>

- `ProMicro` and `nRF52840 ProMicro` (`nice!nano v2`)

<table>
  <tr>
    <td width="50%">
      rp2040
    </td>
    <td width="50%">
      nRF52840
    </td>
  </tr>
</table>

That's right, these `2` "pinout definition tables" are here again because they are truly important. I have said the phrase "prioritize using the intersection parts for design," and you can calculate how many "intersections" there are from the places where I extracted from the specification sheet earlier:
1. `I2C`.
2. `I2C` requires `2pin`, which are `SDA` and `SCL`.
3. `A`, `B`, `C`—removing `C` which is the `GND` position, leaves `A` and `B`.
4. An `8x8` matrix, totaling `16 pin`s.
5. The `VCC` for both development boards output `3V3`, which are both within the driving range of `TPS43` and `TM040040`.

After confirming the `I2C` communication method for the `FFC` connector from the specification sheet, defining the distribution direction in the `KiCAD` schematic, and then cross-referencing with the principles of better circuit board routing, I defined `I2C` on the `GP2 (D2)` and `GP3 (D3)` positions of the `RP2040` and `nRF52840 ProMicro` development boards, with the channel being `I2C1`.

Knob `A` and `B` share the `GP2 (D2)` and `GP3 (D3)` pins, therefore cross-processing must be done in the firmware.

> Very important: An easily overlooked rule of `I2C` communication is that its communication requires `2` `4.7K` resistors connected separately to `SDA` and `SCL`, and the other end of the resistors needs to connect to `VCC`, using "electricity" to pull up the potential of the communication channels.

<table>
  <tr>
    <td width="33%">
      cirque
    </td>
    <td width="33%">
      tps
    </td>
    <td width="33%">
      i2c
    </td>
  </tr>
</table>

<br>

#### zmk Setup Items

Back to `zmk` here.

> Pay special attention here, the design of the `Outsider` involves "shared pins", therefore when performing pointing device operations, I will completely mask out the "`Encoder`" part.

Operating up to this point, you will find that the `Outsider` has a huge problem—all of its pins are completely stuffed full, with no other expansion space. And the mechanism of the `zmk` firmware will force the "communication protocol" to use `SPI`'s `CS` or `I2C`'s `RDY` to communicate with the trackpad.

You can treat this "communication" process like this: `A` and `B` are next-door neighbors. `A` can walk through his "front door" to `B`'s "back door," but cannot walk from the "front door" to `B`'s "front door"; conversely, the same goes for `B`.

—But `A` can call `B` to wake up and open the door.

- `CS` and `RDY` are that "telephone line."

But unfortunately, in practice, this will use up an extra `IO Pin`. Therefore, I will not refer to the official text's `SPI` communication protocol here; although it is very convenient and can be compiled directly, it is realistically impossible to do.

...Since it's impossible, `zmk` can utilize the mounting of "third-party" low-level firmware to expand your `zmk` universe compilation core database.

<br>

#### Mounting Third-Party Databases

Although `Gemini` mentioned to me that there are many god-tier engineers on the internet developing pointing device firmware for `zmk`, in reality, the only one I found so far belongs to the great `halfdane`. Judging by the timeframe, it was their team's development that gave `zmk` a huge breakthrough about a year ago (in `2025`).

—Here we must thank them: [https://github.com/halfdane/zmk-input-gestures](https://github.com/halfdane/zmk-input-gestures)

First, enter the `GitHub` homepage of the third-party library. Actually, they have taught everyone how to "mount" the third-party library; here I will simplify the process a bit further.

<br>

Here is our current `XXX-zmk-config` folder architecture:

dir-tree2

1. First we enter the `west` folder:

``` bash
zmk cd
cd west
```

2. Open `west.yml`, follow the operations of the third-party library, paste the mounting content into the file, and save.

``` yaml
manifest:
  defaults:
    revision: main
  remotes:
    - name: zmkfirmware
      url-base: https://github.com/zmkfirmware
    # Additional modules containing boards/shields/custom code can be listed here as well
    # See https://docs.zephyrproject.org/3.2.0/develop/west/manifest.html#projects

    # Add the GitHub homepage of the third-party library here
    - name: halfdane
      url-base: https://github.com/halfdane/
  projects:
    - name: zmk
      remote: zmkfirmware
      import: app/west.yml
    # Add other modules at the bottom here
    - name: zmk-input-gestures
      remote: halfdane
      revision: main
    # This is the module for absolute mode, containing trackpad drivers and gesture processing
    - name: zmk-input-processors
      remote: halfdane
      revision: main
    # The library below will conflict with the official one, do not mount it for now
    # - name: cirque-input-module 
    #   remote: halfdane
    #   revision: absolute_mode
  self:
    path: config
```

3. Then execute the `west update` command in the terminal, and wait for it to finish mounting.
4. Next, you still need to manually open `.gitignore` and write the third-party mounted library folders into the exclusion list:

``` .gitignore
/zmk-input-gestures/
/zmk-input-processors/
/cirque-input-module/
```

5. Update `.gitignore` onto `GitHub` first, and then you can normally modify key mappings and add new keyboards again.

``` bash
git add .gitignore
git commit -m "add new module in config"
git push
```

<br>

#### Firmware Module Code Setup

> Precautions: Because during the debugging process of the `Outsider` circuit board on the hardware end, it was discovered that the bottom layer of the `zmk` firmware system forcibly requires designers to use:
> 1. `SPI` communication protocol: `CS`.
> 2. `I2C` communication protocol: `RDY`.
> 
> 
> I will carve out a separate major heading for this part at the bottom, and switch to using a breadboard to let everyone know the working principles.

<br>

#### Supplementary Notes

1. What exactly `I2C` and `SPI` are is actually not that important. You just need to look at the "pinout diagram" and cross-reference the text from `qmk` or `zmk` to handle the "device's" communication method. Simply put, just copy what you see in the diagrams; you don't need to know too much profound knowledge.

If I really have to explain it, I don't know what `I2C` and `SPI` are either. I only know they are "communication rules," as well as "how to wire them" and their "preliminary functions."

<br>

2. The only thing to note about `I2C` is the "pull-up resistor". Why is it `4.7K`?

Because this is the optimal solution derived after formula calculations. In the `3V3` world, you can use `2.2K` or `4.7K` to handle a device transmission speed of `400kHz`:
- `4.7K` is used for normal and general situations.
- `2.2K` is used for extreme situations. Unless the operating environment is extremely harsh, you will rarely have the chance to use it.

Simply put, as long as you see it's an `I2C` device driven by `3V3`, choosing `4.7K` without hesitation is the right move.

As for the resistor specifications, in the `3V3` world, actually any `4.7K` will do. If you want to use a `1/2W` sized resistor, I have no objections.

<br>

### D. Device Connection Settings

After the firmware's core functions and pin setups are complete, next we need to configure the "`MCU`'s" connection settings to the "devices":
- Bluetooth communication.
- `USB` communication.

That's right, both wired and wireless need to be set up. After discussing with a friend, I discovered that if the `zmk` firmware is missing just one setting, the keyboard will go on strike.

1. First, return to the `XXX-zmk-config` folder and enter the `boards/shields/<custom_keyboard>` folder directory:

``` bash
zmk cd
cd boards/shields/<custom_keyboard>
```

2. Then open the `.conf` file, write in the connection settings, and save:

``` conf
# Bluetooth Settings
CONFIG_ZMK_BLE=y
CONFIG_ZMK_KEYBOARD_NAME="<custom_keyboard_BLE>" # Bluetooth broadcast name
CONFIG_BT_CTLR_TX_PWR_PLUS_8=y                   # Boost Bluetooth transmission power
CONFIG_CLOCK_CONTROL_NRF_K32SRC_RC=y             # Use internal RC oscillator
CONFIG_CLOCK_CONTROL_NRF_K32SRC_500PPM=y         # RC oscillator precision setting

# Battery Settings
CONFIG_ZMK_BATTERY_REPORTING=n                   # Disable battery reporting function

# USB Settings
CONFIG_ZMK_USB=y
...
```

If this part is not set up properly, the `MCU` will play dead on you. You won't be able to find the signal using other Bluetooth devices, but the blue light on the connected device will keep flashing.

> Special Note: Many `nice!nano v2` clones on the market may differ from the original in terms of the Bluetooth chip's transmission power. You must consult the "development board schematic" first before adjusting based on `zmk`'s settings. Here, I enabled the `RC` oscillator calibration function, which finally allowed me to successfully receive my own keyboard's signal on my Bluetooth device.

3. Then open the `.keymap` file and set the key functions that control Bluetooth into the `keymap`:

```c
#include <dt-bindings/zmk/outputs.h> // Uses OUT_* series buttons, refer to the official Output Selection documentation
... Omitted above.
        // Layer 3: System/Control
        sys_layer {
            display-name = "System Layer";
            bindings = <
                &bt BT_CLR   &bt BT_SEL 0 &bt BT_SEL 1 &bt BT_SEL 2 &out OUT_BLE &out OUT_USB &none  &none  &kp INS  &kp SLCK &kp PAUSE_BREAK  &kp PSCRN 
                &kp CAPS     &none        &none        &none        &none        &none        &none  &none  &none    &none    &none            &none
                &none        &none        &none        &none        &none        &none        &none  &none  &none    &none    &none            &none
                &none        &none        &none        &none        &none        &none        &none  &none  &none    &none    &none            &to 0      &none
            >;
            // The key functions for Bluetooth settings can be written in by referencing the official zmk documentation.
        };
        ...
```

Bluetooth connected devices can be set up to a maximum of `5` groups. Here I only set up the standard `3` connection groups commonly seen on the market.

<br>

### E. Setting up GitHub Actions

I believe everyone is definitely not unfamiliar with `GitHub Actions`. This feature allows you to perform `CI/CD` tasks for your existing `zmk` keyboard firmware, letting you modify key mappings and compile firmware directly online. This action is essentially handing over the job of "compilation" for the cloud supercomputer to process.

> Note: `CI/CD`: Continuous Integration / Continuous Deployment.

Earlier, we spent an extremely, extremely massive amount of time architecting the `zmk` compilation environment. In this chapter, I will guide everyone through understanding and controlling the setup methods and architectural explanations for these two parts—`GitHub Actions` and the official `ZMK Studio`.

1. First, returning to the local `GitHub` folder, we need to locate the `.github/workflows/build.yaml` file under the `XXX-zmk-config` directory.

Then open it:

``` yaml
name: Build ZMK firmware
on: [push, pull_request, workflow_dispatch]

jobs:
  build:
    uses: zmkfirmware/zmk/.github/workflows/build-user-config.yml@v0.3 # Change to main
```

Then change the `v0.3` part to `main`, and subsequently save it.

> Note: There is a "`.`" in front of the `.github` folder, meaning it belongs to a hidden file or folder.

2. The `ZMK` community has a very mature web-based graphical interface called "[`Keymap Editor`](https://nickcoutsos.github.io/keymap-editor/)".

We need to use it. First, authorize the binding of your `GitHub` account, and then select your `XXX-zmk-config` repository.

kme

3. Next, follow the instructions of `Keymap Editor` and enter the main `GitHub` page.

> Special Note: The first time you run `Keymap Editor`, it will install a package in your `GitHub` account. Then, when choosing "settings," point it to the "`XXX-zmk-config`" repository.

4. Then, following the standard process, on the `Keymap Editor` interface, it will tell you that it cannot find the keyboard's "`.keymap`" file. At this point, we need to adjust the state of our local folders:

The current structure of the local folder is like this:



<br>

We need to copy the entire `boards` folder, and then paste a copy of it directly under `XXX-zmk-config/config`. Then, move the `<custom_keyboard>.keymap` from inside the `boards/shields/<custom_keyboard>` folder into the `XXX-zmk-config/config` area (see the picture):



<br>

5. After fixing the local folder structure, return to the `XXX-zmk-config` directory, open `build.yaml` to correct it, and then save:

``` yaml
# This file generates the GitHub Actions matrix.
# For simple board + shield combinations, add them to the top level board and
# shield arrays, for more control, add individual board + shield combinations
# to the `include` property. You can also use the `cmake-args` property to
# pass flags to the build command, `snippet` to add a Zephyr snippet, and
# `artifact-name` to assign a name to distinguish build outputs from each other:
#
# board: [ "nice_nano" ]
# shield: [ "corne_left", "corne_right" ]
# include:
#   - board: bdn9_rev2
#   - board: nice_nano
#     shield: reviung41
#   - board: nice_nano
#     shield: corne_left
#     snippet: studio-rpc-usb-uart
#     cmake-args: -DCONFIG_ZMK_STUDIO=y
#     artifact-name: corne_left_with_studio
#
---
# Write in the <custom_keyboard> data according to the format here
include:
  - board: nice_nano//zmk # Be sure to write //zmk at the back here to ensure GitHub Actions uses compatibility compilation
    shield: outsider
```

6. Then return to the terminal to operate the commands:

``` bash
zmk cd
git add .
git commit -m "set KME folder&update keymap"
git push
```

7. After uploading the corrections, return to the `Keymap Editor` interface. After refreshing, you will see the compilation starting to run at the top. You can click into it to see how the `GitHub Actions` firmware compilation status is doing.

<table>
  <tr>
    <td width="50%">
      kme2
    </td>
    <td width="50%">
      kme3
    </td>
  </tr>
</table>

<br>

> Note: Abbreviation for `Keymap Editor`.

8. Then, if `GitHub Actions` has finished compiling the firmware but the `KME` interface hasn't refreshed, enter `GitHub Actions` once more, and there will be a link to download the firmware at the bottom.



<br>

9. Following this is the familiar firmware flashing part for everyone. Simple enough?

<br>

## Physical Debugging Rules

Although `zmk` is "software" concerning wireless keyboards, this section should be considered my personal logic-sorting rules provided for everyone's reference.

Between circuit design and firmware design, there is a set of rules in the "gray" area, which is the physical debugging listed in the title. This part actually splits into two main headings:
1. Process of Elimination.
2. The `0/1` Rule.

<br>

I believe everyone is definitely not unfamiliar with it; the process of elimination is one of the "scientific experimental methods." Between circuits and firmware, this rule has always been extremely useful.

Formula: Assume `A + B = C` is an absolutely correct truth. Then I can reverse-deduce that either `A`, `B`, or both have problems, which is why I cannot obtain `C` in the result.

To put it plainly, if a key has no response, then I can first estimate:
1. Is there a setup error in the firmware?
2. Is the hardware connected to the wrong position?
3. Is there continuity from switch `A` and `B pin` to the `MCU`?
4. Is there a short circuit in the process?
5. Is the switch broken?

<br>

Then, amidst this kind of "process of elimination," you will find that the second rule is also influencing your behavioral judgments here—

The `0/1` Rule is extremely simple; it is the concept of "if it's there, it's there, if it's not, it's not," which happens to be an absolute truth in hardware and circuit debugging.

We extend further based on the process of elimination above: assuming the firmware has no setup errors and the hardware is not connected to the wrong position, we can pick up a "multimeter," switch the channel to the "continuity test" gear, and we can test:
1. `MCU` to switch `A pin`.
2. `MCU` to switch `B pin`.
3. `MCU` to diode `A pin`.
4. Switch `B pin` to diode `B pin`.
5. Whether switch `A` and `B` respond when pressed to conduct.

<br>

Right? This way you definitely have a way to achieve `100%` debugging, and no matter whether you encounter Bluetooth or even more obscure underlying principles, you also have a way to completely solve your major problems using these two rules.

<br>

## Pointing Devices

> Under construction, please excuse.

<br>

## ZMK Studio

`ZMK` was once criticized by `QMK` players—why can't it be like `VIA`/`VIAL`, where you plug in the cable and can remap keys instantly?

The officials heard this voice and therefore launched `ZMK Studio`—its underlying operational logic is completely different from `VIA`: `VIA` reads and writes a small block of memory inside the keyboard chip; while `ZMK Studio` dynamically modifies the key tree map in the keyboard memory directly through physical communication.

Simply put, as long as it can connect to "your keyboard," regardless of whether it is connected via a "`USB`" cable or "Bluetooth," it can remap keys.

> Warning: This belongs to an extreme knowledge blind spot. The following text explanations all belong to "my personal" pioneering process. If there are any errors during execution, they belong to the "normal scope."

<br>

### Prerequisites

1. First we need to check if `ZMK Studio`'s underlying compilation packages are installed:

``` bash
sudo apt update
sudo apt install protobuf-compiler
pip install protobuf grpcio-tools
```

2. Next we need to enter the `XXX-zmk-config` directory, open the `boards/shields/<custom_keyboard>/<custom_keyboard>.conf` file, and add this startup code:

```conf
# Enable ZMK Studio
CONFIG_ZMK_STUDIO=y
CONFIG_ZMK_STUDIO_LOCKING=n
```

3. Then open `.overlay`, and write in the `ZMK Studio` toggle code:

```c
#include <physical_layouts.dtsi> /* Add Physical Layout database */

/ {
    /* Physical Layout Declaration */
    key_physical_attrs: key_physical_attrs {
        compatible = "zmk,key-physical-attrs";
        #key-cells = <7>; /* Must declare 7 array parameters, otherwise compilation will error */
    };

    chosen {
        zmk,kscan = &kscan0;
        /* Delete or comment out this line of code, so ZMK Studio compilation won't error */
        // zmk,matrix_transform = &default_transform;
        zmk,physical-layout = &physical_layout0;  /* Add this line of code to "Use physical Layout_0" */
    };

    /* Add physical layout node */
    physical_layout0: physical_layout_0 {
        compatible = "zmk,physical-layout";
        display-name = "Default Layout";
        kscan = <&kscan0>;
        transform = <&default_transform>;
        
        /* Here you need to define the physical size and coordinates of each key */
        keys
            = 
            ;
        /* Code coordinate system explained in another section */
    };

    kscan0: kscan_0 {
    ...
    };
... Omitted below.
};
```

<br>

### Coordinate System

The "Physical Coordinate System" is a new calculation system invented by `ZMK` officials to benchmark against `VIA`/`VAIL`. Here we need to first understand its operational rules.

* Physical Coordinates
  * Origin: `(X, Y)` = `(0, 0)`
  * `X` axis: To the right is a "positive" value.
  * `Y` axis: Downwards is a "positive" value.

* Units:
  * `centi-keyunit`: Calculates "key size" in units of `1/100`. For example: `1U` = `100`.
  * `centi-degree`: Calculates "angle" in units of `1/100`. `10` degrees = `1000`.

* `&key_physical_attrs`:
  * `7` calculation values.
  * Inside `physical_layout0: physical_layout_n`, `keys` are used as sub-macros (`n` follows the `layout` value defined in `chosen`).
  * Usage method: `<&key_physical_attrs w h x y r rx ry>`

|Parameter|Description|Unit|
|--|--|--|
|`w`|`Width`|`centi-keyunit`|
|`h`|`Height`|`centi-keyunit`|
|`x`|`X` Coordinate|The `X` coordinate of the key's "top-left corner"|
|`y`|`Y` Coordinate|The `Y` coordinate of the key's "top-left corner"|
|`r`|`Rotation`|`centi-degree`|
|`rx`|`Rotation` `X`|The `X` coordinate of the rotation center point|
|`ry`|`Rotation` `Y`|The `Y` coordinate of the rotation center point|

<br>

Writing up to here, have you noticed something?

> Important: `zmk` officials did not invent any new coordinate system, but rather took the `KLE` calculation method and multiplied everything by `100` to perform operations.

<br>

### KLE Conversion

According to `Gemini`'s auxiliary analysis, regarding this `ZMK Studio` section, there is absolutely no tutorial text available. Even the official documentation only tells you this feature exists and how to set up the `.conf`, etc., but the accompanying source code is not explained at all.

> Note 1: https://zmk.dev/docs/features/studio

> Note 2: https://zmk.dev/docs/development/studio-rpc-protocol

> Note 3: https://zmk.dev/docs/config/studio

After gaining a deeper understanding, let's first create a basic `4x12` `Layout` following the arrangement in the photo, and then adjust it into a standard `Plank` configuration.

<table>
  <tr>
    <td width="50%">
      default
    </td>
  </tr>
  <tr>
    <td width="50%">
      plank
    </td>
  </tr>
</table>

<br>

> From here on, the explanation will be paired with the `.json` files in the `Outsider` project folder and the web-based `Keyboard Layout Editor`.
> 1. `zmkstudio-default.json`
> 2. `zmkstudio-plank.json`

<br>

First, we open `KLE`, and then import the `default` layout diagram.



Then click on the first key in the top-left corner, and I will tell everyone how to build the code for this part next.

<br>



|Parameter|Description|Unit|
|--|--|--|
|`w`|`Width`|`centi-keyunit`|
|`h`|`Height`|`centi-keyunit`|
|`x`|`X` Coordinate|The `X` coordinate of the key's "top-left corner"|
|`y`|`Y` Coordinate|The `Y` coordinate of the key's "top-left corner"|
|`r`|`Rotation`|`centi-degree`|
|`rx`|`Rotation` `X`|The `X` coordinate of the rotation center point|
|`ry`|`Rotation` `Y`|The `Y` coordinate of the rotation center point|

Here we need to process it following the same code-writing rules as in `QMK`:
1. Start from left to right, then top to bottom.
2. The numerical fields in the red border correspond to the table above:
    - `Width`: `w`
    - `Height`: `h`
    - `X`: `x`
    - `Y`: `y`
    - `Rotation`: `r`, `rx`, `ry`

3. `<&key_physical_attrs w h x y r rx ry>`

<br>

From this, we know to first locate the values of the first key in the top-left corner, and then fill in the values from the red box after multiplying by `100` (`x100`):

```c
<&key_physical_attrs 100 100   0   0 0 0 0>
```

<br>

4. Then you can sequentially build up all the keys for the entire keyboard:

```c
/ {
    ...
    /* Physical Layout */
    physical_layout0: physical_layout_0 {
        compatible = "zmk,physical-layout";
        display-name = "Default Layout";
        kscan = <&kscan0>;
        transform = <&default_transform>;
        
        /* X,Y & Units */
        keys
            /* Row0, Row4 - col0-5 */
            = <&key_physical_attrs 100 100    0    0 0 0 0>
            , <&key_physical_attrs 100 100  100    0 0 0 0>
            , <&key_physical_attrs 100 100  200    0 0 0 0>
            , <&key_physical_attrs 100 100  300    0 0 0 0>
            , <&key_physical_attrs 100 100  400    0 0 0 0>
            , <&key_physical_attrs 100 100  500    0 0 0 0>
            , <&key_physical_attrs 100 100  600    0 0 0 0>
            , <&key_physical_attrs 100 100  700    0 0 0 0>
            , <&key_physical_attrs 100 100  800    0 0 0 0>
            , <&key_physical_attrs 100 100  900    0 0 0 0>
            , <&key_physical_attrs 100 100 1000    0 0 0 0>
            , <&key_physical_attrs 100 100 1100    0 0 0 0>
            , <&key_physical_attrs 100 100 1325   50 0 0 0> // EC-11

            /* Row1, Row5 - col0-5 */
            , <&key_physical_attrs 100 100    0  100 0 0 0>
            , <&key_physical_attrs 100 100  100  100 0 0 0>
            , <&key_physical_attrs 100 100  200  100 0 0 0>
            , <&key_physical_attrs 100 100  300  100 0 0 0>
            , <&key_physical_attrs 100 100  400  100 0 0 0>
            , <&key_physical_attrs 100 100  500  100 0 0 0>
            , <&key_physical_attrs 100 100  600  100 0 0 0>
            , <&key_physical_attrs 100 100  700  100 0 0 0>
            , <&key_physical_attrs 100 100  800  100 0 0 0>
            , <&key_physical_attrs 100 100  900  100 0 0 0>
            , <&key_physical_attrs 100 100 1000  100 0 0 0>
            , <&key_physical_attrs 100 100 1100  100 0 0 0>

            /* Row2, Row6 - col0-5 */
            , <&key_physical_attrs 100 100    0  200 0 0 0>
            , <&key_physical_attrs 100 100  100  200 0 0 0>
            , <&key_physical_attrs 100 100  200  200 0 0 0>
            , <&key_physical_attrs 100 100  300  200 0 0 0>
            , <&key_physical_attrs 100 100  400  200 0 0 0>
            , <&key_physical_attrs 100 100  500  200 0 0 0>
            , <&key_physical_attrs 100 100  600  200 0 0 0>
            , <&key_physical_attrs 100 100  700  200 0 0 0>
            , <&key_physical_attrs 100 100  800  200 0 0 0>
            , <&key_physical_attrs 100 100  900  200 0 0 0>
            , <&key_physical_attrs 100 100 1000  200 0 0 0>
            , <&key_physical_attrs 100 100 1100  200 0 0 0>

            /* Row3, Row7 - col0-5 */
            , <&key_physical_attrs 100 100    0  300 0 0 0>
            , <&key_physical_attrs 100 100  100  300 0 0 0>
            , <&key_physical_attrs 100 100  200  300 0 0 0>
            , <&key_physical_attrs 100 100  300  300 0 0 0>
            , <&key_physical_attrs 100 100  400  300 0 0 0>
            , <&key_physical_attrs 100 100  500  300 0 0 0>
            , <&key_physical_attrs 100 100  600  300 0 0 0>
            , <&key_physical_attrs 100 100  700  300 0 0 0>
            , <&key_physical_attrs 100 100  800  300 0 0 0>
            , <&key_physical_attrs 100 100  900  300 0 0 0>
            , <&key_physical_attrs 100 100 1000  300 0 0 0>
            , <&key_physical_attrs 100 100 1100  300 0 0 0>
            ;
    };
};
```

<br>

### Starting ZMK Studio

To be safe, personally, when implementing up to this point, I recommend compiling once to see if there are any errors before continuing to create other `Layout`s.

Because my testing environment is `Linux Mint`, there are very strict restrictions regarding `USB` connections... Most `Linux` systems are like this, while other systems require testing.

<br>

Before compiling, a few setup items need to be addressed. Otherwise, you might successfully compile and flash it, but `ZMK Studio` will absolutely not let you open the official website to connect and modify keys.

1. Return to the terminal. We first need to open the `USB` web read permissions for the `Linux` system:

```bash
sudo chmod 666 /dev/ttyACM0
sudo usermod -aG dialout $USER
```

2. We return to the local `XXX-zmk-config` folder, first open `build.yaml` under the directory, and add the startup code for `ZMK Studio` below the `<custom_keyboard>` configuration file under `include`.

``` yaml
# This file generates the GitHub Actions matrix.
# For simple board + shield combinations, add them to the top level board and
# shield arrays, for more control, add individual board + shield combinations
# to the `include` property. You can also use the `cmake-args` property to
# pass flags to the build command, `snippet` to add a Zephyr snippet, and
# `artifact-name` to assign a name to distinguish build outputs from each other:
#
# board: [ "nice_nano" ]
# shield: [ "corne_left", "corne_right" ]
# include:
#   - board: bdn9_rev2
#   - board: nice_nano
#     shield: reviung41
#   - board: nice_nano
#     shield: corne_left
#     snippet: studio-rpc-usb-uart
#     cmake-args: -DCONFIG_ZMK_STUDIO=y
#     artifact-name: corne_left_with_studio
#
---
include:
  - board: nice_nano//zmk
    shield: outsider
    snippet: studio-rpc-usb-uart # Add this line
```

3. Next, we can flash the firmware, but we need to adjust the compilation command a bit:

``` bash
west build -p -b nice_nano -S studio-rpc-usb-uart -- -DSHIELD=<custom_keyboard> -DZMK_CONFIG="[Your XXX-zmk-config folder path]"
```

4. After successful compilation, flash the firmware into the keyboard. Then conveniently test if the keyboard works normally while connected with the `USB` cable, and then open the official `ZMK` website — https://zmk.dev/
5. There is a `ZMK Studio` button at the top of the official website, click into it.



<br>

6. Click the USB button in the center, and you will see a connection option pop up at the top of the web page. If your keyboard appears at the top, then you have succeeded.

<table>
  <tr>
    <td width="50%">
      kme6
    </td>
  </tr>
  <tr>
    <td width="50%">
      kme7
    </td>
  </tr>
</table>

<br>

### Precautions

After flashing and reading `ZMK Studio`, I need to tell everyone the pros and cons of this feature here.

First are the "Pros":
- You can modify key functions without connection restrictions.

> If there are other pros, I will add them later (laughs).

Cons:
- No official tutorial text — this is extremely serious.
  - There are only major `.conf` startup settings.
  - After setting up `.conf`, there are still a bunch of miscellaneous items that need to be set.
- `Physical Layout`:
  - Don't know how to use it.
  - Don't know how to define it.
  - Don't know how to write the code.
  - Don't know what standard the code's coordinate system is based on.

All of the above was deduced through my "reverse analysis". In the beginning, I specifically emphasized that I am "pioneering." This means that the number of `Error`s I personally encountered while writing this text is probably `10` times more, or even greater, than what you might face over several months.

<br>

1. Cannot set up "menu-style" modifications for "partial" `Layout`s like `VIAL`.
    * Freedom is restricted.
    * The code engineering workload is extremely massive.

2. Having too many multi-layout setups will cause MCU memory allocation issues.
    * Deep water zone.

<br>

Being able to pioneer to this extent for everyone is also quite a surprising thing for me. After all, I already knew that `ZMK` itself is an extremely "unfriendly" firmware for novices, but I didn't expect the level of unfriendliness to be beyond my imagination.

If this included tutorial article can allow everyone's keyboards to "smoothly" appear on the list during Bluetooth device searches, then the significance of this is entirely different.

I am `DreaM117er`, an amateur keyboard developer from Taiwan. If there are more opportunities, I will continue to pioneer.

<br>

> As for pointing devices, I will find time to isolate them using a development board for pioneering and debugging later. Please wait for me a while.

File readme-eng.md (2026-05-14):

# Vanguard Keyboard Outsider

info

<br>

## Preface

The "Vanguard Series" is a branch point I personally developed based on the "Explorer Keyboard Blank" architecture. This is because, in the design of Blank, I "modularized" the keyboard's MCU area, allowing its trackpad and `ProMicro` MCU module to be completely reused in subsequent works.

- Why is this keyboard number two?

The codename for Vanguard Series 1st is `Mono`, and its Chinese codename is "Twin Sisters". Considering that people were eagerly asking for the development of zmk firmware, I started another keyboard first to try and research zmk, taking the opportunity to create a wireless version of the firmware. Once successful, I will go back to complete the development of "1st".

——Of course, there is also the development of the "Blank `v2`" and its wireless firmware version.

Because it is based on the "Explorer Series", although Vanguard is somewhat restricted to developing in the "modular" area, I will not abandon the degree of freedom of the "Explorer". Conversely, this freedom actually caused some confusion for me during development, which was a minor accident.

`Plank` has always been the progenitor of ortholinear layouts that I really like, and `Blank` is also a keyboard developed based on `Plank`. My idea is very simple:

——Starting from the most primitive, there will definitely be better creativity.

<br>

- Auxiliary references:
    - `about-zmk-XXX` tutorial text.
    - `QMK Firmware`: https://qmk.fm/
    - `VIAL`: https://get.vial.today/
    - `ZMK Firmware`: https://zmk.dev/
    - `KLE`: https://www.keyboard-layout-editor.com/#/
    - `nRF Connect SDK`:
        - `Android` Link: https://play.google.com/store/apps/details?id=no.nordicsemi.android.mcp&pcampaignid=web_share
        - PC Version: https://www.nordicsemi.com/Products/Development-tools/nrf-connect-for-desktop/download
        - Used for initial Bluetooth signal capture and debugging.
    - `FreeCAD`.

<br>

## Hardware Design

### Degrees of Freedom and Limitations

The main reason I designed the `Outsider` into this unique appearance is the retention of "degrees of freedom". So where are its degrees of freedom? The answer is very simple——

——It can be used by flipping it "arbitrarily".

And it is an extended design based on Explorer Blank, which means its MCU area is inherited. The bill of materials will specify which components directly use the design files of "Explorer Keybaord Blank".

<br>

Tai Chi theory has a core concept that "things turn into their opposites when they reach the extreme". The same applies to any design. This keyboard provides the ultimate degree of freedom. Its "current" limitations are listed below:
1. Supports soldering.
2. Does not support `Gateron Low Profile 2.0`, aka `GLP2.0`.
3. The trackpad only supports the `QMK` wired version.

<br>

The parts regarding degrees of freedom based on the "limitations" are listed below:
1. Supports `MX` footprint "switches", not limited to "low-profile switches".
2. Supports `GLP3.0` low-profile switches.
3. Supports `Choc` footprint "switches".
4. Supports flipped assembly of all PCB and case components.
5. Supports `zmk` encoder wireless version.
6. Supports `qmk` `Azoteq TPS43` and `Cirque TM040040` trackpads and encoder wired version.
7. Supports multi-layout soldering adjustments.
8. Supports physical board-splitting assembly for use.

<br>

### Circuit Design

#### Core PCB

<table>
  <tr>
    <td width="100%">
      A
    </td>
  </tr>
  <tr>
    <td width="100%">
      B
    </td>
  </tr>
</table>

<br>

#### Positioning Plate, MCU Cover Plate, and Bottom Plate

<table>
  <tr>
    <td width="50%">
      B1
    </td>
    <td width="50%">
      M
    </td>
  </tr>
  <tr>
    <td width="50%">
      P1
    </td>
    <td width="50%">
      P2
    </td>
  </tr>
</table>

<br>

#### MCU and Modules

<table>
  <tr>
    <td width="50%">
      T1
    </td>
    <td width="50%">
      T2
    </td>
  </tr>
  <tr>
    <td width="50%">
      T3
    </td>
    <td width="50%">
      T4
    </td>
  </tr>
</table>

<br>

#### 3D Printed Parts

<table>
  <tr>
    <td width="50%">
      T5
    </td>
    <td width="50%">
      T6
    </td>
  </tr>
</table>

<br>

## Materials Used

The materials used part is relatively simple. `Outsider` does not have excessive `3D` designs and consistently retains the "sandwich" structure.

||Name|Quantity|Quantity||
|--|--|--|--|--|
|⚠️ **PCB**|**Layout**|**4x10**|**4x12**|**Remarks**|
||Main PCB|1|1|Thickness `1.2mm`|
||Bottom Plate|1|1|Thickness `1.6mm`|
||`4x8` Positioning Plate|1|1|**See notes below**|
||`4x2` Positioning Plate|1|2|**See notes below**|
|`TM040040`|Module `A`|1|1|**Blank Component**|
|`TM040040`|Module `B`|1|1|**Blank Component**|
|`TM040040`|Module `C`|1|1|**Blank Component**|
|`TPS43`|Module `D`|1|1|**Blank Component**|
|⚠️ **MCU**|**Footprint**||||
|`ATMega32U4`|`ProMicro`|1|1|**Basic Wired Version**|
|`RP2040`|`ProMicro`|1|1|**Wired Trackpad**|
|`nRF52840`|`ProMicro`|1|1|**Wireless Version (Supports Encoder)**|
|⚠️ **Electronic Components**|**Name/Specification**||||
|`1N4148`|`SOD-123`|40-41|48-49||
|`EC-11`/`EC-12`|`L10mm` `A4.5-5.0mm`|1|1|**Optional**|
|Tactile Switch|`6x3.5x4.3mm` `2 Pin`|1|1||
|Tactile Switch|`SKRK` `2mm`|1|1|**Optional**|
|Slide Switch|`MSKT-12D14`|1|1|**Optional**|
|Under `501735`|`3.7V` Li-Po Battery|1|1|**Optional, placed above MCU**|
|-|`3.7V` Li-Po Battery Level Display Module|1|1|**Optional**|
|`PH2.0` `THT` Male/Female Connector|`JST PH S2B-PH-K`|1|1|**Optional**|
|💡 **TM040040**|||||
|**Name**|**Specification**||||
|Trackpad|-|1|1|**Optional**|
|Resistor|`1/4W` `4.7K`|2|2||
|FFC Cable|`0.5x5mm` `FFC 12pin` `AA`|1|1||
|FFC Connector|`0.5mm` `FFC 12pin`|1|1|**Any flip cover type**|
|Screw|`M2x3`|20|24||
|Screw|`M2x6`|4|4||
|Standoff|`M2x5` `ø3.05-4mm`|6|8|**Low-profile switch height**|
|Standoff|`M2x6` `ø3.05-4mm`|4|4|**Recommended height**|
|Standoff|`M2x7` `ø3.05-4mm`|2|2|**Wired MCU**|
|Standoff|`M2x10` `ø3.05-4mm`|2|2|**Wireless MCU**|
|💡 **TPS43**|||||
|Trackpad|-|1|1|**Optional**|
|FFC Cable|`0.5x5mm` `FFC 6pin` `AA`|1|1||
|FFC Connector|`0.5mm` `FFC 6pin`|1|1|**Any flip cover type**|
|Screw|`M2x3`|20|24||
|Screw|`M2x6`|4|4||
|Standoff|`M2x5` `ø3.05-4mm`|6|8|-|
|Standoff|`M2x6` `ø3.05-4mm`|4|4||
|Standoff|`M2x8` `ø3.05-4mm`|4|4|**Recommended height**|
|Standoff|`M2x7` `ø3.05-4mm`|2|2|**Wired MCU**|
|Standoff|`M2x10` `ø3.05-4mm`|2|2|**Wireless MCU**|
|📌 **3D Printed Parts**|||||
|`TPS43`|Touch contact surface|1|1||
|`EC-11`|`ø39mm`, `L4.5mm` Encoder cap|1|1||
|📌 **Others**|||||
|Self-adhesive `Poron` foam|Thickness `2mm`|-|-||
|Self-adhesive silicone feet|`ø8mm` `0.5-1mm`|4|4||

<br>

## Precautions

### Components

- If you want to install the `EC-11` encoder, please choose the module that supports `TM040040`.

- The above standoff specifications are primarily for "low-profile switch" configurations; if using standard `MX` switches, the height specifications must be completely adjusted to at least `M2x7mm`.

- The positioning plate for standard `MX` switches uses a thickness of `1.6mm`; low-profile switches uniformly use a thickness of `1.2mm`.

- Prepare "at least" `40` or `48` switches or more; choose the type according to your own preference.

<br>

### Assembly

- Soldering iron operation involves high heat; be sure to pay attention to electrical and fire safety.

- Rosin and solder are highly toxic substances; be sure to ensure environmental ventilation.

- It is recommended to wear gloves, masks, and safety goggles during operation to ensure safety.

- Operation technique recommendations:
  - Soldering iron: constant temperature control between `250`-`330` degrees Celsius.
    - `K`.
    - `BC`.
  - Solder: `183` degrees Celsius.
  - Wires:
    - Specification at least `24`-`28` `AWG`.
    - Colors must clearly distinguish at least `2` colors.

- Operation tools:
  - Crimping pliers:
    - Need to be able to handle `PH2.0` specifications.
    - Prepare some extra metal terminals as spares.
    - Adjust the pressure latch first before crimping.
  - Wire strippers:
    - Used for the Li-Po battery and its battery level display module.

- Trackpad options:
  - `TM040040`:
    - Requires soldering `4.7K` resistors.
    - Requires removing the `R1` resistor on the trackpad yourself.
    - Tutorial references:
      - [40mm Cirque GlidePoint Circle Trackpad Module DIY Kit for Split Mechanical Keyboard](https://shop.beekeeb.com/product/40mm-cirque-glidepoint-circle-trackpad-module-diy-kit-for-split-mechanical-keyboard/)
      - [GlidePoint Cirque Trackpad TM040040 TM035035](https://keycapsss.com/keyboard-parts/parts/211/glidepoint-cirque-trackpad-tm040040-tm035035)
  - `TPS43`: No need to solder resistors.

<br>



- Regarding jumpers:
  - You only need to solder one side of the PCB.
  - `PWR`:
    - Always choose the `3V3` power supply position based on the `MCU`.
    - Usually, `3V3` is located at the `P1` position.
  - `VCC`:
    - Use jumper: solder it when assembling the `TM040040` trackpad.
    - Do not solder jumper: you can replace `TM040040` with `TPS43` without desoldering the `4.7K` resistors.

<br>

<table>
  <tr>
    <td width="50%">
      m2
    </td>
    <td width="50%">
      m3
    </td>
  </tr>
</table>

- Regarding `MCU`:
  - Install according to the `MCU`'s pinout diagram.
  - Refer to the image above and use the direction with "`2` `GND`s" for reading, which makes it less likely to install backwards.

<br>

### Icon Identification

<table>
  <tr>
    <td width="40%">
      <p>Diodes are directional.</p>
      <p>Note the marking line at the front of the diode.</p>
    </td>
    <td width="30%">
      d1
    </td>
    <td width="30%">
      d2
    </td>
  </tr>
  <tr>
    <td width="40%">
      <p>Resistors are not directional.</p>
      <p>Please install the resistors on the same side as the "MCU".</p>
    </td>
    <td width="30%">
      r1
    </td>
    <td width="30%">
      r2
    </td>
  </tr>
</table>

<br>

## Assembly Method

After reviewing the aforementioned specifications and entering the physical assembly stage, please pay special attention to the following challenging parts:
- Soldering technique:
  - Temperature control.
  - `3`-second rule.
  - `0.5mm` `FFC` connector.
- Debugging technique:
  - `0/1` rule.
  - Anti-short circuit rule.

<br>

<table>
  <tr>
    <td width="38%">
      layout2
    </td>
    <td width="62%">
      layout3
    </td>
  </tr>
</table>

<br>

Take out the PCB, and then think for a moment:
  - What should the layout look like?
  - Is the keyboard wired or wirelessly driven?
  - What devices can I equip?

g0

<br>

Once you have finished thinking about the above questions, you can begin the formal assembly.

> Note: Previously, I would incline towards asking everyone to flash the firmware into the MCU first, but here I must make a minor correction.

<br>

### Common Parts

> Note: In some photos, wired and wireless versions are used interchangeably, but it will not affect the installation.

Based on your ideal layout, first solder the diodes.

g1

<br>

Then solder all the peripheral components you will need:
  - `EC-11` or trackpad's `FFC connector`, `1/4W 4.7K resistors`.
  - Jumpers.
  - `6x3.5x4.3mm` `2 Pin` tactile switch.
  - Wireless version:
    - `MSKT-12D14` slide switch.
    - `SKRK` `2mm` tactile switch.
    - `PH2.0` female connector.

g2

<br>

Decide whether to flash the firmware first or solder it first based on the `MCU` you chose.
- `RP2040`:
  - Most versions perform the flashing action first.
  - `Sea-Picro` can be soldered and fixed first before flashing the firmware.
  - The method for flashing the firmware is generally "holding the `BOOT` button", plugging in the device, and then flashing the `uf2` firmware into it.
- `nRF52840`:
  - Solder and fix it first before flashing the firmware.
  - After connecting the device, trigger the `RST` button "`2` times" consecutively, and then flash the `uf2` firmware into it.

g3

<br>

After the `MCU` is soldered and fixed, and the firmware is flashed in, do not rush to solder the switches in the next step. You need to do a few things:
1. Confirm if your keyboard matrix is working, which means whether all your keys trigger.
  - `VIAL`'s `Matrix Tester`.
  - `ZMK Studio` — the `about-zmk-XXX` tutorial text will explain this.
  - Third-party key tester: https://hwtest.in/keyboard
2. Confirm if your modules are driving normally.
  - `EC-11` encoder.
  - Pointing device firmware operation for the trackpad.

If all the above is fine, and you are installing a trackpad, remember to unplug the FFC cable first before soldering the switches; if it is the `EC-11` encoder, just solder the switches directly.

g4
g5

> Note: The `EC-11` can be bare-tested directly without soldering, which is the operation shown in my photo illustration.

<br>

### Trackpad

#### TPS43

For the `TPS43` part, first you need to prepare the "touch surface" and "Module `D` (frame)". First, peel off the `3M` tape on the `TPS43` and combine it with the touch surface to fix it in place.

g6
g7

<br>

After installing the standoffs on the entire module, connect the FFC cable, and then fix the MCU cover plate together with the module. After that, you can install the bottom plate to finish up.

g8
g9

<br>

#### TM040040

For the `TM040040` part, you need to first assemble the main body with "Modules `A`, `B`, and `C`", and then install the standoffs to complete the entire module.

g10
g11
g12

<br>

For the installation method of the entire `TM040040` module, you must first connect the `5mm` FFC cable and then pass it through the hole.

g13

> The final completed installation diagram will be exactly in an "`S`" shape, just like in the "tutorial".



<br>

### Regarding the Battery

From here, I will explain some very important matters regarding the wireless version:

#### Li-Po Battery

The specification is marked as a `501735` `3.7V` polymer Li-Po battery. Its size limitation is based on being able to fit in the area above the `ProMicro` MCU.

g14

> Precautions: Your Li-Po battery will usually have insulation treatment like this after unboxing. After removing the insulation protection, pay special attention not to let these `2` "positive and negative" wires touch each other. This will cause your battery to purely discharge on the wires, ultimately leading to a fire. Be extremely careful when handling it.

<br>

First, you need to crimp the `PH2.0` metal terminals. Again, ensure that the "positive and negative poles" do not touch each other. Then take a multimeter, switch it to the "`20V`" setting, and directly test the "positive and negative poles" to check:
1. Whether the terminals are successfully crimped.
2. Whether the battery has power.

g15

<br>

After confirming there are no issues, electricity is conducting, and the battery has power, you can install the male connector.

g16

<br>

#### Li-Po Battery Level Display Module

Due to the lack of spare pins to implement an `LCD` battery level display, `Outsider` can only "settle for the next best thing" and use a hardware-operated display module. This little thing is very cheap to buy in online stores, easy to buy, and won't be out of stock.

g17
g18

<br>

The assembly method is very simple. There are "`+`" and "`-`" markings on the top of the display module. Solder easily identifiable wires to them respectively, and then connect them to the corresponding interfaces on the side of the PCB.

> Operation and testing method:
> 1. The slide switch must be turned on first, this is very important.
> 2. Only then can you press the tactile switch on the side. At this time, the battery level on the display module will light up.

<table>
  <tr>
    <td width="50%">
      g19
    </td>
    <td width="50%">
      g20
    </td>
  </tr>
</table>

<br>

Finally, after fixing the battery and the display module with adhesive, the installation is complete.

g21

<br>

#### Bottom Plate and Finishing Up

The final step is to install the standoffs on the bottom plate, and then fix the bottom plate together with the main keyboard body.

Then put on the keycaps, and you're done.

<table>
  <tr>
    <td width="50%">
      e1
    </td>
    <td width="50%">
      e2
    </td>
  </tr>
  <tr>
    <td width="50%">
      e3
    </td>
    <td width="50%">
      info
    </td>
  </tr>
</table>

<br>

## References

- Main Design Tools:
  - `Google Gemini` Assistance.
  - `KiCAD v9.0.0`.
  - `FreeCAD`.
- References:
  - `Rotray Encoder` `EC10E`.
  - `Rotray Encoder` `EC11`.
  - `Cirque TM040040`.
  - `TPS43`-`TPS65-201A-B`.
  - `ProMicro nrf52840`.
  - `RP2040 ProMicro`.

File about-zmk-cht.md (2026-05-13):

# ZMK Firmware 初始化環境教學

## 前言

`zmk firmware` 是客製化鍵盤圈裡最爲人熟知的無線鍵盤韌體，但一直缺少「完整」、「乾淨」的環境建制流程。爲此，我個人在初入 `zmk` 的當下，就決定要邊「執行」環境建制、然後順手寫入這個「手把手」的操作教學。

我個人非屬於韌體、硬體、電路設計等業界三大工程領域的專家，因此在接觸這種硬核的電子專案時，一定也得按照官方的操作教學，加上自己手把手除錯的嘗試，一步步將執行 `SOP` 建立起來，這才是屬於我的「開源精神」。

當然，我也會盡力讓教學寫得夠白話、夠詳細，希望本教學文本能將我熟知的「三大領域」完美融會貫通，一字不漏地交給在觀看文本的你，減少一些你對「開源客製化鍵盤」的一些失望、失落感。

——畢竟在點亮自己鍵盤的那一刻，那種興奮感是無與倫比的。

（`DreaM117er`，時間標記：`2026.05.09`）

<br>

## 關於本教學

本教學文本適用「以下」對象：
1. 完全初學者、新手小白。
2. 按照網路上其他操作教學導致電腦異常者。
3. 按照網路上其他操作教學，成功建立個人化環境，然後找不到出錯問題怎麼解決者。
4. 三大專業領域工程師。

本教學的操作環境：`Ubuntu`、`Mint`。
本教學附屬在 `Vanguard-Keyboard-Outsider` 專案底下，因此會借用到屬於該鍵盤的設計檔案——`outsider.pdf`

<br>

## qmk 及 zmk 的差異

`zmk` 的架構跟 `qmk` 完全不一樣——`qmk` 走的是「全域資料輪詢機制」，`zmk` 走的是「樹狀資料封裝發送機制」，這裡我們必須要瞭解一下不同點：
1. `qmk` 的鍵盤主控「`MCU`」會定時、按照順序向「硬體」敲門，詢問有沒有人被按下或執行。同時，你的「`Host端`」也會定時向 `MCU` 敲門索取資料。
2. `zmk` 韌體是藉由 `Zephyr RTOS` 這個工業級的即時作業系統，來將你在單一鍵盤上的操作封裝成資料發送給「`Host端`」，因此就算是分離式鍵盤，也會被視爲「單一裝置」，跟你的「藍牙耳機」連線屬於相同的道理。

> 這裡說明的「`Host端`」，通常指的是「連線或連接」要來「操作或控制」的裝置。

`Master`、`Slave`——也就是裝置的「主」、「從」關係，`qmk` 的部分可以自由選擇定義「左」或「右」；`zmk`的話預設通常都是以「哪一端透過藍牙連上電腦」做爲 `Master`。

這樣方便大家理解一下邏輯，你也會比較容易看得懂 `zmk` 官方文本的內容在寫什麼。

<br>

## 創建本地端 zmk 星系

### 何謂 zmk 星系？

1. 首先你需要準備好你的 `GitHub` 帳號，將官方的個人化設定檔 `fork` 到你的專案目錄底下（比如：`XXX-zmk-config`）
——https://github.com/zmkfirmware/unified-zmk-config-template
2. 然後操作終端機，定位到你預設的本地 `GitHub` 倉庫目錄，執行 `zmk` 的安裝流程：https://zmk.dev/docs/user-setup
3. 執行安裝流程到 `zmk init` 的時候，將 `Repository URL` 輸入你方才建立的 `XXX-zmk-config` 的 GitHub 個人化設定檔 `repo` 網址，系統會幫你設定好 `config` 目錄
4. 接著你可以選擇輸入 `Y` 取用現成的 `zmk firmware` 設定檔爲自己網購買來的鍵盤變更 `keymap` 按鍵配置。
5. 選用 `N` 的話，終端機執行 `zmk cd`，定位在預設的 `config` 資料夾目錄。

執行到這裡，我們就已經架設好「本地端」的 `zmk` 星系環境了，接下來我會讓你瞭解 `zmk` 的宇宙架構，請繼續往下看。

<br>

目前我們的 `XXX-zmk-config` 架構圖長這樣：

- `boards/shields`
    - 內部的子資料夾就是本地端的 `zmk` 星系中所有的鍵盤位置所在地，後續會說明。
- `config`
    - 資料夾設定該星系的主要規則，比如全域變數設定、藍牙發射功率、深度休眠模式等。
    - `west.yml` 檔案用於選擇你要使用什麼版本的 `zmk` 韌體進行燒錄。
    - `zmk.conf`。
- `zephyr`
    - `module.yml` 負責給予 `zephyr` 編譯系統宣告「這個星系是一個獨立的模組」。
- `build.yaml`
    - 給 `GitHub Actions`（`CI/CD`）查閱的指令腳本，定義「誰作爲誰的主控，輸出成 `.uf2` 韌體檔案」。

<br>

## 前置作業

### 安裝相依套件

如果是純新手要入坑 `zmk`，你會忽略掉非常多軟體工程的細節部分，這點也是我在撰寫文本的時候發現的，這裡一步步來將它們統整出來：

1. 終端機執行更新（不同發行版有各自的差異）：

``` bash
sudo apt update
```

2. 安裝 `Python3` 與 `pip3`：

``` bash
sudo apt install python3 python3-pip
```

3. 安裝 `west`：

``` bash
pip3 install west
```

掛載完畢之後，我們的 `XXX-zmk-config` 資料夾就會變成這樣：

dir-tree2

<br>

<br>

### 相依性套件錯誤處理

如果執行 `pip3 install west` 失敗，請按照下列方式執行：

1. 安裝虛擬環境建制工具：

``` bash
sudo apt install python3-venv
```

2. 在 `cd` 資料目錄下，建立 `zmk-env` 的隔離環境。

``` bash
python3 -m venv ~/zmk-env
```

3. 啓動隔離環境，你會發現終端機前面多了一行 `(zmk-env)`。

``` bash
source ~/zmk-env/bin/activate
```

4. 再執行一次 `pip3 install west` 指令。

> 注意事項：每次打開終端機，準備要編譯 `zmk` 前，都必須先執行 `source ~/zmk-env/bin/activate` 來啟動環境，然後才能用 `west build`。

<br>

### 燒錄工具設置

#### west.yml 設定

我想不到要用什麼作爲子標題，直白一點比較好：前述有提到「`west.yml` 檔案用於選擇你要使用什麼版本的 `zmk` 韌體進行燒錄」，我想來想去還是覺得這個部分必須在「新增新鍵盤」之前就必須完成，不然韌體檔案都設置完畢之後，你會看著自己的終端機乾等好久才能燒錄 `uf2` 韌體。

1. 執行 `zmk cd`，進入到 `config `資料夾，打開 `west.yml` 檔案，它會呈現這樣的架構：

``` yaml
manifest:
  defaults:
    revision: v0.3 # v0.3 改成 main
  remotes:
    - name: zmkfirmware
      url-base: https://github.com/zmkfirmware
    # Additional modules containing boards/shields/custom code can be listed here as well
    # See https://docs.zephyrproject.org/3.2.0/develop/west/manifest.html#projects
  projects:
    - name: zmk
      remote: zmkfirmware
      import: app/west.yml
  self:
    path: config
```

你會發現 `reversion` 預設會被掛載 `v0.3` ，這裡我們要將這個部分修改成 `main`，然後存檔後關閉。

2. 然後打開終端機，在 `zmk cd` 資料夾下，執行 `west update` 指令，來向 `zmk` 宇宙宣告我要使用 `main` 直接燒錄韌體。

``` bash
zmk cd
west update
```

第一次執行 `west update` 指令，就慢慢等 `git` 跑完它。

<br>

#### .gitignore 忽略清單

執行 `west update` 後，`west` 管理會將 `zmk` 的相依性套件直接從 `git` 倉庫全數掛載到 `XXX-zmk-config` 資料夾中，但不會幫你設定哪些檔案及資料夾是要進行過濾的，如果你硬是執行 `git push`，你會發現相依性套件都會在 `update list` 裡面，而且還會跳出警告，因爲相依性套件不是幾 `MB` 大小的檔案，而是好幾 `GB`。

1. 首先定位在 `zmk cd` 主資料夾，然後新增 `.gitignore`。

``` bash
zmk cd
touch .gitignore
```

2. 接著將 `.gitignore` 打開，把下面的資料清單複製進去，存檔後關閉。

``` .gitignore
# 基礎 west 及 zmk 忽略
.zmk/
.west/

# 忽視 west 下載的所有相依套件
/zephyr/
/zmk/
/modules/
/optional/

# 忽視本地編譯產生的垃圾與韌體檔
/build/

# 忽視 Python 虛擬環境
/zmk-env/
.venv/
```

3. 執行 `.gitignore` 忽略清單的上傳。

```
git add .gitignore
git commit -m "add .gitignore in config setting"
git push
```

清單設定完畢之後，執行 `git push` 就不會再報錯了，除非你 `compile` 一個新的韌體出來，它才會有新的檔案列在 `git` 的上傳清單內。

<br>

#### 導入 zephyr 引擎

`.gitignore` 的功能上述已經提及，這裡就不重複說明了。

`west update` 的功能呢？它的用意指「協助你將幾 `GB` 的純文字檔（原始碼）從 `GitHub` 搬到你的硬碟裡」，但它不具備轉換成韌體 `uf2` 的功能，由於 `zmk` 是基於 `Zephyr RTOS` 運作的嵌入式系統 `OS` ，我們就必須掛載它的相依性套件：
- `CMake` / `Ninja`。
- `Python` 資料庫。
- `Zephyr SDK`。

<br>

1. 確保你的終端機環境是在「可編譯」狀態下，執行「安裝 `CMake` / `Ninja`」步驟：

> 備註：`(zmk-env)`、`source ~/zmk-env/bin/activate`

``` bash
sudo apt install -y cmake ninja-build device-tree-compiler wget xz-utils
```

2. 鎖定 `XXX-zmk-config` 資料夾，執行：

``` bash
zmk cd
pip install -r zephyr/scripts/requirements.txt
```

3. 向 `CMake` 註冊 `Zephyr` 引擎路徑：

``` bash
west zephyr-export
```

4. 安裝 `Zephyr SDK`（`uf2` 編譯器）：

```bash
cd ~
wget https://github.com/zephyrproject-rtos/sdk-ng/releases/download/v0.16.5-1/zephyr-sdk-0.16.5-1_linux-x86_64.tar.xz
tar xvf zephyr-sdk-0.16.5-1_linux-x86_64.tar.xz
cd zephyr-sdk-0.16.5-1
./setup.sh -t arm-zephyr-eabi -c
```

> 注意：`setup.sh` 執行後，它會自動幫你把 `ARM` 的編譯器設定好，這專門用來對付 `nRF52840` 晶片。

#### 韌體編譯

5. 這樣一來，整個 `zmk` 宇宙及編譯環境就全數掛載完畢了，如果你後續要製作 `uf2` 韌體，就必須將資料夾鎖定在 `XXX-zmk-config` 目錄下的 `zmk/app` 子目錄下。

``` bash
zmk cd
cd zmk/app
```

然後再執行 `west build` 指令：

``` bash
west build -p -b nice_nano -- -DSHIELD=<custom_keyboard> -DZMK_CONFIG="[你的 XXX-zmk-config 資料夾路徑]"
```

> 超級重要：系統就會將 `uf2` 韌體建制在 `~/XXX-zmk-config/zmk/app/build/zephyr` 資料夾內部，一個叫做 `zmk.uf2` 的檔案。

<br>

## 教學開始

### A. 行星誕生

前述我們將 `zmk` 的星系開拓完且所有的前置誰設定都設置完畢後，這個 `zmk` 星系現在非常地乾淨，什麼都沒有，我們需要在這個星系裡誕生新的「行星」，這也對應著上述「何謂 zmk 星系？」 第`4-5` 點的操作方法：
- 現成的 `zmk` 宇宙設定，雲端導入到你的電腦（星系）進行配置修改。
- 從 `0` 開始創建一個「新的鍵盤」（在星系裡創建行星）。

這裡我不討論導入雲端設定的部分，著重點在於「新的鍵盤」。

<br>

1. 執行 `zmk cd`，接著在目錄底下執行：

``` bash
cd boards/shields
mkdir <custom_keyboard>
touch Kconfig.shield <custom_keyboard>.overlay <custom_keyboard>.keymap <custom_keyboard>.conf
```

> 先創建「行星（`dir`）」、「旗標（`Kconfig`）」、「運作核心（`.overlay`）」、「功能核心（`.keymap`）」、「藍牙設定（`.conf`）」檔。

2. 然後將 `Kconfig.shield` 打開，寫入代碼後存檔：

``` markdown
config SHIELD_CUSTOM_KEYBOARD
    def_bool $(shields_list_contains,<custom_keyboard>)
```

寫入這串代碼的用意在：你要告訴你的 `zmk` 宇宙環境下，誕生了這把 `custom_keyboard` 鍵盤。

> 光是創建檔案沒有用，你的 `Kconfig.shield` 檔案裡沒有東西，你要怎麼告訴宇宙「這把鍵盤」存在在這裡呢？

<br>

### B. 運作核心及功能設置

設定好鍵盤的「旗標」，接著才會依序創建「運作核心」及「功能核心」，也就是要先定義好你的鍵盤是使用什麼方式驅動 `zmk` 韌體，後續才會將鍵盤的功能一步步建立起來。

目前應該不用特別說明驅動方式，也就 2 種：
- 開發板驅動（例如：`PICO-W` 或 `SEED XIAO-BLE` 系列）。
- `MOB` 驅動（`MCU on board`）。

這裡我會介紹常用的開發板驅動，也就是 `nRF52840` 晶片的開發板（含 `nice!nano v2`）做範例介紹，首先我們需要準備幾樣東西：
1. 開發板本體。
2. 開發板規格書及腳位定義表。
3. 鍵盤電路板原理圖（`PDF` 檔案或設計圖 ）。
4. 實際鍵盤矩陣圖（`KLE` 或設計圖）。

<br>

#### 開發板本體、規格書及腳位定義表

<table>
  <tr>
    <td width="50%">
      rp2040
    </td>
    <td width="50%">
      nRF52840
    </td>
  </tr>
</table>

標準使用 `ProMicro` 腳位的開發板，假設要開發無線有線共用的電路板（`PCB`）的話，那麼一定會用到這個腳位圖，這裡是這兩張圖最常用到的幾個功能：
- 對照正面、背面的 `GPIO` 分佈。
- 全域對照各個 `GPIO` 有什麼功能。

> 特別注意「電壓（`VCC`）」跟「接地（`GND`）」的位置及大小值，這個在電路設計裡面相當重要，用錯設計方法，可是會損壞你的開發板跟電路板的。

> `nice!nano v2` 跟 `clones` 的差異最大體現在「`VCC`」的大小，我記得沒錯的話，早期的 `nice!nano` 開發板 `VCC` 輸出是 `4.3V`，不是 `3V3`。

電路設計裡面幾個很簡單的概念讓大家知道一下：
- 輸出電壓不對就會罷工，或是燒掉。
- 線沒接對就會罷工，或是燒掉。

> 不正確 = 罷工 or 燒掉。

就是這麼簡單。

<br>

雖然這裡我們不討論 `RP2040 ProMicro` 開發板，但還是要跟大家說明一下「爲什麼」我要放有線鍵盤的開發板出來？
1. 你要知道 `VCC`、`GND` 的實際物理位置及電壓值。
2. 相同的 `I2C` 通訊頻道位在哪一個 `GPIO` 上，比如 `I2C0` `SDA`/`SCL` 的位置在 `GP0-1` 上。
3. 同上，`SPI` 通訊腳位位於哪一些 `GPIO` 上，走 `SPI` 頻道可是會花上更多的 `GPIO` 來處理通訊資料。

> 你要拿著有線開發板的 `GPIO` 腳位去對照 `nRF52840 ProMicro` 開發板的腳位是不是有功能的「交集」，然後把該腳位優先提取出來做佈線設計。

`nRF52840 ProMicro` 及 `nice!nano v2` 的腳位及功能都是採用相同的設計方式（使用元件不同）：
- 輸出電壓 `3V3`，`GND` 位置跟 `RP2040 ProMicro` 一樣。

> 非常重要：全功能腳位都能輸出 `I2C` 通訊。雖然全功能皆可，但建議優先使用開發板預設標示的 `SDA/SCL` 腳位，以減少軟體定義的麻煩。

> 非常重要：`RAW` 爲電池「正極」的接口。

<br>

#### 電路板原理圖及實際矩陣圖

<table>
  <tr>
    <td width="50%">
      layout
    </td>
    <td width="50%">
      mcu-ki
    </td>
  </tr>
   <tr>
    <td width="50%">
      matrix-ki
    </td>
    <td width="50%">
      matrix-ki2
    </td>
  </tr>
</table>

這裡先說明兩個很常見的誤區：
1. 矩陣大小「不等於」實際矩陣圖。
2. 理想矩陣配置「不等於」實際矩陣配置。

拿範例的 `Outsider` 鍵盤來說，標準 `Plank` 配置的鍵盤矩陣大小是 `4x12`，我的設計多了一顆懸浮按鍵（音量旋鈕 `EC-11`），因此總按鍵數量是 `49` 顆。
- 理想的矩陣佈線圖一定會是 `4x12`，這很合理對吧。
- 實際上我設計了 `8x8` 的矩陣，合計 `64` 顆按鍵，比 `7x7` 矩陣還要好設計，也方便擴充跟佈線。

這樣應該能理解爲什麼了吧？

<br>

#### 寫入運作核心及功能設置 

原理圖及矩陣圖不管是 `qmk` 還是 `zmk` 韌體裡，在寫入配置的時候都相當重要，因爲你要實際去對照「你的設計」，去一個個寫入它應該要有的功能。

1. 首先我們打開 `<custom_keyboard>.overlay`，`Outsider` 的範例在下方，你可以根據註解去修改你的鍵盤 `.overlay` 檔案。

``` c
#include <dt-bindings/zmk/matrix_transform.h>

/ {
    chosen {
        zmk,kscan = &kscan0;
        zmk,matrix_transform = &default_transform;
    };

    /* 開發板設定 */
    kscan0: kscan_0 {
        compatible = "zmk,kscan-gpio-matrix";
        label = "KSCAN";
        diode-direction = "col2row"; /* 根據鍵盤的二極體方向設置 */

        /* 矩陣 Columns 腳位設定 */
        col-gpios
            = <&pro_micro 10 GPIO_ACTIVE_HIGH> /* col0: PB6 */
            , <&pro_micro 16 GPIO_ACTIVE_HIGH> /* col1: PB2 */
            , <&pro_micro 14 GPIO_ACTIVE_HIGH> /* col2: PB3 */
            , <&pro_micro 15 GPIO_ACTIVE_HIGH> /* col3: PB1 */
            , <&pro_micro 18 GPIO_ACTIVE_HIGH> /* col4: PF7 (A0) */
            , <&pro_micro 19 GPIO_ACTIVE_HIGH> /* col5: PF6 (A1) */
            , <&pro_micro 20 GPIO_ACTIVE_HIGH> /* col6: PF5 (A2) */
            , <&pro_micro 21 GPIO_ACTIVE_HIGH> /* col7: PF4 (A3) */
            ;

        /* 矩陣 Rows 腳位設定 */
        row-gpios
            = <&pro_micro 9 (GPIO_ACTIVE_HIGH | GPIO_PULL_DOWN)> /* row0: PB5 */
            , <&pro_micro 7 (GPIO_ACTIVE_HIGH | GPIO_PULL_DOWN)> /* row1: PE6 */
            , <&pro_micro 4 (GPIO_ACTIVE_HIGH | GPIO_PULL_DOWN)> /* row2: PD4 */
            , <&pro_micro 1 (GPIO_ACTIVE_HIGH | GPIO_PULL_DOWN)> /* row3: PD2 */
            , <&pro_micro 8 (GPIO_ACTIVE_HIGH | GPIO_PULL_DOWN)> /* row4: PB4 */
            , <&pro_micro 6 (GPIO_ACTIVE_HIGH | GPIO_PULL_DOWN)> /* row5: PD7 */
            , <&pro_micro 5 (GPIO_ACTIVE_HIGH | GPIO_PULL_DOWN)> /* row6: PC6 */
            , <&pro_micro 0 (GPIO_ACTIVE_HIGH | GPIO_PULL_DOWN)> /* row7: PD3 */
            ;
    };

    /* 矩陣大小設定 */
    default_transform: keymap_transform_0 {
        compatible = "zmk,matrix-transform";
        /* 定義矩陣大小 */
        columns = <8>;
        rows = <8>;
        map = <
            /* 實際矩陣大小 */
            RC(0,0) RC(4,0) RC(0,1) RC(4,1) RC(0,2) RC(4,2) RC(0,3) RC(4,3) RC(0,4) RC(4,4) RC(0,5) RC(4,5)
            RC(1,0) RC(5,0) RC(1,1) RC(5,1) RC(1,2) RC(5,2) RC(1,3) RC(5,3) RC(1,4) RC(5,4) RC(1,5) RC(5,5)
            RC(2,0) RC(6,0) RC(2,1) RC(6,1) RC(2,2) RC(6,2) RC(2,3) RC(6,3) RC(2,4) RC(6,4) RC(2,5) RC(6,5)
            RC(3,0) RC(7,0) RC(3,1) RC(7,1) RC(3,2) RC(7,2) RC(3,3) RC(7,3) RC(3,4) RC(7,4) RC(3,5) RC(7,5) RC(7,7)
        >;
        /* RC()格式說明：R = Row; C = Col; 合併代碼 = RC(A, B) */
    };
};
```

> 這個部分是設置你的硬體運作核心，因此你要在 `.overlay` 檔案裡設置，開發板上的每一個腳位定義核心功能「旗標」、「定義矩陣大小」及「實際矩陣大小」。

然後設定好「運作核心」之後，才會來設定「功能核心」——也就是你的實際矩陣中的各個按鍵上「有什麼功能」。

> 補充說明：`zmk` 針對 `ProMicro` 腳位的開發板有一套專屬的腳位定義表，這裡請參照官方說明文本的頁面——https://zmk.dev/docs/troubleshooting/hardware-issues

ProMicro pinout

<br>
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

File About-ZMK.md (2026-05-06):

# ZMK Firmware初始化環境教學

## 前言

`zmk firmware` 是客製化鍵盤圈裡最爲人熟知的無線鍵盤韌體，但一直缺少「完整」、「乾淨」的環境建制流程。爲此，我個人在初入 `zmk` 的當下，就決定要邊「執行」環境建制、然後順手寫入這個「手把手」的操作教學。

我個人非屬於韌體、硬體、電路設計等業界三大工程領域的專家，因此在接觸這種硬核的電子專案時，一定也得按照官方的操作教學，加上自己手把手除錯的嘗試，一步步將執行 SOP 建立起來，這才是屬於我的「開源精神」。

當然，我也會盡力讓教學寫得夠白話、夠詳細，希望本教學文本能將我熟知的「三大領域」完美融會貫通，一字不漏地交給在觀看文本的你，減少一些你對「開源客製化鍵盤」的一些失望、失落感。

——在點亮自己鍵盤的那一刻，那種興奮感是無與倫比的。

<br>

## 關於本教學

本教學文本適用「以下」對象：
1. 完全初學者、新手小白。
2. 按照網路上其他操作教學導致電腦異常者。
3. 按照網路上其他操作教學，成功建立個人化環境，然後找不到出錯問題怎麼解決者。
4. 三大專業領域工程師。

本教學的操作環境：`Ubuntu`、`Mint`。
本教學附屬在 `Vanguard-Keyboard-Outsider` 專案底下，因此會借用到屬於該鍵盤的設計檔案——`outsider.pdf`

<br>

## qmk 及 zmk 的差異

`zmk` 的架構跟 `qmk` 完全不一樣——`qmk` 走的是「全域資料輪詢機制」，`zmk` 走的是「樹狀資料封裝發送機制」，這裡我們必須要瞭解一下不同點：
1. `qmk` 的鍵盤主控「`MCU`」會定時、按照順序向「硬體」敲門，詢問有沒有人被按下或執行。同時，你的「`Host端`」也會定時向 `MCU` 敲門索取資料。
2. `zmk` 韌體是藉由 `Zephyr RTOS` 這個工業級的即時作業系統，來將你在單一鍵盤上的操作封裝成資料發送給「`Host端`」，因此就算是分離式鍵盤，也會被視爲「單一裝置」，跟你的「藍牙耳機」連線屬於相同的道理。

> 這裡說明的「`Host端`」，通常指的是「連線或連接」要來「操作或控制」的裝置。

`Master`、`Slave`——也就是裝置的「主」、「從」關係，`qmk` 的部分可以自由選擇定義「左」或「右」；`zmk`的話預設通常都是以「哪一端透過藍牙連上電腦」做爲 `Master`。

這樣方便大家理解一下邏輯，你也會比較容易看得懂 `zmk` 官方文本的內容在寫什麼。

<br>

## 教學開始

### A. 創建本地端 zmk 星系

1. 首先你需要準備好你的 GitHub 帳號，將官方的個人化設定檔 `fork` 到你的專案目錄底下（比如：`XXX-zmk-config`）
——https://github.com/zmkfirmware/unified-zmk-config-template
2. 然後操作終端機，定位到你預設的本地 GitHub 倉庫目錄，執行 `zmk` 的安裝流程：https://zmk.dev/docs/user-setup
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

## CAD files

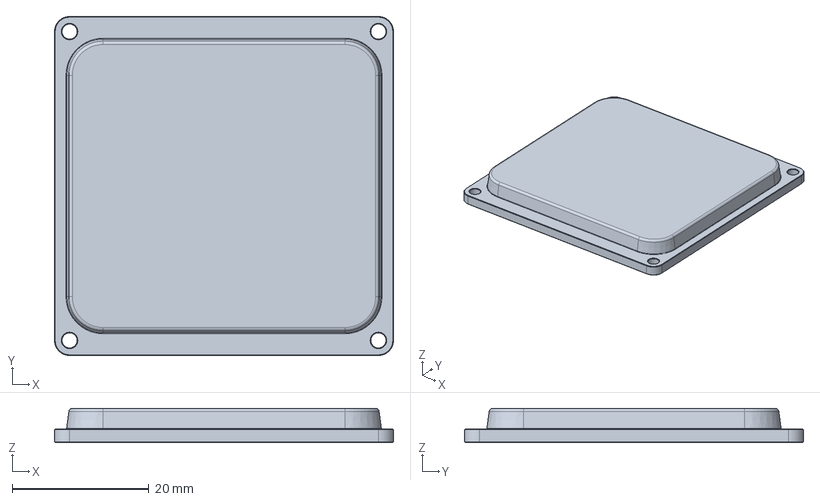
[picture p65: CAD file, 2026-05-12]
file/3d/TPS-tapcover.step
49.5 x 49.5 x 5.00 mm

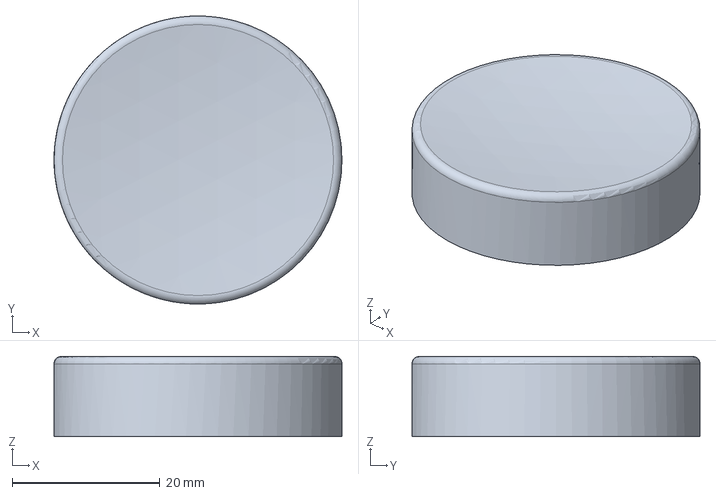
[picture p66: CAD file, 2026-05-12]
file/3d/39mm_h4.5mm_ec11_hat.step
39.0 x 39.0 x 10.8 mm

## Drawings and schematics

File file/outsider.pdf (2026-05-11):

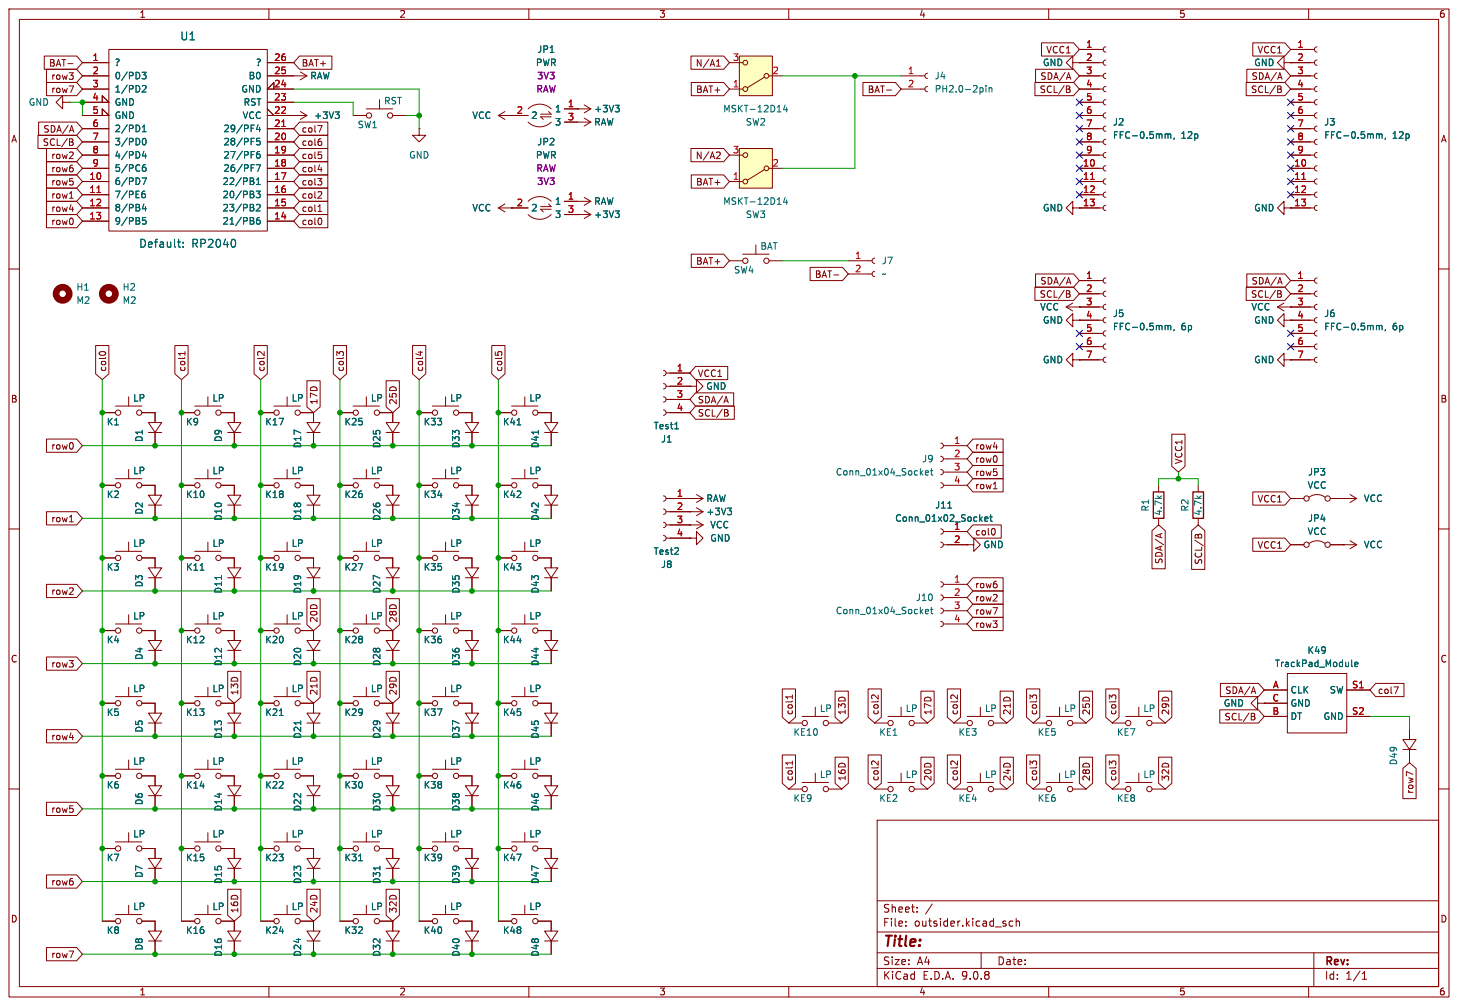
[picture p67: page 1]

Id: 1/1 Title: File: outsider.kicad_sch Sheet: / K48

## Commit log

2026-05-11 add pcb v1 file
    [outsider.kicad_sch]
2026-05-12 add module&3d
    [39mm_h4.5mm_ec11_hat.step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]
2026-05-12 add case
    [bottom.kicad_pcb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]
